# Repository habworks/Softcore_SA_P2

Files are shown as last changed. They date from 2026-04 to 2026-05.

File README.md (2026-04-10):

# SoftCore SA Phase 2

A complete Signal and Audio Spectrum Analyzer Project design based on the Xilinx Artix A7 FPGA.<br>
FPGA, Hardware and Firmware 100% designed by:<br>
Hab Collector<br>
Principal Engineer<br>
IMR Engineering, LLC<br>

## Quick Links to IMR Cloud:
See [Video Demo](https://imrengineeringcom-my.sharepoint.com/:v:/g/personal/hab_collector_imrengineering_com/IQCNRXcKcpunQ4q-7LwDUr22AYgADxUZiHp8gwkplrM7jkg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) from IMR Cloud<br>
See [FPGA PL Block Diagram](https://imrengineeringcom-my.sharepoint.com/:b:/g/personal/hab_collector_imrengineering_com/IQCsjQ4P0sn3SLZj1Wicb67OAVSCE_0235o4riHvLBb0ygI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) from IMR Cloud<br>
See [User Manual & Technical Specification](https://imrengineeringcom-my.sharepoint.com/:b:/g/personal/hab_collector_imrengineering_com/IQB8uARxVN-PTYQCG0TAuSPwAWNce-_PQCCQfAmf1itzjjY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) from IMR Cloud<br>
See [Schematics PCB and BOM](https://imrengineeringcom-my.sharepoint.com/:b:/g/personal/hab_collector_imrengineering_com/IQB8uARxVN-PTYQCG0TAuSPwAWNce-_PQCCQfAmf1itzjjY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) from IMR Cloud<br>

## Project Folders:

| Folder | Description |
|---|---|
| Audio | PCM-16 files used for audio spectrum playback|
| Bootloader_Softcore_SA | Firmware Project Bootloader|
| Documents | UMTS, Images, and reference material|
| FPGA_RTL_IP | Custom RTL IP created in Verilog for this project|
| Hardware | Hardware Design in Circuit Studio: Schematics, PCB, BOM|
| PL_Softcore_SA | Processor Logic Vivado Project Files|
| PS_Softcore_SA | Application Firmware|
| Simulation | Spice Modle Simulation (LT Spice)|

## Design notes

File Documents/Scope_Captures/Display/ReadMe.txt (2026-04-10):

tek00042.png

SPI Display Interface
Clk = 10MHz
CS
Clk
MOSI
Reset
Data/Command (Data High)
Typical screen buffer write 3.77ms

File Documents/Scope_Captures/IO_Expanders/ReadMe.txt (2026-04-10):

tek00036.png
This shows typical IO 1 Expander write in this capture LED7 U1.16 GP6 is driven high

tek00037.png
This shows the output latch being updated IOX 1

tek00041.png
Shows IO X generating an interrupt on a UI pushbutton SW2 and the corresponding read of the interrupt register

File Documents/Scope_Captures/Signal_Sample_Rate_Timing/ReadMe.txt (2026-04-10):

Sequence of events flows from top to bottom CH2 then CH1 then CH3 then CH4

CH 1 PL Timer 1 Interrupt goes active - it is cleared by the corresponding ISR
CH 2 PS Shows ISR response to PL Timer IRQ when it starts (high) and when it is completed (low) - part of what it does is start a single conversion cycle
CH 3 PL Shows the ADC 7476A x2 IRQ go active - it is cleared by the corresponding ISR
CH 4 PS Shows the ISR resonse to the PL ADC 7476A x2 IRQ when it starts (high) and when it is completed (low) - By the end of this you have started an ADC cycle and read the result

Cursor: The cursor shows how long the entire process takes and ultimately how fast a sample rate the current architecture can handle 74KHz but with some breathing room I use 50KHz
for the this architecture, but quite possible to use up to maybe 70KHz - but did not test.

the system architecture would have to change to get faster sample rate

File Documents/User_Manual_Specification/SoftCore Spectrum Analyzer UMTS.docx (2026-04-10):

SOFTCORE SPECTRUM ANALYZER

IMR Engineering, LLC

Ideas Made Real

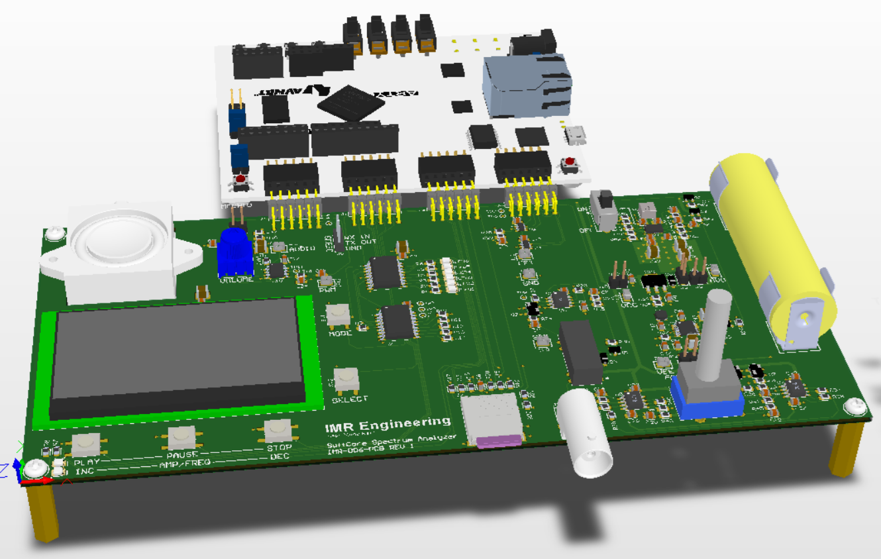
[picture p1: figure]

USER MANUAL AND TECHNICAL SPECIFICATION

Principal Engineer: Hab Collector

http://imrengineering.com

DOCUMENT REVISION HISTORY
DATE | DESCRIPTION | EDIT BY
2026-03-06 | Initial draft - Preliminary | HSC
2026-03-14 | Updated formatting and sample jitter | HSC
2026-03-23 | Final edits before publishing P1 content | HSC

# 1. INTRODUCTION:

## 1.1 THE CHALLENGE:

For many applications the microcontroller (µC) architecture provides an excellent balance of performance, cost, and manageable development complexity. It is therefore natural to ask an important engineering question: where does a pure Processor Logic (PL) based FPGA system fit into this landscape?

In comparison there is nothing easy, cheap or quick about an FPGA. The FPGA simply cannot compete in those categories, but for everything else it excels. The challenge explored in this project is not a feature-for-feature comparison between an FPGA and a µC. Instead, the goal is to explore the practical capabilities of a pure PL FPGA platform by implementing two distinct design projects and observing how such a system compares in practice to what might traditionally be implemented on an ARM Cortex M4/M7 class device or higher.

The first phase (P1) of this exploration focuses on constructing an FPGA-based system that resembles the functional architecture commonly found in a µC environment. Within the PL, a subset of needed peripherals are implemented which include: UART, SPI, DDR3, Timers, PWM, Interrupt Controller, FPU, Cache memory and other system services required to support a complete embedded application. The resulting system demonstrates that the fundamental building blocks normally associated with a µC can be tailored specifically to create the device needed. That said, incorporated into this first phase a preview of what lies ahead through the inclusion of two custom RTL-based IP blocks (aka modules) – something you cannot do within a µC along with a few other FPGA differentiators.

## 1.2 PHASE 1 / PHASE 2:

What is covered here is the P1 project design: PL, Hardware, and Firmware. In doing so I will show performance and limitations thereof, things I got wrong, and issues in hardware, firmware, and PL I intend to correct, and or, address in Phase 2.

## 1.3 SO WHAT IS IT:

A dual mode Spectrum Analyzer (SA) implemented around the MicroBlaze Softcore IP processor running on the AMD (aka Xilinx) XC7A100T-1CSG324-1 FPGA. As this FPGA is pure PL there is no PS (Processor System) as in the case of SoC based FPGAs. The system architecture recreates many of the services typically found in a microcontroller environment while remaining entirely within the FPGA PL fabric. The user interface is intentionally simple, and hardware driven, consisting of five multi-function push buttons and a monochrome 128x64 graphical display used for system control and visualization. The device operates as a compact, self-contained instrument designed to demonstrate real-time spectral analysis. The project currently supports two modes of operation: Audio SA (referenced in FW as Audio_SA) and Signal SA (referenced in FW as Signal_SA). Audio Mode displays the spectral content and signal strength of a WAV audio file played from µSD. Signal Mode mimics the behavior of a desktop Spectrum Analyzer.

# 2. AT A GLANCE:

## 2.1 PL FEATURES:

- MicroBlaze Softcore:

64KB / 32KB of Instruction / Data Cache, FPU and 128KB of LBM

- 3x Timers (two with interrupts)
- PWM
- 1x SPI shared to 3x devices: 2x IO Expanders and 1x SSD1309 Display
- 1x SPI dedicated to µSDB
- 1x SPI dedicated to 16MB QUAD SPI Boot Flash – Bootloader use only
- UART
- DDR3 Interface to external 128Mx16 (MT41K128M16XX-15E)
- 11x GPIO Outputs
- 12x GPIO Inputs
- Custom RTL Revision IP
- Custom RTL ADC Interface IP
- Interrupt Controller with 3x Fast Interrupts
- System Bus Interconnect

## 2.2 HW FEATURES:

- IO Expander to LED outputs
- IO Expander to UI push button Inputs
- Micro-SD
- 128x64 2.42” OLED Display
- Dual 12b 1MSPS ADC
- Anti-Aliasing Sallen Key LPF
- Selectable Analog inputs to Signal SA
- Local Variable Oscillator 4.4K to 48.2KHz
- Class AB Audio Amplifier
- Single Li-ION cell operation
- Interface to Digilent Arty A7 Development board

## 2.3 FW FEATURES:

- Bear Metal Application
- Middleware: FAT FS Library
- Middleware: U8G2 Graphics Library
- Middleware: KISS FFT Library
- Two modes of operation: Audio and Signal

## 2.4 SIMPLIFIED BLOCK DIAGRAM

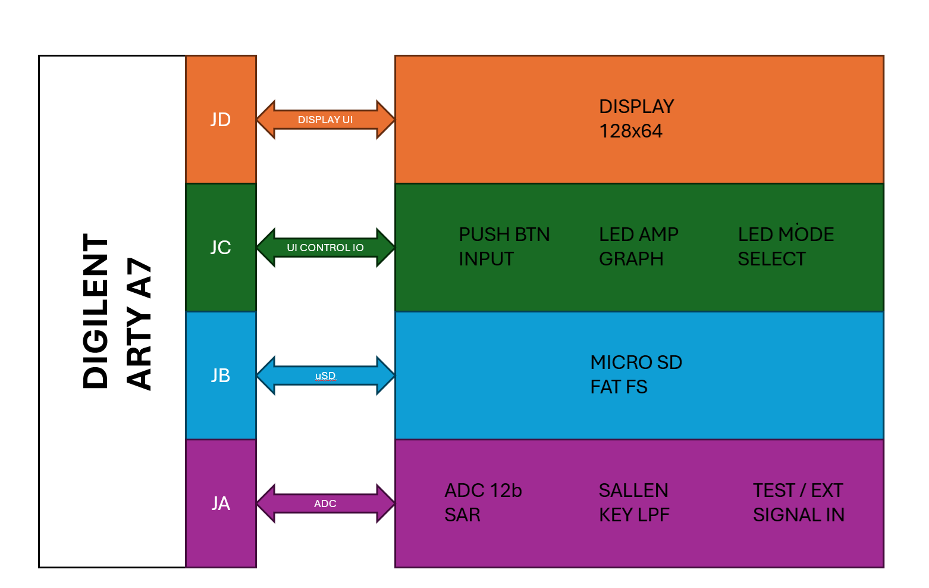
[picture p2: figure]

# 3. PROJECT SCOPE:

When creating a two-part project of such hardware and firmware complexity, as a one-person show, limiting scope is necessary to ensure time, budget and project momentum are kept.

## 3.1 P1 FIRMWARE SCOPE:

For firmware I decided to implement a bear-metal application rather than an RTOS. It limited FW complexity for one, but it also availed the processor of the memory and processing time needed to support an RTOS. The choice of KISS FFT pre-existing library was also necessary as a custom FFT library would be a project on to itself.

## 3.2 P1 HARDWARE SCOPE:

The complexity of layout for a DDR3 memory and the layer count associated with such a design from a cost and time perspective made the choice of using the off-the-shelf Digilent Arty A7 Development Board an easy one. Having designed both FPGAs and DDR3 memories before I knew ahead of time I was looking at 3 revisions of a 6 layer PCB. More so, I have chosen not to extend my Altium license moving forward, the need for trace impedances and serpentine routing neither of which is supported by Circuit Studio (development tool used). For the same reasons the choice of a simple display was made over an RGB color model.

# 4. DETAILED MODES OF OPERATION:

- Audio Spectrum
- Signal Spectrum

## 4.1 AUDIO SA MODE DETAILS:

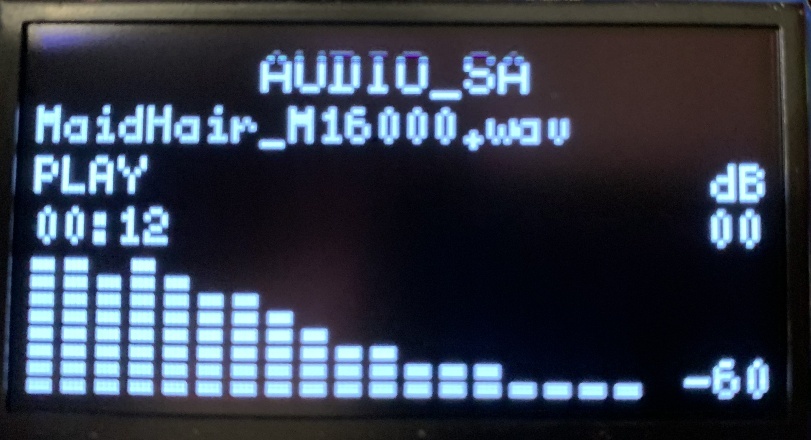
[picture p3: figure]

In Audio SA mode the system operates as a real-time audio playback and spectral display instrument. Audio content is read from a WAV file stored on the µSD card using the FAT FS middleware. Once the file header is parsed and verified, audio sample data is moved from storage into a large streaming circular buffer sized at 22K samples / 44KB (int16_t data). This large, main buffer exists to reduce the frequency of µSD card read operations and to provide margin against storage access latency. For this streaming buffer the system fills a smaller, secondary 4KB feed buffer which serves to replenish the larger buffer. In this way the buffering scheme is staged: mass storage feeds the main streaming buffer on start, thereafter the main buffer is feed from the secondary buffer as space becomes available, as the main buffer supports both playback and FFT processing (FFT is processed by the KISS FFT middleware). The buffer is sized to support a max audio sample of 22050Hz playback. It could have been sized larger, but I choose to limit the size here, with planned use of that memory in phase 2. Additionally, six colored LEDs (arranged as a bar) display the magnitude (signal strength no signal spectrum) of the playback from -30dB to -10dB in -4dB increments. Both the spectral display and the signal strength LED bar will provide a visual interpretation of the payback audio.

Playback timing is controlled by a timer interrupt service routine (ISR) configured to run at the audio playback sample rate. For a playback rate of 16KHz, the ISR period is:

T_(sample) =1/16000=62.5 μs This means one audio sample is processed every 62.5µs. As playback proceeds, samples are simultaneously routed to the PWM audio output path and copied into the FFT sample buffer. The FFT sample buffer contains 1024 samples, therefore the time required to fully populate at 16KHz playback is:

T_(FFT Fill) =N/(Fs)=(1024/16000)= 64 ms

Thus, under continuous playback, a new 1024-point FFT frame becomes available every 64ms. This corresponds to an FFT update rate of:

1/0.064=15.625 Hz or approximately 15.6Hz spectral updates per second. As an additional reference, the 4KB feed buffer holds 4096 bytes. For 16-bit PCM audio, each sample is 2 bytes, giving:

4096/2=2048 samples At 16KHz playback this secondary buffer represents:

2048/16000=128 ms of mono audio data. Likewise, the 44KB streaming buffer holds:

44056/2=22528 samples

which at 16KHz corresponds to:

22528/16000=1.408 s

or about 1.4 seconds of mono playback data. These staged buffer depths are what allow playback, storage access, and FFT processing to coexist with acceptable continuity.

Interrupt handling is a significant part of the design – its importance cannot be overstated for this project. As such I take a moment to expand upon it here. Both modes rely heavily on the sample rate interrupt timer (AXI Timer 1). The MicroBlaze is capable of normal and low latency (fast) interrupts. Normal interrupts use the AXI interrupt controller and are decoded, prioritized and vectored to the processor. Normal interrupts take about 40 cycles between detection to ISR jump. Fast interrupts bypass the interrupt controller and connect directly to the MicroBlaze. Subsequently fast interrupts are processed within about 10 cycles, generally speaking, on par with ARM Cortex M4/M7. That said, most M4 and M7 designs clock in excess of 100MHz, so the actual time from detection to ISR jump and ISR processing is less. Part of the interrupt mechanism is architectural, and part is simply clock speed (cycle time): The P1 design runs at 100MHz. In P2 I will attempt to run the same design to 150MHz. A difference with a distinction. While µCs are typically specified with a fixed max clock speed, FPGAs come in speed grades -1, -2, -3 (slow, faster, fastest). Generally speaking, the speed grade represents a “possible” range of the max fabric clock frequency. At speed grade 1 it maybe possible to get a max of 200MHz. If this is repeatable across devices will be device and design dependent. That said, 100MHz is just a known starting point. Nesting, the MicroBlaze interrupt controller does not support a true nested interrupt model where one interrupt preempts another already in service, though it does support interrupt priority (fixed in the PL design). In this project that reality strongly influenced the overall firmware architecture, the selected FFT size, and the balance between playback, analysis, and display update rate. Lastly, all ISR are placed in (Local Block Memory) LBM (FPGA block RAM directly attached to the MicroBlaze – runs exceptionally fast) and not within DDR3 space. The overall size of the application dictates that most of it runs from DDR space, targeting LBM for specific use where speed is paramount. Another distinction here is the FPGA application runs (mostly) from DDR and LBM memory, whereas with the µC the application runs from FLASH. The FPGA requires a far more complex linker – the reader is encouraged to review the application linker file (lscript.ld) with the Virtual Address Memory (VAM) and Local Address Memory (LAM) and how its loaded at run-time.

## 4.2 SIGNAL SA MODE DETAILS:

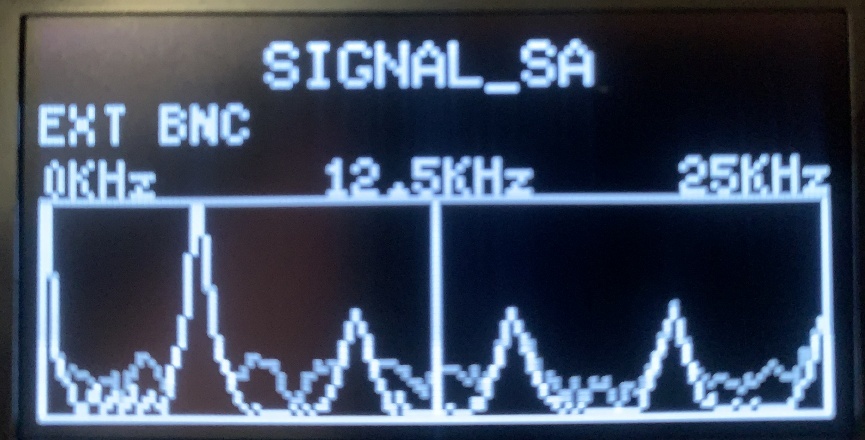
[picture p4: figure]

In this configuration the instrument functions as a traditional Spectrum Analyzer by converting incoming time-domain signals into its frequency-domain representation. While the sampling data differs from Audio SA mode, the spectral analysis engine remains fundamentally the same. Both modes leverage the same FFT algorithm and the same 1024 samples per frame,

Signal acquisition is a two interrupt event. It begins with the sample-rate timer interrupt. Each timer interrupt event initiates the sampling sequence by triggering the custom ADC RTL IP to perform an ADC conversion. The ADC IP implemented in PL controls the timing of the conversion and provides the resulting digital sample to the firmware via a fast interrupt (the second). Within the ISR the sample is transferred into the FFT sample buffer, where samples are accumulated until the frame buffer (1024 samples) is full.

Once the frame is complete, the spectral processing routine is executed. During this time the Timer ISR is suspended. The resulting magnitude values represent the spectral energy distribution of the input signal and are mapped to the display. Once the display has been updated the ISR is resumed.

Input signals can originate from two sources. The onboard, variable Wien Bridge Oscillator (aka local oscillator - 4.4KHz to 48.2KHz) or via an external BNC connection. As with Audio SA mode, the entire signal acquisition and analysis pipeline is driven by the timer interrupt architecture. The interrupt establishes the sampling cadence, triggers ADC conversion, and governs the rate at which samples are collected for FFT processing. Consequently, the overall performance and responsiveness of the Signal SA system are fundamentally driven and limited by the ISR-based architecture.

Below shows the timing interactions:

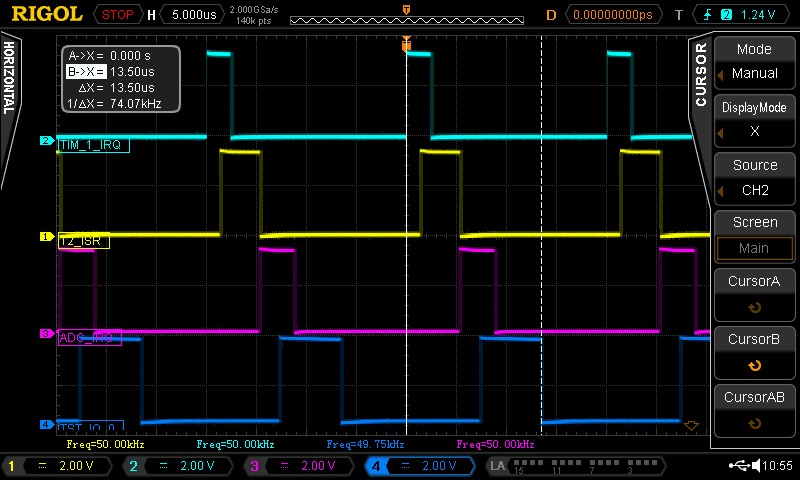
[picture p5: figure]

NOTES:
CH2 - TIM_1_IRQ: Timer 1 IP IRQ

CH1 - T2_ISR:

Timer 1 ISR handler (inniates Custom RTL ADC conversion)

CH3 - ADC_IRQ: Custom RTL ADC conversion complete IRQ

CH4 – TEST_IO_0: ADC IRQ ISR complete (the sample has been captured)

Cursor Marking: Shows the max frequency possible for sampling about 74KHz – choose 50KHz for sampling frequency.

As the above timing analysis shows the max sample rate possible using this architecture resolves to an absolute maximum of 70KHz (allowing some wiggle room from the 74KHz). With the 100KHz out of reach for phase 1 I settled on a sample rate of 50KHz, which implies a usable frequency BW of 25KHz. Note the local Wien Bridge Oscillator variable range was designed to be the intended 100KHz sample rate and 50KHz BW (4.5KHz to 48.2KHz).

# 5. FFT IMPLEMENTATION AND NEED TO KNOW:

## 5.1 FFT PROCESS FLOW:

In essence the FFT categorizes the sampled time-domain signal into spectral energy between the baseband and the Nyquist. Because the FFT works on a finite number of samples (frame), the result is always tied to one snapshot in time. In this design, that snapshot is 1024 samples. Every time that frame becomes available the FFT is processed and can subsequently be displayed.

## 5.2 WHAT CAN BE MEASURED:

The system takes 50,000 equally spaced samples every second. That sample rate creates a hard upper limit on what can be correctly processed by the FFT. As the Nyquist is 25KHz, spectral content above 25KHz represents an aliasing error. Higher frequency content feeding into the ADC folds back into the measure band and appears as an incorrect lower frequency – the aliasing effect. The intent was for the anti-aliasing filter to reject said frequencies. That said, the ADC front end Sallen-Key LPF was designed for this purpose with a BW of 330KHz. At the time, the expectation was that the local Wien Bridge Oscillator would be “clean” and the 330KHz (-40dB/decade roll-off) would allow for some limited Phase 2 development on the same Phase 1 hardware platform. I was wrong about the local oscillator being clean. Another thing I failed to realize at the time was that harmonic content beyond the BW limit would also alias back. The aliasing error follows the form:

Fa=abs(Fin-kFs)

Fa: Alias frequency

Fin: Input frequency

Fs: Sample frequency

k: Integer multiple until Fa falls in the Nyquist band

Observed Example of Alias Content 1:

Fin = 120KHz

Abs(120KHz – (1)(50KHz)) = 70KHz (not within Nyquist so will not be displayed

Abs(120KHz – (2)(50KHz)) = 20KHz within Nyquist so it will be displayed

Observed Example of Alias Example 2:

Fin = 90KHz

Abs(90KHz – (1)(50KHz)) = 40KHz (not within Nyquist so will not be displayed

Abs(90KHz – (2)(50KHz)) = 10KHz within Nyquist so it will be displayed

Observed Example of Alias Example 3:

Fin = 35KHz

Abs(35KHz – (1)(50KHz)) = 15KHz within Nyquist so it will be displayed

Lastly, it is important to understand that the alias frequency is NOT an error of the FFT, but rather a limitation of the front-end anti-aliasing filter, which at its high -3dB limit does not reject frequencies above the implemented sampling rate. As can be seen from the spectral plots below, the local oscillator created spectral energy beyond both the implemented and (initially) intended sample rate. That energy is believed to have been caused by the clipping diodes in the feedback circuit. This phenomenon was observed with the device operating in Signal Spectrum Mode with the local oscillator tuned within the Nyquist range. As demonstrated below, there was higher-frequency content present in the Wien Bridge oscillator beyond the desired fundamental. Because the anti-aliasing filter cutoff frequency was set too high, those higher-frequency components were allowed to reach the ADC and were subsequently manifested in the displayed spectrum.

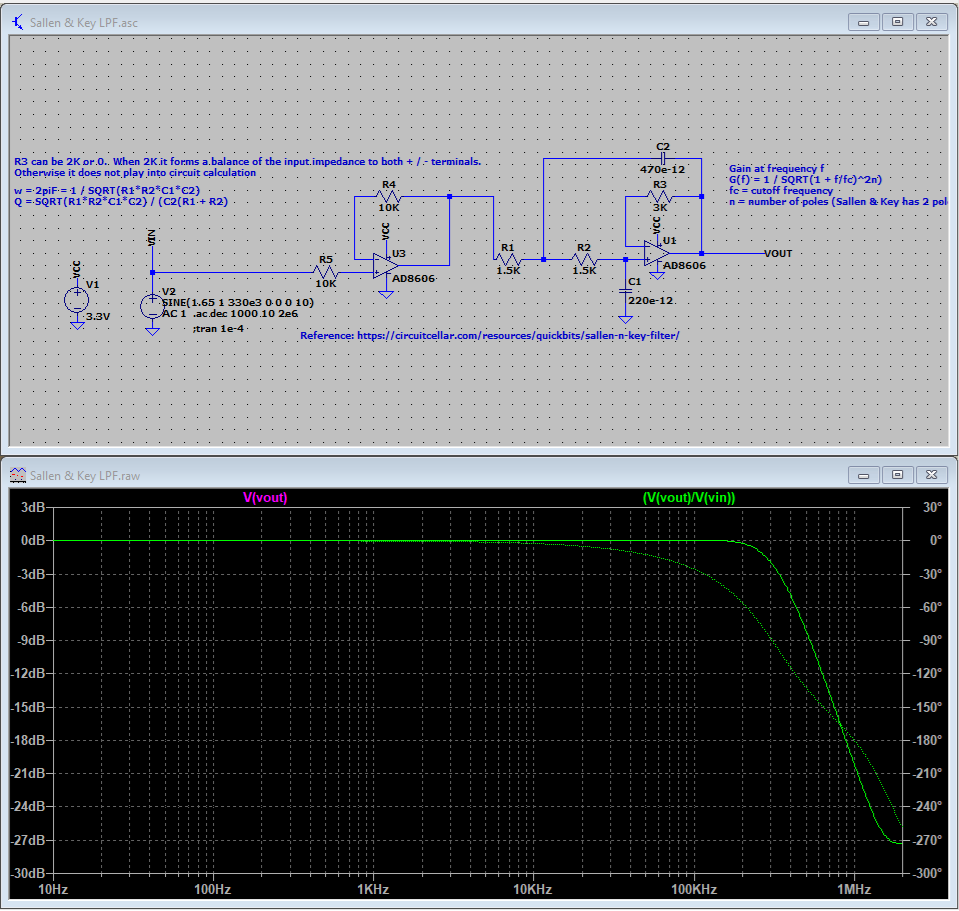
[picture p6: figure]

Spice Simulation of Anti-Aliasing Filter

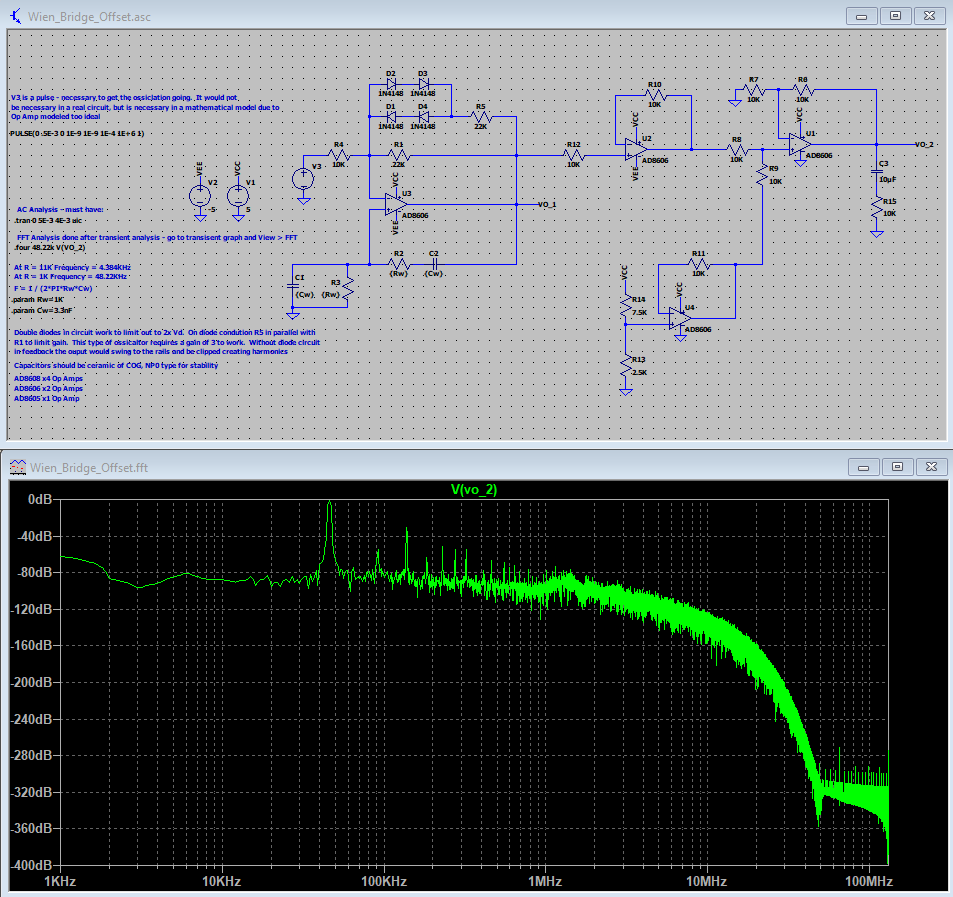
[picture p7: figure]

Spice simulation showing spectral response of local osscilator (Hanning Window Applied)

## 5.3 SIZE BINS AND RBW:

FFT size tells you how many samples per frame. In this design the FFT size is 1024 (1K). The FFT output is divided into bins. Each bin represents one narrow frequency slot. For a real-input FFT only the non-negative half of the spectrum is unique, so the useful output consists of bins 0 through FFT_Size / 2 (512), with bins 0 (DC offset) and bin 512 (Max BW) being unique. Bins 513 to 1024 represent the Complex Conjugate (CC) of the first half and subsequently mirror the first half in magnitude. With Bin 513 the CC of bin 511, bin 514 the CC of bin 510, etc. The frequency width of each bin is the Resolution Bandwidth (RBW). It is set by sample rate divided by FFT size. With a 50,000 Hz sample rate and a 1024-point FFT, the RBW for this project is 48.828Hz (per bin). Bin 1 is centered on 48.8 Hz, bin 10, 488.3 Hz, bin 100, 4.883 kHz, and so on. A smaller RBW gives finer spectral detail because bins are narrower, however with a finer RBW comes more processing and with it, slower updates. Lastly, the DC and low frequency content of the signal is contained in Bin 0 and Bin 1 (50 / 60Hz). As such I deliberately omit bin 0 content from being displayed as it is likely to be quite large and may not be what the user expects to see.

## 5.4 WINDOW FUNCTION:

FFT computations assumes that the frame repeats indefinitely and in-sync. In other words, each sample index within a frame is assumed to match the corresponding index in the frame before and after it. Stated differently, the FFT assumes there is no discontinuity between frames, and that the signal begins at the same point in each frame.

In practical application this is almost never the case. As such, a “window function” is applied to the sample data. As the frame to frame transition does not repeat, the window function tapers the beginning and end of the sampled data so the FFT does not see a spike / discontinuity / sudden jump when the record repeats. That discontinuity is Frame boundary discontinuity. Additionally, the window function provides a smoothing operation across adjacent bins should a given input frequency not fall on an exact RBW bin interval. For example, with a RBW of 10Hz and an input frequency of 15Hz – the window serves to spread energy across 10Hz and 20Hz bins. There are many Window functions to choose from. This project uses the Hanning Window. Computationally the Hanning Window:

Window[Index]=0.5(1-cos((2π(Index))/(N-1)))

Window[Index] = Window Index Coefficient

N = FFT Size

Index = Sample Index (0 ≤ Index ≤ (N – 1))

Mathematically the Window function is applied across the frame data as such: FF

FFT_(Data[Index]) =FFT_(SampleData[Index]) ×Window_(Function[Index])

For computational speed the Hanning Window is calculated once at POR.

## 5.5 SAMPLE JITTER – THE PHASE ERROR:

Sample timing jitter manifests itself in phase noise. The more of less of it present raises or lowers the noise floor of the displayed spectrum and can manifest itself as “jumpiness” in the display. Phase error is fundamentally caused by sample to sample timing variations (jitter), but, and in the case of this P1 application, the effect is more apparent due to the FFT computational processing and display (Frame to Frame).

Unlike Audio SA Mode, in Signal SA Mode the FW is architected such that after each frame is acquired (via ISR timing), the acquisition is paused, the data processed and display updated, then acquisition is resumed. The processing and updating of data (timing delay) creates the phase offset (error) between successive frames. Because this timing offset repeats every frame, it manifests as phase variation in the sampled signal and contributes to visible instability in the displayed spectrum. This architectural limitation will be addressed in Phase 2.

## 5.6 HARMONICS:

A perfect sine wave contains only one frequency - the fundamental. As perfection is hard to find in real life for everything else there are harmonics. Harmonics are integer multiples of the fundamental. Any nonlinearity in the signal path can reshape the waveform. Clipping, asymmetric biasing, saturation, crossover distortion, and nonlinear amplifiers all impact waveform shape. The FFT reveals that shape change as harmonic energy. Lastly, any given waveform can be a composite of multiple fundamentals.

Odd harmonics are often associated with distortions that preserve waveform symmetry about its midpoint (zero). In this case, the top and bottom halves of the waveform look the same. For example, a sine wave that is clipped equally on both the positive and negative peaks preserves this symmetry. A square wave is the typical example and contains strong odd harmonics. Even harmonics increase when the waveform becomes asymmetric about zero. In other words, the bottom half of the signal does not mirror the top half. One example would be clipping of a sine wave but only on the positive or negative side, not both. That said, real-world signals typically contain both odd and even harmonics. The point here is that the ADC subtraction used to center the signal only removes the DC offset and therefore only impacts Bin 0 of the FFT. It does not alter the harmonic content of the signal.

The practical lesson is simple: when you see harmonic peaks, the FFT is telling you something about waveform shape and system linearity, not just frequency. The fundamental says where the signal is. The harmonic pattern says how clean or distorted that signal is. This phenomenon can be observed with the device in Signal Spectrum Mode. I said all of that to say the anti-aliasing filter created a discontinuity at 0V when using the external signal generator via the BNC connector, but not so when using the internal local oscillator. In either mode, by using persistence on the scope, it can be seen additional frequency content has been added at the filter output, though my desktop SA instrument confirmed this content well beyond the BW of the Signal SA Mode. I suspect, but did not confirm, this is caused from the SAR ADC that it feeds. Note the signal generator has a stated THD of less than -55dBc, from the spice simulation of the local oscillator we see its THD is far more than that. See sections ANTI-ALIASING FILTER DISCONTINUITY AT THE 0V: and WHAT CAN BE MEASURED: Something to be addressed and corrected in P2.

The input signal, via the local oscillator or the external BNC has an intended minimum of 0V. This was purposely designed to simplify input protection and to support the intended development flow (implementing features incrementally and verifying operation step by step). In Signal SA Mode, the ADC output is centered digitally. The ADC is 12-bit, so its midpoint occurs at 2048 counts. To create a zero-centered signal, 2048 is subtracted from each sampled value, effectively shifting the midpoint to zero. This results in a signal representation containing both positive and negative values.

Because the analog input signal itself can only be positive, this centering operation also removes the DC offset inherent in the sampling method. However, if the input signal is offset slightly above or below the expected midpoint, the simple subtraction of 2048 will not fully remove the DC component. Any remaining DC content appears in Bin 0 of the FFT. The Audio SA Mode does not suffer from this issue because the audio samples are stored as PCM16 (signed 16-bit) values, which are already centered around zero. In this sense, subtracting the ADC midpoint removes the DC offset associated with the unipolar input range. This operation affects only the DC component (FFT Bin 0) and does not alter the harmonic content of the signal. For this reason I do not display bin 0.

Total Harmonic Distortion (THD) is a measure of how much harmonic energy exists in a signal compared to the fundamental frequency. It quantifies the amount of distortion introduced by nonlinearities in a system. A perfectly linear system producing a pure sine wave would have 0% THD. As perfection is beyond our grasp, as distortion increases, the amplitudes of the harmonic frequencies increase relative to the fundamental. THD is typically expressed as a percentage or in decibels (dB).

The general form is:

THD(%)=100 × √((V2^2 +V3^2 +Vn^2)/(V1))

Where:

- V_1 = RMS voltage of the fundamental frequency
- V_2 ,V_3 ,V_4 ,… = RMS voltages of the 2nd, 3rd, 4th... harmonics

Not achievable within P1 because of the aliasing effects distorts heavily the calculation, but is intended for phase 2.

# 6. USER INTERFACE:

## 6.1 CONTROLS

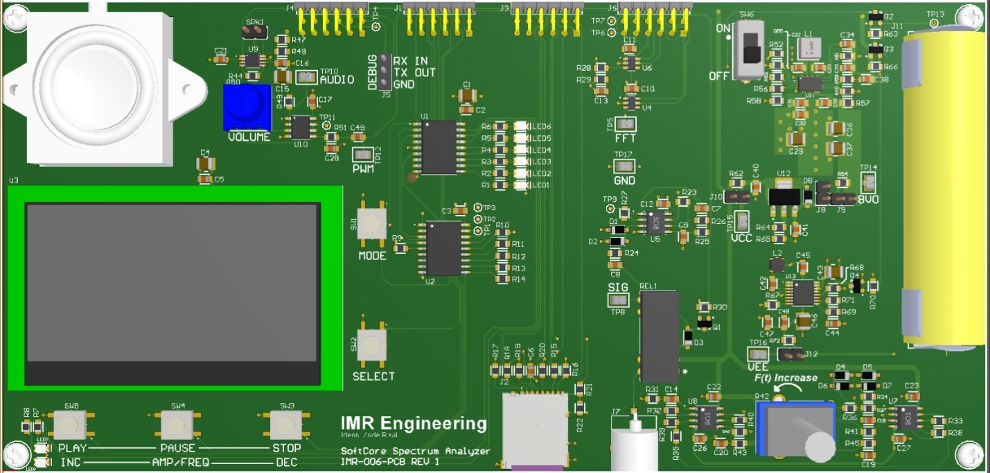
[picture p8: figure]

The UI interface consists of:

AUDIO SA:

- SW1: MODE: Toggles between Audio and Signal Spectrum Analyzer
- SW2: SELECT: Selects the next audio track
- SW3: STOP: Stop playing audio
- SW4: PAUSE: Pause the present audio playback
- SW5: PLAY: Play the selected track

SIGNAL SA:

- SW1: MODE: Toggles between Audio and Signal Spectrum Analyzer
- SW2: SELECT: Selects between local oscillator and external BNC
- ***As the observable BW is only 25KHz, 1/2 that of the original objective for phase 1, I saw no sense in elaborating on the controls to provide center, and span controls.

## 6.2 DEBUG PORT:

A serial, logic level, debug port (J5) is added with a standard: N 8 1 115200bps interface. The UI is color coded with Audio SA Mode in magenta and Singal SA Mode in Yellow. The debug port is output only for P1. TBD P2 may add user commands.

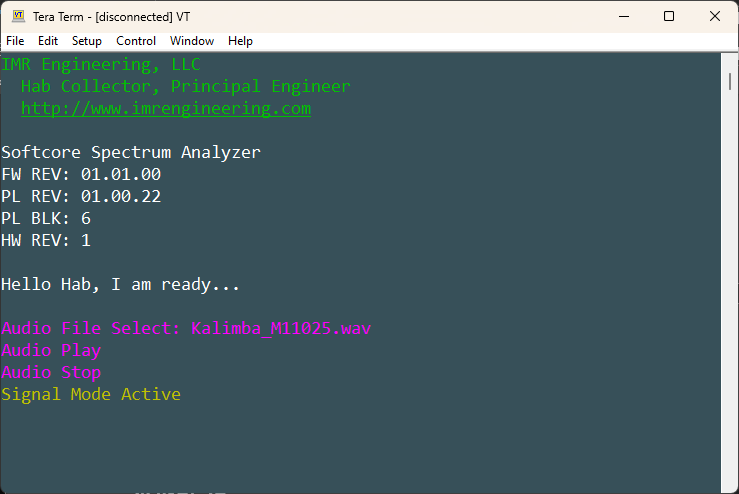
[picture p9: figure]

# 7. BOOT LOADER:

As with everything else, the bootloader process is made more complex with an FPGA. Every FPGA application requires a bootloader. You cannot just OTP program the FLASH. Unlike a µC, an FPGA program memory is not limited by the size of on chip FLASH, but rather the size of the external NV memory and DDR. The external memory can be just about anything. For Phase 1 a 16MB on board Quad SPI FLASH is used. That said, it could just as easily interface with the µSD, with the µSD providing the flexibility of changing the application just by changing the inserted µSD card.

An FPGA can facilitate an exceptionally large application; the application size is not limited by the FPGA but by the external NV and attached DDR. In the case of this hardware it is possible to support a 128MB application (DDR limitation). This external FLASH though large, holds far more than the application image. Contained within the external Quad SPI FLASH, and in this order from the base address:

- Hardware Image / Hardware bitstream (BD_Softcore_SA_wrapper.bit)
- Bootloader Image (MB_SSA_BL_App.elf)
- Application Image (MB_SSA_App.srec)

Another key distinction is that a microcontroller HW capabilities are fixed. The FPGA HW capabilities (PL) are completely flexible and loaded at POR, hence the need for the HW image. The HW image will typically be several MB depending on complexity (P1 image was about 3MB). At POR the PL is configured from the hardware bitstream, after PL configuration the bootloader executes from LBM to load the DDR with the application image and the Program counter loaded with the start of the application. Note, if the application were small enough it could have been loaded to LBM. That said, FW functions needed for fast execution were placed in LBM. With the Quad SPI Flash the images are “combined” to a common file .mcs – the .mcs is what is loaded.

The bootloader and the application share the same PL. A separate Quad SPI IP was added to support the external 16MB Quad SPI Flash. That additional interface is not used by the application. Like with a µC the bootloader is a separate application on to itself.

TBD P2 may instead use the µSD. The process is essentially the same, the difference being the use of the FAT FS on the µSD. Though larger and more complex, requiring the FAT FS library and file manipulation. The process is basically the same, just in three separate files: bitsteam, bootloader image and application image. Additionally, this bootloader is very slow. It takes about 2 minutes to load. The application image is stored in flash as an .srec file and as such is parsed line by line creating a very slow load. Perhaps for phase 2 I might consider the use of an elf file load – which should drop the boot time to seconds.

# 8. PHASE 2 LOOK AHEAD:

## 8.1 ENHANCEMENTS:

In phase two (to come), the focus shifts from “the FPGA can do that too” to “the FPGA can do so much more”. Rather than simply replicating µC peripherals, the design leverages capabilities that are inherently more flexible and impossible via a µC. Much of the infrastructure created in the first phase is reused and extended, allowing the system to evolve beyond a microcontroller-style architecture and into a PL hardware-accelerated signal processing platform. Key features of phase 2 include:

- Additional RTL IP:
  - Debounce
  - Async Synchronizer
  - Configurable FIFO with deep memory
  - ADC IP to Interleave ADCs and FIFO for high speed sampling
- Faster clocking of MicroBlaze
- Expanding RAM (currently 128KB expanded to 256KB)
- Signal digital down conversion (DDC: digital mixer + filter + decimation)
- Adjustable Span
- Expanded UI control with scroll wheel
- BW target in MHz range
- DMA

## 8.2 CORRECTIONS:

- Silk screen add dB rating to sound level bar
- PCB TH test points match size to probe pin
- Remove blocking capacitor at anti-aliasing front end or fix current leakage creating via diodes with no place to go because of blocking capacitor
- Volume pot footprint and orientation both incorrect
- Audio Enable and signal input needs pull-down
- Power supply corrections to: 8V SMPS, -5V SMPS, 5V LDO Regulator
- Anti-aliasing filter -3dB cut-off adjusted
- In Signal SA Mode with external BNC selected but no input drive the display reads the frequency as set by the LO – this shows the sensitivity of the SA as no measurable input is seen by the scope at the AA LPF output. Fixes may be in FW by adjusting the min dB value or more likely in HW disabling the local oscillator and PCB layout changes to avoid coupling.

# 9. TECHNICAL SPECIFICATIONS:

## 9.1 ABSOLUTE MAXIMUM RATINGS

ABSOLUTE MAX RATINGS
PARAMETER | CONDITION | Min | Typ | Max | UNIT

ENVIRONMENTAL
Operating Temperature | | -20 | | 30 | oC
Storage Temperature | | -40 | | 85 | oC
Relative Humidity | Non-condensing | | | 97 | %

SINGLE CELL SUPPLY
+VS Supply rail | | 3.4 | 4.2 | | V

EXTERNAL BNC INPUT
Input | | -0.5 | 3.0 | 3.8 | V

## 9.2 OPERATIONAL RATINGS:

OPERATIONAL SPECIFICATIONS
PARAMETER | CONDITION | Min | Typ | Max | UNIT

ENVIRONMENTAL
Temperature | | -20 | | 30 | oC
Relative Humidity | Non-condensing | 0 | | 95 | %

PHYSICAL DIMENSIONS
Length | | | 210.0 | | mm
Width | Does not include connectors | | 100.0 | | mm
Height | Lowest to highest measure wo post | | 15.0 | | mm

RUN TIME
Audio SA mode in playback | 3.3V audio amp / 3200mAH cell | | | 160 | min
Signal SA or Audio SA (no audio) | 3200mAH cell | | | 213 | min

AUDIO SA
WAV File Type | PCM | | 16 | | bit
Audio Sample Rate | | 8 | 16 | 22.05 | KHz
Max Volume (Measured at .5m) | 3.3V Class AB audio amp power | | | 69 | dBA
PWM Frequency | | | 100.00 | | KHz
PWM Audio LPF | -3dB | | 20.03 | | KHz

SIGNAL SA
Input frequency | | | | 25 | KHz
Input Signal Voltage range | No output loading | 0 | 3 | 3.1 | V
Impedance | | | 1M | | Ω
FFT Sample Rate | | | 50 | | KHz
RBW | | | 48.828 | | Hz
Aniti-Alasing Filter cut-off | -3dB | | 329.9 | | KHz

# 10. TIMING

## 10.1 IO EXPANDERS:

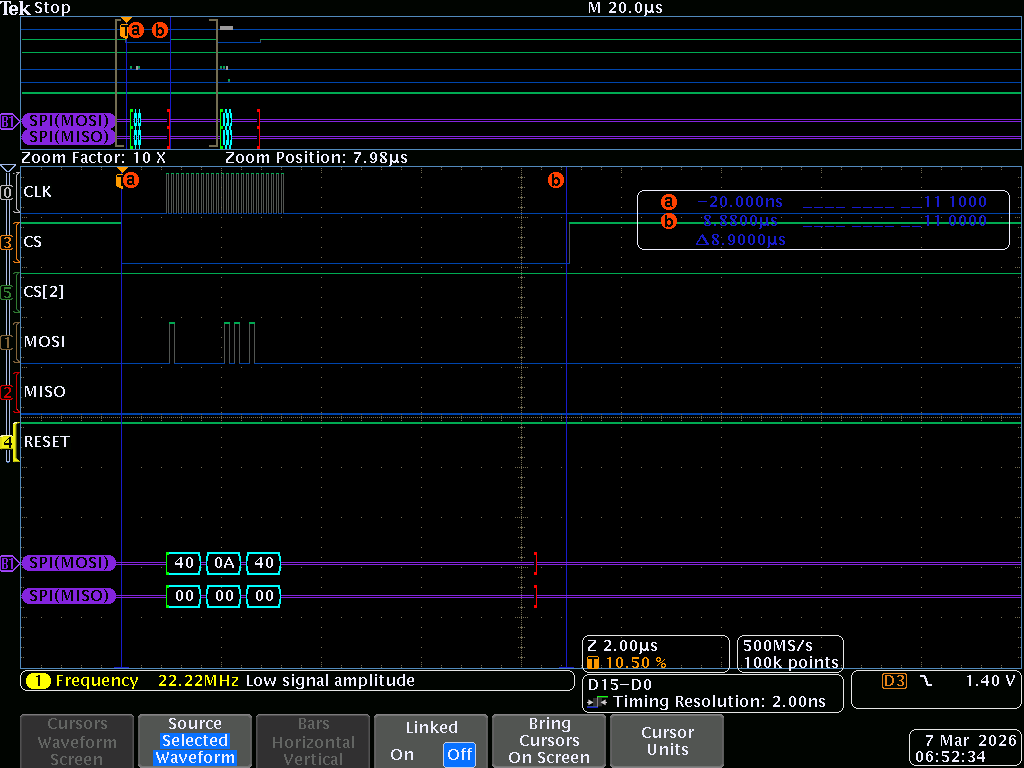
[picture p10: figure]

Typical IO Expander 1 write (U1.16 GP6 driven high) (CLK = 10MHz / Time ≈ 8.9us)

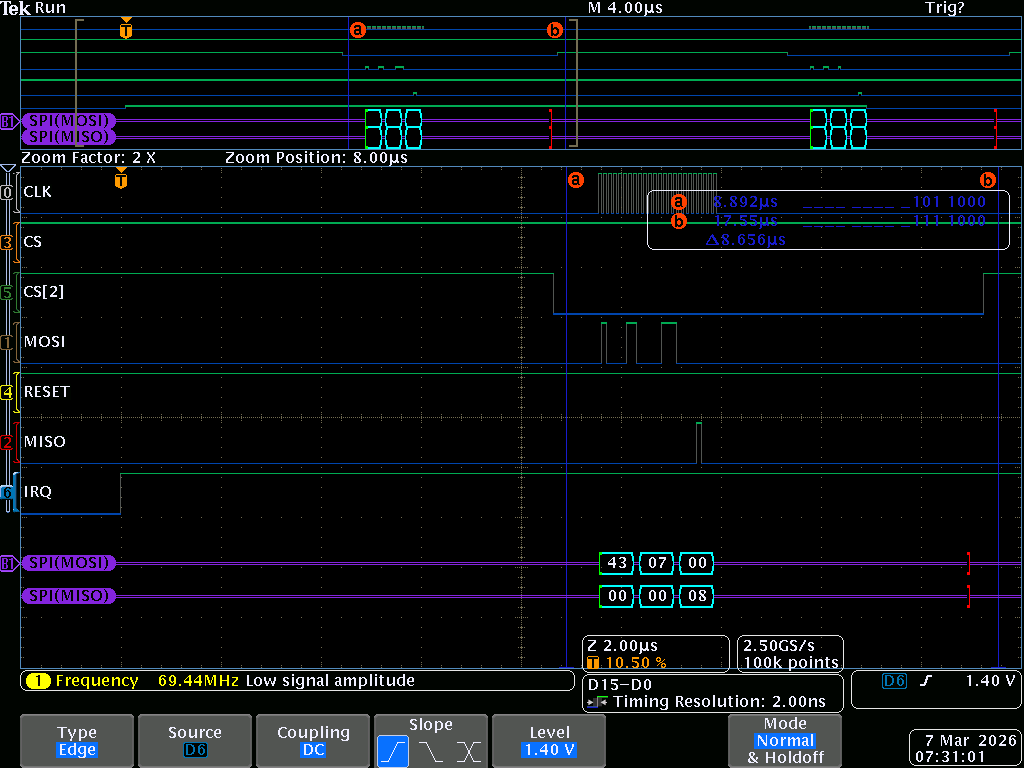
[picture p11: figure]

Typical IO Expander 2 generating an IRQ on input (U2.14 GP3 driven high) (CLK = 10MHz / Time ≈ 8.9us)

## 10.2 DISPLAY (SSD1309 CHIP SET):

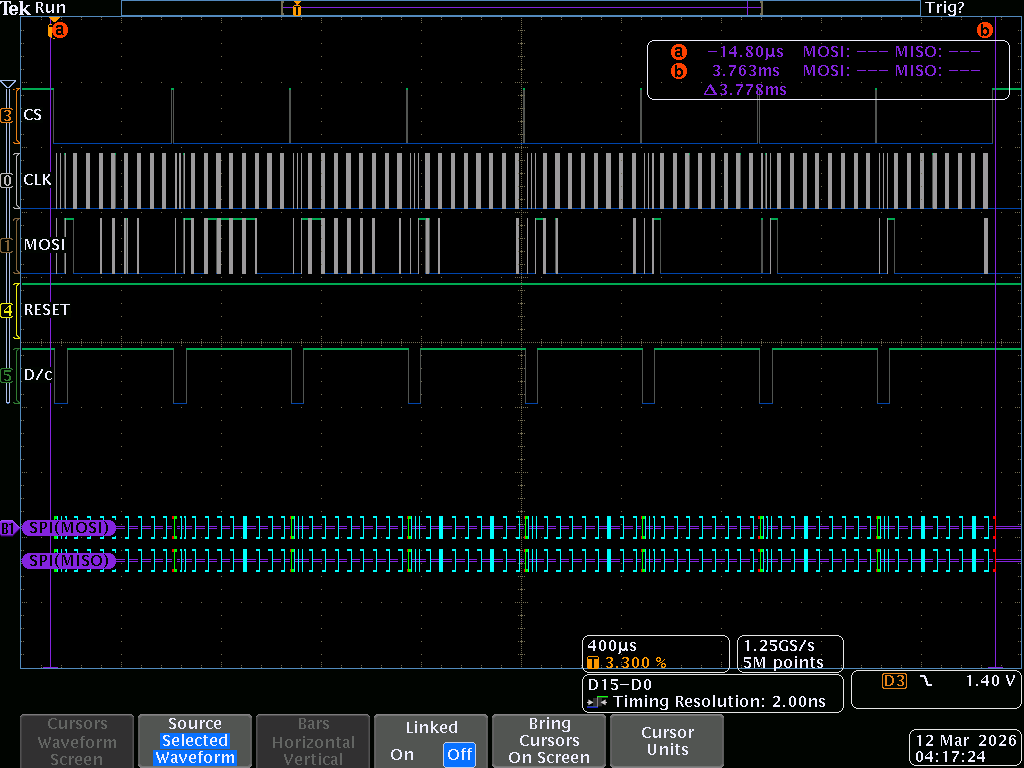
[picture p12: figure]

Typical screen buffer write (D/c = Data = 1 / Command = 0) (CLK = 10MHz / Time ≈ 3.8ms)

## 10.3 uSD DATA TRANSFER

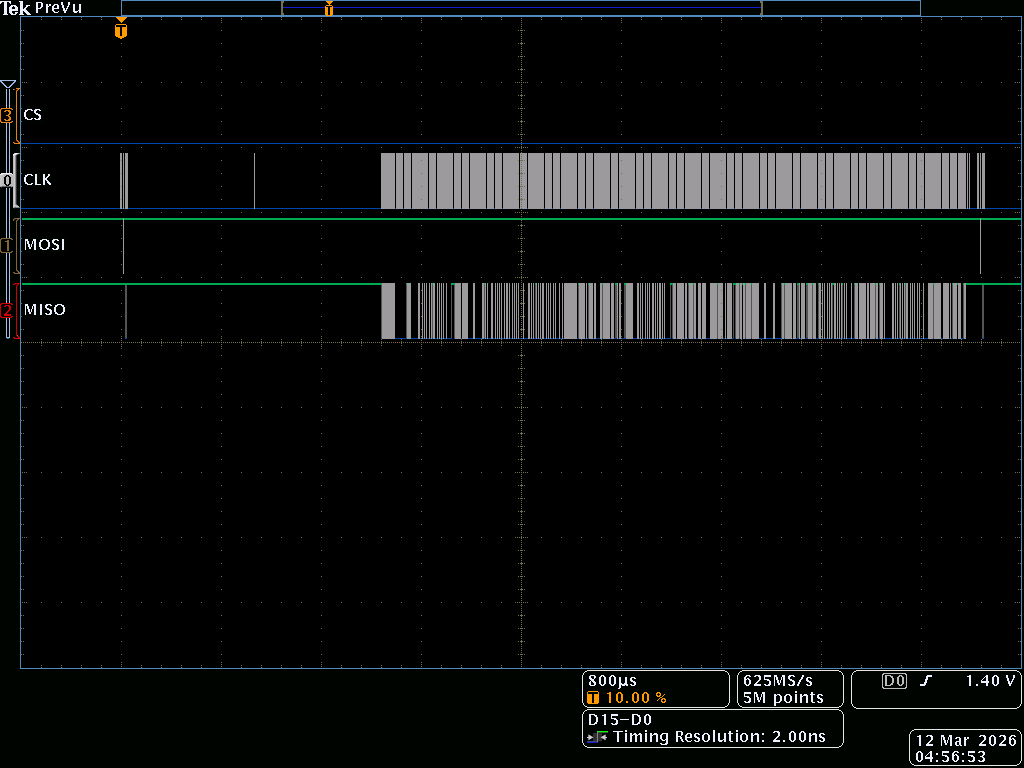
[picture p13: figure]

Data transfer during start of stream (CLK = 25MHz)

## 10.4 ANTI-ALIASING FILTER DISCONTINUITY AT THE 0V:

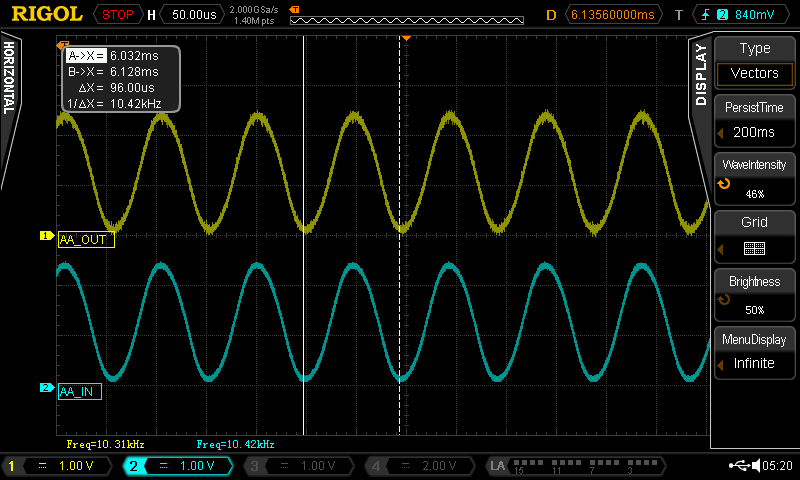
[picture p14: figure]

Local Oscillator – Anti-Aliasing filter output – notice no discontinuity around 0V

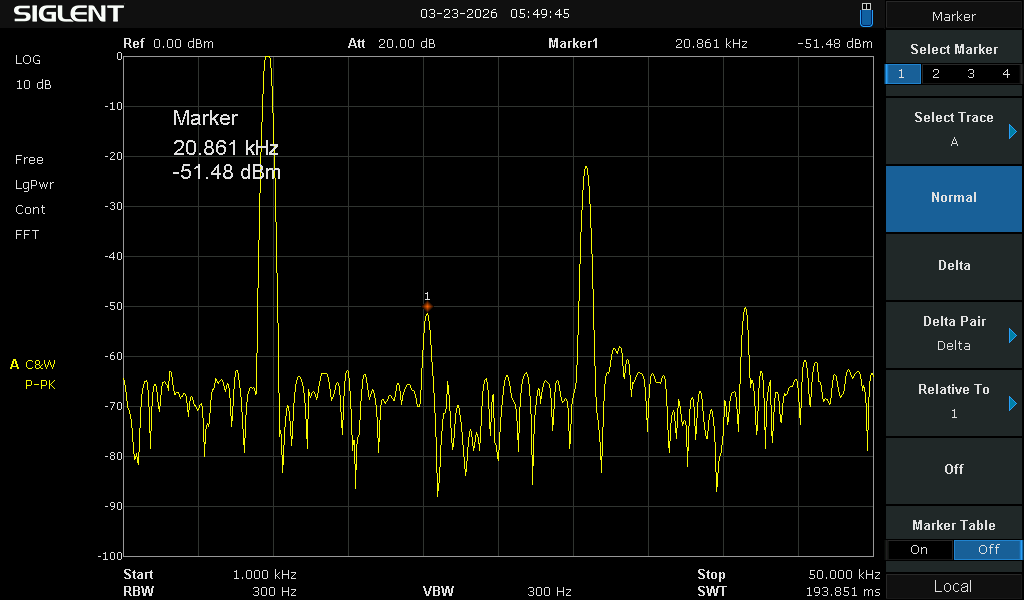
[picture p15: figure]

Local Oscillator – Anti-Aliasing filter output stronger even than odd harmonics

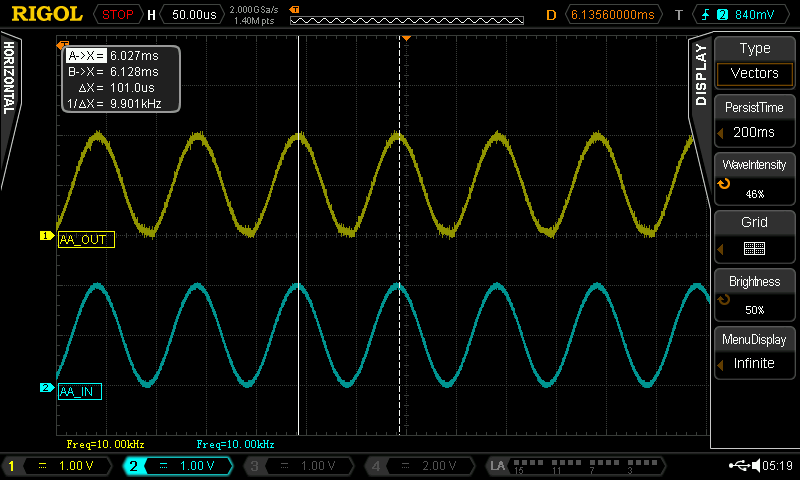
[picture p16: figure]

External BNC signal generator input with clipping about the 0V – clipping not present if min signal is raised to 130mV

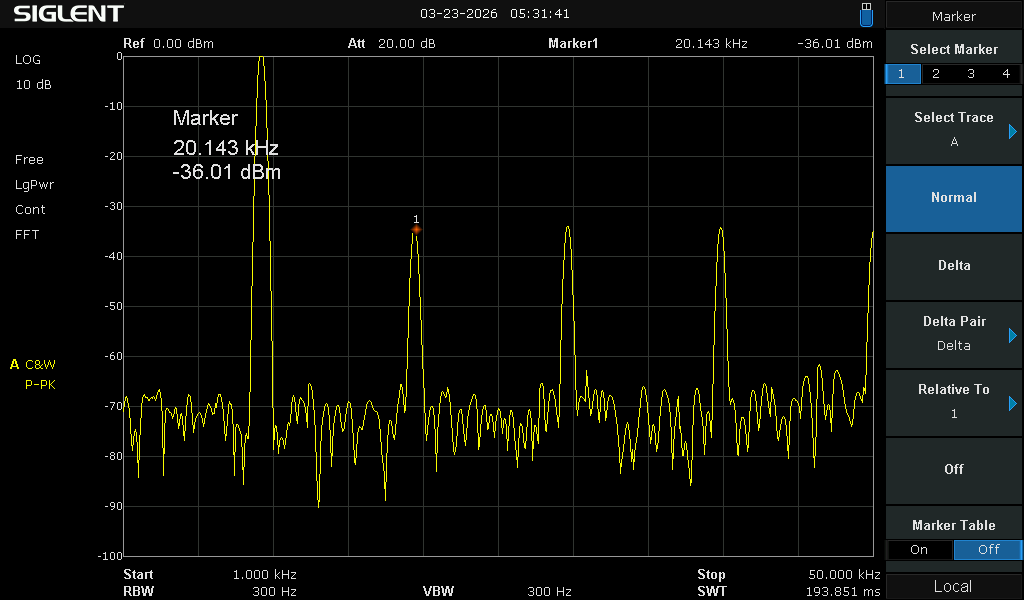
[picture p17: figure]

External BNC signal generator AA LPF output – Strong even and odd harmonics

# 11. ACKNOWLEDGEMENT

FAMILY:

To the keeper of me, my beloved wife, I share everything with you. You are my strength in weakness, clarity in uncertainty and applause in victory. I accomplish nothing without your support, nor is anything of worth unless I can share it with you. I love you.

To my daughter Christina, we have had our challenges. In part, and in this, I hope one day in you the understanding of what I have been trying to say. Love is what you do. You are exceptional in so many ways; add to your gifts hard work and the world is yours.

To my daughter Faith, the Humanitarian, it is clear that you belong to the goodness of this world. You must remember that true greatness is only realized through service and that there are many ways to serve. Therein will be your pursuit – run to catch it. I hope I have shown you how to run.

To my daughter Trinity, the engineer, there is a clarity in the way you speak and think, in your questions and answers. You are to add to the scientific collective. Of the three, you are most like me. Don’t be afraid, nor ashamed of whom you are; accept it, and work hard to be.

To God Almighty, it is you that have made me, and not me myself – thank you for the many blessings, may I be a better servant and steward.

FRIENDS & COLLEAGUES:

Special thanks to my friend Walter Varda, Raytheon an absolute Rock Star of analog engineering and an even better person.

Special thanks to Timoth Brothers, Professor Electrical Engineering, GA Tech, a great sound board for crazy ideas and limiting project scope. Thank you for teaching and inspiring Trinity, we are forever grateful.

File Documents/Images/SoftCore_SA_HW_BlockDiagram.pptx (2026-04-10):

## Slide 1

DIGILENT
ARTY A7

JD

DISPLAY
128x64

DISPLAY UI

JC

UI CONTROL IO

PUSH BTN INPUT

LED AMP
GRAPH

LED MODE SELECT

JB

MICRO SD
FAT FS

uSD

JA

ADC

ADC 12b
SAR

SALLEN KEY LPF

TEST / EXT
SIGNAL IN

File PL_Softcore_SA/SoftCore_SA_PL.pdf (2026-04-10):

ADC_IRQ_N_DONE[0:0] DDR3_0 IMR_ADC_7476A_X2_0 IMR_ADC_7476A_X2_v1.0 (Pre-Production) S00_AXI ADC_SCLK ADC_CS_n ADC_MISO_A ADC_MISO_B IRQ s00_axi_aclk s00_axi_aresetn IMR_PL_Revision_0 IMR PL Revision (Pre-Production) S00_AXI s00_axi_aclk s00_axi_aresetn UI_CSn[2:0] USD_CSn[0:0] QSPI_FLASH_BOOT axi_clock_converter_0 AXI Clock Converter S_AXI M_AXI s_axi_aclk s_axi_aresetn m_axi_aclk m_axi_aresetn axi_gpio_0 AXI GPIO S_AXI GPIO gpio_io_i[11:0] GPIO2 gpio2_io_o[10:0] s_axi_aclk s_axi_aresetnaxi_intc_0 AXI Interrupt Controller s_axi interrupt processor_ack[1:0] interrupt_address[31:0] irq s_axi_aclk s_axi_aresetn intr[3:0] processor_clk processor_rstaxi_quad_spi_0 AXI Quad SPI SPI_0 io0_o io1_i sck_o ss_o[2:0] AXI_LITE ext_spi_clk s_axi_aclk s_axi_aresetn ip2intc_irpt axi_quad_spi_1 AXI Quad SPI SPI_0 io0_o io1_i sck_o ss_o[0:0] AXI_LITE ext_spi_clk s_axi_aclk s_axi_aresetn ip2intc_irpt axi_quad_spi_2 AXI Quad SPISPI_0 STARTUP_IO AXI_LITE ext_spi_clk s_axi_aclk s_axi_aresetn ip2intc_irpt axi_timer_0 AXI Timer S_AXI capturetrig0 capturetrig1 generateout0 generateout1 pwm0 interrupt freeze s_axi_aclk s_axi_aresetn axi_timer_1 AXI Timer S_AXI capturetrig0 capturetrig1 generateout0 generateout1 pwm0 interrupt freeze s_axi_aclk s_axi_aresetn axi_timer_2 AXI Timer S_AXI capturetrig0 capturetrig1 generateout0 generateout1 pwm0 interrupt freeze s_axi_aclk s_axi_aresetn axi_timer_3 AXI Timer S_AXI capturetrig0 capturetrig1 generateout0 generateout1 pwm0 interrupt freeze s_axi_aclk s_axi_aresetn axi_uartlite_0 AXI Uartlite S_AXI UARTrxtx s_axi_aclk s_axi_aresetn interrupt clk_wiz_1 reset clk_in1 Clocking Wizard clk_out1 clk_out2 clk_out3 clk_out4 clk_out5 locked gpio2_io_o_0[10:0] mdm_1 MicroBlaze Debug Module (MDM) MBDEBUG_0 Debug_SYS_Rst microblaze_0 MicroBlaze INTERRUPT Interrupt_Ack[0:1] Interrupt_Address[0:31] Interrupt DLMB ILMB M_AXI_DP M_AXI_DC M_AXI_IC DEBUG Clk Reset microblaze_0_local_memory DLMB ILMB LMB_Clk SYS_Rst mig_7series_0 Memory Interface Generator (MIG 7 Series) DDR3 S_AXI sys_rst clk_ref_i ui_clk_sync_rst ui_clk mmcm_locked sys_clk_i init_calib_complete aresetn ADC_CSn ADC_IP_IRQ ADC_MISO_A ADC_MISO_B AUDIO_PWM ADC_SCLK CLK_100MHZ IOX_2_IRQ PB_3 PB_2 PB_1 MB_CLK MB_RST IOX_MOSI IOX_SCLK DISPLAY_MOSI DISPLAY_MISO DISPLAY_SCLK LED_4 RST_PB TEST_IRQ USD_CD SW_1 SW_0 UART_RX UART_TX USD_MOSI USD_MISO USD_SCLK proc_sys_reset_CPU Processor System Reset slowest_sync_clk ext_reset_in aux_reset_in mb_debug_sys_rst dcm_locked mb_reset bus_struct_reset[0:0] peripheral_reset[0:0] interconnect_aresetn[0:0] peripheral_aresetn[0:0] proc_sys_reset_DDR3 Processor System Reset slowest_sync_clk ext_reset_in aux_reset_in mb_debug_sys_rst dcm_locked mb_reset bus_struct_reset[0:0] peripheral_reset[0:0] interconnect_aresetn[0:0] peripheral_aresetn[0:0] smartconnect_CPU AXI SmartConnect S00_AXI S01_AXI S02_AXI M00_AXI M01_AXI M02_AXI M03_AXI M04_AXI M05_AXI M06_AXI M07_AXI M08_AXI M09_AXI M10_AXI M11_AXI M12_AXI aclk aresetn smartconnect_DDR3 AXI SmartConnect S00_AXI M00_AXI aclk aresetn util_ds_buf_0 Utility Buffer BUFG_I[0:0] BUFG_O[0:0] util_vector_logic_0 Utility Vector Logic Op1[0:0] Res[0:0] util_vector_logic_1 Utility Vector Logic Op1[0:0] Res[0:0] xlconcat_0 Concat In0[0:0] In1[0:0] In2[0:0] In3[0:0] In4[0:0] In5[0:0] In6[0:0] In7[0:0] In8[3:0] dout[11:0] xlconcat_1 Concat In0[0:0] In1[0:0] In2[0:0] In3[0:0] dout[3:0] xlconstant_0 Constant dout[0:0] xlconstant_3 Constant dout[3:0] xlslice_0 Slice Din[10:0] Dout[0:0] Custom IP PL Dual ADC 7476A Custom IP PL Revision RTL This interface used ONLY by bootloader

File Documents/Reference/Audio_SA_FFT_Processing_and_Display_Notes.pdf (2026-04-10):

# SoftCore SA Audio Processing and Display Notes

Detailed walkthrough of FFT_ProcessAudioFrame, buildAudioSpectrumFrame, and displayAudioSpectrum

Purpose | Explain how one audio frame moves from time-domain samples to FFT magnitudes, then to grouped spectrum slots, and finally to OLED bar graphics.
Context | This document covers the Audio SA path only. It assumes the broader FFT concepts are already understood from the Signal SA notes.

## 1. Audio SA Processing Pipeline

The Audio SA path is built as a staged pipeline. One function prepares a clean FFT frame and converts it into per-bin magnitudes. A second function reorganizes those raw FFT bins into a smaller set of display-oriented frequency slots. A third function turns those slot heights into visible bars on the SSD1309 OLED.

This separation is important. The FFT processing function is concerned with mathematical conversion from time domain to frequency domain. The spectrum-building function is concerned with presentation logic such as grouping bins, selecting average or RMS magnitude, converting to dB when desired, and translating the result into a small number of display bars. The display function is concerned only with drawing.

Audio samples in FFT->Samples[] | FFT_ProcessAudioFr ame() | buildAudioSpectrumF rame() | displayAudioSpectru m()
Snapshot frame Apply Hann window | Run real FFT Compute per-bin magnitudes | Group bins into slots Scale to bar heights | Draw segmented bars Send OLED buffer

In practical terms, the first function produces high-resolution spectral data. The second function compresses that information into a form that fits the display. The third function converts that compressed representation into actual pixels.

## 2. Detailed Walkthrough of FFT_ProcessAudioFrame()

### 2.1 Purpose of the Function

`FFT_ProcessAudioFrame()` is the front end of the Audio SA display path. Its job is to take one completed frame of time-domain audio samples, apply the necessary preprocessing, run the FFT, and return a magnitude value for each requested FFT bin. This function does not decide how the data will be displayed. It only creates the frequency-domain measurement data that later stages consume.

Because this function works on one complete frame at a time, it fits naturally with the `FrameReady` flag. Once the frame is copied into a local working buffer, the original shared sample buffer can be reused by the acquisition side. That snapshot behavior protects the FFT computation from seeing samples that are still changing.

### 2.2 Fast-Memory Working Buffers

The function allocates two static working arrays in `.Hab_Fast_Data`. `WindowedSamples[]` holds a local copy of the incoming real-valued time samples. `OutputBins[]` holds the complex FFT output from KissFFT. Placing both arrays in a fast memory section reduces the penalty of repeatedly reading and writing large blocks of data during the FFT pass.

### 2.3 Frame Snapshot and Ownership Hand-Off

After validation, the function copies `FFT->Samples[]` into `WindowedSamples[]` with `memcpy()`. This is a deliberate ownership hand-off. The display-processing side gets a frozen copy of one frame, and the acquisition side is free to refill the original sample buffer for the next frame. Immediately after the copy, `FFT->FrameReady` is cleared so the system knows this frame has been claimed for processing.

### 2.4 Applying the Hann Window

Each sample in the local frame is multiplied by `FFT->HannWindow[Index]`. The purpose of the Hann window is to reduce spectral leakage. In an FFT, the sampled frame is treated as if it repeats forever. If the frame does not begin and end at compatible points in the waveform, the discontinuity at the frame boundary spreads energy into nearby bins. The Hann window reduces that spreading by tapering the ends of the frame toward zero.

The tradeoff is that a window changes amplitude relationships and slightly widens peaks, but for a practical spectrum display it usually gives a much cleaner and more believable result than an unwindowed frame.

### 2.5 Running KissFFT

The call to `kiss_fftr()` performs a real-input FFT. That is important because the source audio samples are real-valued, not complex. KissFFT takes the time-domain frame from `WindowedSamples[]` and transforms it into a set of complex frequency-domain bins stored in `OutputBins[]`. Each output bin contains a real part and an imaginary part. Together those two values encode both the amplitude and the phase of that frequency component.

At a high level, this is the computational heart of the function. It is also the most expensive step in the routine, which is why the source comment notes that it takes the longest amount of time.

### 2.6 Magnitude Computation

Once the FFT is complete, the function converts each requested complex output bin into a scalar magnitude. For each bin, it reads `OutputBins[Bin].r` and `OutputBins[Bin].i`, squares them, adds them, and then takes the square root. This is the standard Euclidean magnitude of a complex number.

The result is stored in `BinMagnitudes[Bin]`. At this point the phase information is discarded because the display only needs strength, not phase. The commented power alternative shows that the design also considered using power instead of amplitude. Power is often useful for analysis, but amplitude is intuitive for visual bar rendering and is consistent with later dB conversion using `20 * log10()`.

### 2.7 Output Meaning

When `FFT_ProcessAudioFrame()` returns true, `BinMagnitudes[]` holds a bin-by-bin description of spectral strength for the current frame. These values are still high-resolution FFT data. They are not yet grouped into display slots, not yet scaled to the display height, and not yet drawn. That next level of interpretation is handled by `buildAudioSpectrumFrame()`.

## 3. Detailed Walkthrough of buildAudioSpectrumFrame()

### 3.1 Purpose of the Function

`buildAudioSpectrumFrame()` acts as the middle layer between raw FFT math and a human-readable display. It takes the dense `BinMagnitudes[]` array and compresses it into a smaller, display-oriented representation. It also computes the frequency associated with each display slot, stores a representative magnitude for each slot, and finally converts those magnitudes into integer bar heights in `DisplayMagnitudeBars[]`.

This function is therefore where the spectrum becomes a display product instead of just a mathematical result. It decides how many frequency slots will be shown, how bins are grouped into each slot, whether magnitudes are represented in linear form or dB form, and how those values map into a fixed vertical bar count.

### 3.2 RBW and Usable Bin Range

The function first computes the resolution bandwidth with `RBW_Hz = SampleRate_Hz / FFT_Size`. This tells the code how much frequency span each FFT bin represents. It then establishes `FirstBin = 1` and `LastBin = BinCount - 1`. Starting at bin 1 intentionally discards the DC term. The last usable bin is the highest FFT output bin available from the real FFT.

This means every later frequency calculation is grounded in real FFT spacing. The center frequency written into `Spectrum->Frequency[Slot]` is not guessed. It is derived from the actual FFT bin spacing.

### 3.3 Building Frequency Slots

The OLED cannot display hundreds of individual FFT bins in a meaningful way, so the function groups bins into a smaller number of frequency slots. Each slot corresponds to one display bar. The code computes `StartFraction` and `EndFraction` for each slot so the entire valid bin range is partitioned from left to right.

If `Spectrum->IsFrequencyLogSpacing` is true, the fractions are squared. That is a simple and efficient way to bias more display resolution toward the lower-frequency region without implementing a true logarithmic axis. The result is a log-like spacing where narrow low-frequency slots and wider high-frequency slots better match how humans often want to inspect audio spectra.

The code then converts those fractions into actual bin ranges. Several guard checks keep the ranges valid and contiguous. Slots are prevented from overlapping, and the last slot is forced to end at the final valid bin so the full spectral span is covered.

### 3.4 Computing Slot Magnitude

For each slot, the function visits every FFT bin assigned to that slot. It accumulates both the simple sum and the sum of squares. That prepares the function to support either average magnitude or RMS magnitude depending on `SlotMagnitudeMethod`.

If `SLOT_MAGNITUDE_RMS` is selected, the slot magnitude becomes `sqrt(SumSq / BinCountInSlot)`. RMS gives more weight to larger contributions and is often a good choice when you want a slot to reflect energy more strongly. If RMS is not selected, the slot uses a straight arithmetic average, which is smoother and slightly less dominated by peaks.

The slot center frequency is then computed from the midpoint between `StartBin` and `EndBin`, multiplied by `RBW_Hz`. That produces a meaningful frequency label for each slot even though the slot covers multiple FFT bins.

### 3.5 Optional dB Conversion

If `Spectrum->IsMagnitudeLog` is true, the slot magnitudes are converted from linear amplitude into decibels. The function uses a fixed reference magnitude of `32768.0f`. That reference reflects a PCM-like full-scale interpretation rather than a normalized floating-point interpretation. The choice of reference directly affects where the display floor and peak values appear. In other words, it is a calibration knob for the visual behavior of the analyzer.

For each slot, the function clamps tiny values away from zero, computes a relative amplitude, and then applies `20 * log10(Relative)`. The result is clamped between `MinDB` and `0 dB`. This ensures that the display range stays bounded and that out-of-range values do not create nonsensical heights.

### 3.6 Converting Slot Magnitudes to Display Bars

The final task of the function is to convert each slot magnitude into a small integer that represents the number of vertical blocks to draw. When log mode is enabled, the dB value is normalized between `MinDB` and `0 dB`. When log mode is disabled, the linear magnitude is optionally compressed, then normalized relative to the largest slot value in the current frame.

After normalization, each slot is scaled into the range `0..MagnitudeBarCount`, rounded, and stored in `DisplayMagnitudeBars[Slot]`. This array is the direct input to the OLED renderer. By the time the function returns, all of the hard interpretation work is complete. The renderer no longer needs to know anything about FFT bin spacing or dB math. It only needs to draw bars of the requested heights.

## 4. Detailed Walkthrough of displayAudioSpectrum()

### 4.1 Purpose of the Function

`displayAudioSpectrum()` is the final rendering stage. It accepts the already-prepared bar heights in `DisplayMagnitude[]` and draws them as segmented vertical bars in the lower portion of the SSD1309 display. This function does not know anything about FFT bins, windowing, RBW, or dB conversion. Its job is purely graphical.

### 4.2 Local Geometry Configuration

The function begins by defining the display geometry in local variables. `NumBars` is the number of frequency columns to draw. `SegmentsPerBar` is the maximum vertical resolution in blocks. `SegmentHeight`, `SegmentVSpace`, `BarWidth`, `BarHSpace`, and `BaselineY` control the appearance of the bar graph. These values make the function self-contained and easy to tune visually without changing the rest of the pipeline.

### 4.3 Clearing the Spectrum Region

Before drawing the next frame, the routine erases the spectrum area by drawing a black box over the lower display region. This is an important display-maintenance step. Without it, bars from a previous frame could remain visible when a newer frame is shorter. The code then restores the draw color to white so the next graphics operations appear on the OLED.

### 4.4 Drawing Bars from Bottom to Top

If `ClearOnly` is false, the function loops over every bar index. For each bar, it reads the desired height from `DisplayMagnitude[BarIndex]`. It computes the X position by multiplying the bar index by the combined width and spacing. It then draws that many small rectangular segments, bottom to top, starting from `BaselineY`.

This segmented style is visually useful on a small OLED. It gives the bars a spectrum-analyzer look and makes relative height changes easy to see. Because the heights were already quantized by `buildAudioSpectrumFrame()`, the renderer can stay simple and deterministic.

### 4.5 Buffer Transfer to the OLED

After the bars are drawn, `u8g2_SendBuffer()` pushes the updated graphics buffer to the SSD1309. That is the moment the new spectrum frame becomes visible. As with the Signal SA path, the drawing API works on an intermediate memory buffer first and only updates the physical display when the buffer is sent.

## 5. How the Three Functions Work Together

The three functions form a clean layered architecture. `FFT_ProcessAudioFrame()` creates raw spectral magnitudes from the audio frame. `buildAudioSpectrumFrame()` reshapes that raw spectral information into a display-oriented model composed of slot frequencies, slot magnitudes, and bar heights. `displayAudioSpectrum()` renders those final bar heights onto the OLED.

This separation is one of the strengths of the design. It makes future edits easier because mathematical processing, display interpretation, and OLED drawing are not mixed together. If you later want to change slot spacing, dB calibration, bar style, or even swap the renderer, you can usually do so in one layer without rewriting the others.

## 6. Practical Notes for Future Editing

If you want to adjust visual behavior, the first question is where the change belongs. Changes to windowing, FFT size, or bin magnitude math belong in `FFT_ProcessAudioFrame()`. Changes to slot grouping, RMS versus average behavior, dB floor, linear compression, or log-like spacing belong in `buildAudioSpectrumFrame()`. Changes to the shape, spacing, and screen placement of the bars belong in `displayAudioSpectrum()`.

That mental model is important. When the design is understood layer by layer, editing becomes much easier because each function has a distinct responsibility.

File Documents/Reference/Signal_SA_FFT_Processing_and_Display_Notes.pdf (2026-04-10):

SoftCore SA - FFT Processing Notes - Page 1

# SoftCore SA FFT Processing and Spectrum Display Notes

A practical explanation of how the FFT frame-processing path works,
how the OLED spectrum trace is generated, and what concepts matter while editing the code.
Platform | Xilinx MicroBlaze using Vivado / Vitis 2024.2
FFT Path | 1024-point real FFT using kissFFT on ADC data centered about midscale
Display Path | Bin magnitudes mapped into a 128 x 64 SSD1309 OLED spectrum trace

## Signal Flow Overview

ADC Samples
(0 to 4095)

Center Around

### 1.65 V

Hann
Window

kiss_fftr()
Real FFT

Bin
Magnitudes

OLED
Trace
-> | -> | -> | -> | ->

## 1. Conceptual Overview of FFT-Based Spectrum Analysis

### 1.1 What the FFT is doing

An FFT does not create new information. It reorganizes the time-domain sample record so you can see how much of the signal exists at many frequencies at once. In the time domain you see the waveform moving up and down sample by sample. In the frequency domain you see energy grouped into frequency locations. Peaks indicate that a periodic component at that frequency is present in the captured data window.
Because the FFT works on a finite block of samples, the result is always tied to one snapshot in time. In this design that snapshot is 1024 ADC samples. Every time a frame becomes ready, the code freezes that block, processes it, and turns it into a spectrum display.

### 1.2 Sample rate, Nyquist, and what can be measured

The sample rate sets the spacing in time between consecutive ADC measurements. Here the ADC is sampled at 50 kHz, so the system takes 50,000 equally spaced samples every second. That immediately creates a hard upper limit on unambiguous frequency measurement.

The Nyquist frequency is half of the sample rate. For a 50 kHz sample rate, Nyquist is 25 kHz. Any real signal content above 25 kHz cannot be represented uniquely after sampling. If higher-frequency content reaches the ADC, it folds back into the measured band and appears at incorrect lower frequencies. This is aliasing.
In practice that means the displayed 0 to 25 kHz region is only trustworthy if the analog front end prevents significant content above 25 kHz from getting into the converter. A proper anti-alias filter is the analog defense against false peaks.

### 1.3 FFT size, bins, and resolution bandwidth

FFT size tells you how many time samples are used in each transform. In this design the FFT size is 1024. The FFT output is divided into bins. Each bin represents one narrow frequency slot. For a real-input FFT only the non-negative half of the spectrum is unique, so the useful output is bins 0 through 512.
The frequency width of each bin is the resolution bandwidth, often abbreviated RBW. It is set by sample rate divided by FFT size. With a 50,000 Hz sample rate and a 1024-point FFT, RBW = 50000 / 1024 = 48.828125 Hz per bin. Bin 1 is near 48.8 Hz, bin 10 is near 488.3 Hz, bin 100 is near 4.883 kHz, and so on.
A smaller RBW gives finer spectral detail because bins are narrower. The cost is that you must wait longer to collect the larger sample window. That is the core tradeoff: more frequency resolution usually means slower update response.

### 1.4 Why windowing is needed

An FFT assumes the captured record repeats cleanly from the end of the frame back to the beginning. Real sampled waveforms usually do not line up that way. If the record begins and ends at mismatched values, the FFT interprets that discontinuity as extra frequency content spread across nearby bins. This spreading is called spectral leakage.
A window function softens the edges of the captured record before the FFT. The Hann window is a common compromise because it reduces leakage well without being excessively complicated. The cost is that the overall amplitude is changed and the main lobe is broadened somewhat. That is acceptable here because a stable, readable display matters more than laboratory-grade amplitude accuracy.

### 1.5 Harmonics: odd, even, and why they exist

A pure sine wave contains only one frequency: the fundamental. Harmonics are integer multiples of that fundamental. If the fundamental is 1 kHz, the second harmonic is 2 kHz, the third is 3 kHz, the fourth is 4 kHz, and so forth.
Harmonics appear when the waveform is no longer a perfect sine. Any nonlinearity in the signal path can reshape the waveform. Clipping, asymmetric biasing, saturation, crossover distortion, and nonlinear amplifiers all change the shape. The FFT reveals that shape change as harmonic energy.

Odd harmonics are the 3rd, 5th, 7th, and other odd multiples above the fundamental. They are often associated with distortions that preserve waveform symmetry about zero. A classic square-wave-like shape contains strong odd harmonics. Even harmonics are the 2nd, 4th, 6th, and other even multiples. They often increase when the waveform becomes asymmetric, such as when positive and negative halves are treated differently.
The practical lesson is simple: when you see harmonic peaks, the FFT is telling you something about waveform shape and system linearity, not just frequency. The fundamental says where the signal is. The harmonic pattern says how clean or distorted that signal is.

### 1.6 Aliasing and harmonic folding

Aliasing matters more when the input has harmonics or other high-frequency content. Suppose the true input is 15 kHz. The fundamental is below Nyquist, so 15 kHz appears correctly. But the second harmonic is 30 kHz, which is above Nyquist and therefore folds. In a 50 kHz sampled system, 30 kHz appears as 20 kHz. The third harmonic at 45 kHz appears as 5 kHz. The fourth harmonic at 60 kHz appears as 10 kHz.
This is why a higher-frequency test tone can produce extra peaks lower in frequency than the input itself. The FFT is not inventing them. It is honestly reporting what the sampled data now looks like after frequencies above Nyquist have been reflected back into the visible band.

## 2. How FFT_ProcessSignalFrame() and displaySignalSpectrum() Work Together

These two functions form a pipeline. FFT_ProcessSignalFrame() converts one completed ADC frame into a set of frequency-bin magnitudes. displaySignalSpectrum() then takes those magnitudes, compresses them into the limited number of horizontal OLED columns, converts them into vertical positions, and draws the visible spectrum trace.
One function answers the question, "How much signal is present in each frequency slot?" The other answers, "How do I turn those numbers into a readable picture on a 128 x 64 display?"

## 3. Detailed Walkthrough of FFT_ProcessSignalFrame()

### 3.1 Function purpose and memory strategy

The purpose of FFT_ProcessSignalFrame() is to take one finished time-domain record and produce frequency-domain magnitudes for the requested bin range. The function uses two static working buffers placed in fast memory: one for the windowed time samples and one for the complex FFT output bins. That choice reduces repeated stack use and gives the time-critical processing path a better chance of finishing quickly on MicroBlaze.

### 3.2 Snapshotting the frame

The first important action is copying FFT->Samples into the local WindowedSamples buffer with memcpy(). This is a protective snapshot. Once the copy is made, the function can work on a stable record even if later code resumes acquisition. Immediately after the copy, FFT-

>FrameReady is cleared. That marks the current frame as consumed and allows the next acquisition cycle to begin after the caller resumes the timer interrupt.

### 3.3 Converting ADC counts into a centered waveform

The raw ADC values are 12-bit counts that live roughly in the range 0 to 4095. Because the analog signal is biased around midscale, the captured samples contain a built-in DC offset near 2048 counts. The loop that subtracts ADC_MID_SCALE_COUNT shifts the waveform so it is centered around zero instead of around 1.65 V.
This step is conceptually important. An FFT of the raw biased data would contain a large DC term at bin 0 and nearby low-frequency contamination. By recentring the samples first, the code focuses the FFT on the AC content that actually represents the signal shape and harmonics of interest.

### 3.4 Applying the Hann window

After centering, each sample is multiplied by a precomputed Hann-window coefficient from FFT->HannWindow[]. This smoothly reduces the contribution of samples at the frame edges. The main goal is to limit spectral leakage when the captured waveform does not complete an exact integer number of cycles inside the 1024-sample record.
This is one of the most important steps for a useful display. Without windowing, energy from one tone would smear more aggressively into adjacent bins, making the trace look less stable and making weaker nearby harmonics harder to interpret.

### 3.5 What kiss_fftr() does at a high level

kiss_fftr() is the real-input FFT routine from kissFFT. You give it the 1024 real-valued time samples and it computes the corresponding frequency-domain result. Because the input is purely real, the negative-frequency half of the spectrum is redundant, so the function returns only the unique bins from DC through Nyquist.
Each output bin is complex, meaning it has a real part and an imaginary part. Together those two numbers encode both amplitude and phase information for that frequency component. The display code only needs strength, not phase, so the next step converts each complex bin into a scalar magnitude.

### 3.6 Magnitude calculation

For each requested bin, the function reads OutputBins[Bin].r and OutputBins[Bin].i, squares them, adds the squares, and then takes the square root. That is the standard Euclidean magnitude of the complex vector. The result is stored in BinMagnitudes[Bin].
This is a sensible representation for the display path because it produces one non-negative strength value per frequency bin. Strong frequencies create larger magnitudes. Weak frequencies create smaller magnitudes. Later display code can then average, compress, or map those values however it wishes.

### 3.7 Practical meaning of the output

After this function returns, BinMagnitudes[] contains the spectral strength for the requested range. It does not yet contain screen positions, dB labels, or any display-specific interpretation. It is still a signal-processing result. That separation is useful. It means you can change the rendering style later without changing the FFT math itself.

## 4. Detailed Walkthrough of displaySignalSpectrum()

### 4.1 Function purpose and display constraints

The OLED is only 128 pixels wide and the active trace region is narrower than that because the function reserves border pixels. The FFT, however, can easily provide hundreds of bins. displaySignalSpectrum() therefore acts as a compression and mapping stage. It converts many FFT bins into a much smaller set of displayed columns while trying to preserve the visual location of important peaks.

### 4.2 Preparing the drawing region

The function defines a boxed region in the lower part of the OLED. It clears that region, draws a frame around it, and places a vertical center line in the middle. This gives the trace a stable visual container and a reference mark for the current span. Only after the area is reset does the function begin drawing the new spectrum.

### 4.3 Choosing the first plotted bin

The displayed bin range is based on LowBin and HighBin, but the function forces the first plotted bin to be at least bin 1. That is a practical suppression of the DC bin. Even after centering, the DC bin can still be unusually large compared with normal signal bins due to residual offset or slow drift. Excluding it prevents the left edge of the display from being dominated by a value that is usually not useful in spectrum mode.

### 4.4 Mapping bins into pixel columns

For each x-position in the trace region, the function calculates a starting bin and stopping bin. This partitions the requested frequency span into slices that match the available horizontal pixel columns. When the span contains more bins than there are columns, several bins land in one displayed column. When the span is narrow, some columns may correspond to only one bin. This mapping is what makes the display feel analyzer-like rather than index-like. The user is not seeing individual raw bins directly. The user is seeing a compressed view of a frequency interval.

### 4.5 Averaging the magnitudes for one column

Inside each column, the function sums the magnitudes for all bins assigned to that column and divides by the number of contributing bins. This creates a column-average magnitude. Averaging is calmer than taking the maximum bin. A max-based method can let one noisy bin create a sharp, jumpy spike. Averaging instead produces a more stable trace that better resembles the visual behavior of a compact analyzer display.

### 4.6 Converting magnitude into dB

The next step is dynamic-range compression. The function limits the minimum magnitude to a small floor value so the logarithm never sees zero. It then converts magnitude to decibels using 20 * log10(magnitude / reference). This is important because a linear magnitude scale often wastes too much vertical space on strong signals and makes weak but real content hard to compare.
The reference magnitude acts as the temporary 0 dB anchor for the display. Changing that reference shifts the whole trace upward or downward on the screen. After conversion, the dB result is clamped to the chosen display range, such as -60 dB to 0 dB, so values outside the visible range do not map beyond the trace box.

### 4.7 Mapping dB to vertical pixel position

Once a column magnitude has been converted into a bounded dB value, the function normalizes that value into the interval from 0 to 1. A normalized value of 0 corresponds to the bottom of the trace area. A normalized value of 1 corresponds to the top. The code then multiplies by the pixel height of the trace region, rounds to the nearest pixel, and converts that into a y-coordinate.
This is the key step that turns engineering units into screen geometry. The FFT result itself has no concept of pixels. After this mapping, every displayed frequency slice has a specific vertical location on the OLED.

### 4.8 Drawing the visible trace

The function keeps track of the previous point and draws a line from the previous x-column to the current one. That produces a continuous trace instead of isolated dots. Continuous line drawing is visually important on a small display because it makes harmonic patterns and general spectral shape easier to interpret at a glance.

### 4.9 Sending the finished frame to the OLED

After all columns have been processed and connected, the function calls u8g2_SendBuffer(). That transfers the prepared frame buffer to the SSD1309 display. Up to that point, all work was happening in memory. This final call makes the newly calculated spectrum visible to the user.

### 4.10 Practical limitations to keep in mind while editing

This display path is intentionally practical rather than mathematically perfect. The exact amplitude calibration still depends on reference selection, window scaling, and how the analog front end behaves. The visible trace can still show some motion because each FFT frame is a new finite snapshot. Additional smoothing can be added later if needed, but the current structure is already clean: signal math first, display mapping second.

## 5. Closing Perspective

These two functions do different jobs, and that separation is worth preserving. FFT_ProcessSignalFrame() is the measurement step. It converts centered, windowed ADC data into per-bin spectral strength. displaySignalSpectrum() is the visualization step. It compresses those strengths into a display-friendly form and turns them into pixels.
Once you understand that separation, editing becomes easier. If a problem is about incorrect peaks, leakage, harmonic content, aliasing, or frame preparation, the FFT-side function is the first place to look. If a problem is about trace height, noisiness, readability, apparent span behavior, or how the picture looks on the OLED, the display-side function is the place to work.

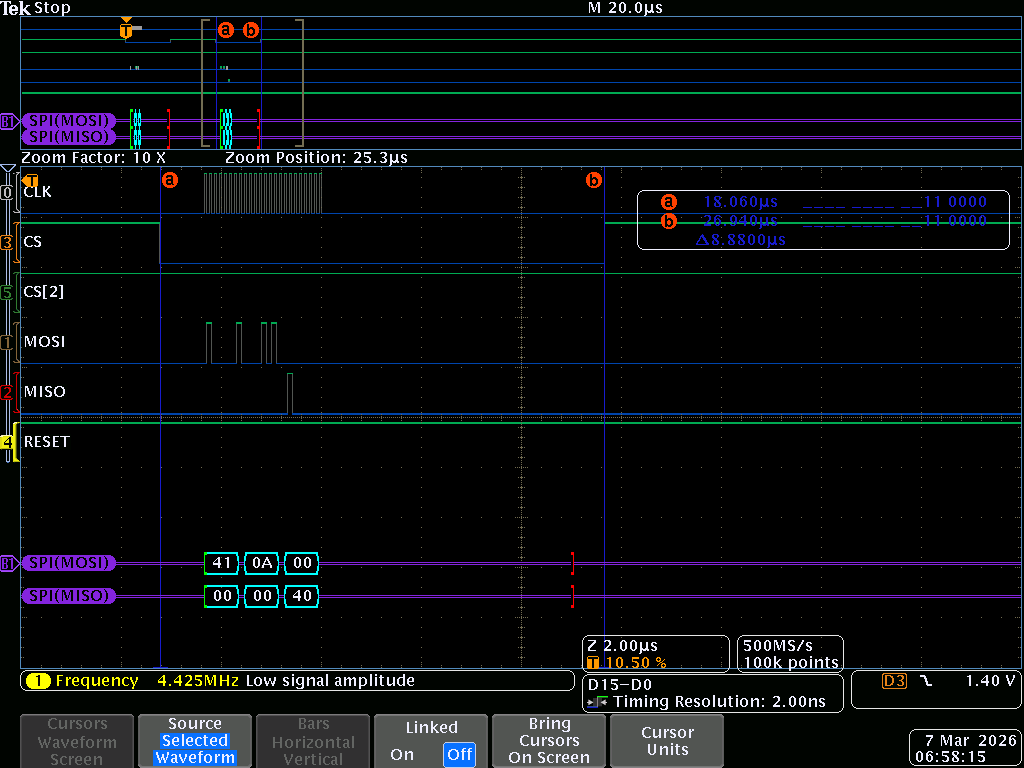
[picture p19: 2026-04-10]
Documents/Scope_Captures/IO_Expanders/tek00037.png

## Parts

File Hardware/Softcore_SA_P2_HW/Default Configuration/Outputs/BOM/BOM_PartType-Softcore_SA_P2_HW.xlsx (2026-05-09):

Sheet: Part List Report
 |  | PROTOTYPE BOM |  |  | SoftCore_SA P2 Adapter
 |  | Source Data From: | Softcore_SA_P2_HW.PrjPcb |  | Company Part Number: | IMR-107-SCH
 |  | Project: | Softcore_SA_P2_HW.PrjPcb |  | PCB Revision: | 1
 |  | Variant: | None |  | Engineer: | Hab S Collector
 |  | Report Date: | 5/9/2026 | 7:34:41 AM
 |  | Print Date: | 2026-05-09 | 7:49:47
# | Quantity | LibRef | Description | Designator | MFG | MFG_PN | Supplier 1 | Supplier Part Number 1 | Unit Price | TOTAL
1 | 21 | CAP_SMD_0.1UF_50V_0805 | CAP CER 0.1UF 50V X7R 0805 | C1, C5, C6, C8, C9, C15, C17, C18, C19, C20, C21, C24, C27, C28, C34, C35, C37, C44, C45, C46, C47 | KYOCERA AVX | KGM21NR71H104KT | DigiKey | 478-KGM21NR71H104KTCT-ND | .1 | $2.10
2 | 3 | CAP_SMD_0.01UF_50V_0805 | CAP CER 0.01UF 50V X7R 0805 | C2, C3, C23 | KYOCERA AVX | KGM21NR71H103KT | DigiKey | 478-KGM21NR71H103KTCT-ND | .1 | $0.30
3 | 3 | CAP_SMD_47UF_16V_1210 | CAP CER 47UF 50V X5R 1210 | C4, C7, C26 | Murata Electronics | GRM32ER60J476ME20L | DigiKey | 490-1887-1-ND | .28 | $0.84
4 | 2 | CAP_SMD_200PF_50V_0805 | CAP CER 200PF 50V X7R 0805 | C10, C11 | KEMET | C0805C201J5RACAUTO | DigiKey | 399-C0805C201J5RACAUTOCT-ND | .19 | $0.38
5 | 2 | CAP_SMD_100PF_50V_0805 | CAP CER 100PF 50V X7R 0805 | C12, C13 | KEMET | C0805C101J5RACAUTO | DigiKey | 399-17614-1-ND | .17 | $0.34
6 | 2 | CAP_SMD_2.2UF_50V_0805 | CAP CER 2.2UF 50V X5R 0805 | C14, C16 | Murata Electronics | GRM219R61E225KA12J | DigiKey | 490-GRM219R61E225KA12JCT-ND | .38 | $0.76
7 | 5 | CAP_SMD_10UF_50V_0805 | CAP CER 10UF 50V X5R 0805 | C22, C29, C32, C42, C43 | Murata Electronics | GRM21BR61H106KE43L | DigiKey | 490-18663-1-ND | .28 | $1.40
8 | 2 | CAP_SMD_1UF_50V_0805 | CAP CER 1UF 50V X7R 0805 | C25, C33 | KYOCERA AVX | 08055C105K4T2A | DigiKey | 478-KAM21KR71H105KUCT-ND | .27 | $0.54
9 | 2 | CAP_SMD_4.7NF_50V_0805 | CAP CER 4.7NF 50V X7R 0805 | C30, C40 | KEMET | C0805C472K5RACAUTO | DigiKey | 399-6969-1-ND | .12 | $0.24
10 | 3 | CAP_SMD_100UF_16V_SMD | CAP CER 100UF 16V X7S SMD | C31, C38, C39 | Taiyo Yuden | EMK325ABJ107MM-P | DigiKey | 587-5426-1-ND | 1.92 | $5.76
11 | 1 | CAP_SMD_4.7UF_50V_0805 | CAP CER 4.7UF 50V X5R 0805 | C36 | Murata Electronics | GRM21BR61H475KE51L | DigiKey | 490-10751-1-ND | .19 | $0.19
12 | 1 | CAP_SMD_22PF_50V_0805 | CAP CER 22PF 50V X7R 0805 | C41 | KEMET | C0805C220K5RACAUTO | DigiKey | 399-17627-1-ND | .24 | $0.24
13 | 4 | DIODE_1N4148W-7-F | RELAY REED SPDT 250MA 5V | D1, D2, D3, D4 | Diodes Inc | 1N4148W-7-F | DigiKey | 1N4148W-FDICT-ND | .16 | $0.64
14 | 4 | CONN_HEADER_12P_100MIL_RA | CONN HEADER R/A 12POS 2.54MM | J1, J3, J4, J6 | Samtec Inc. | TSW-106-08-T-D-RA | Digi-Key | SAM1049-06-ND | .93 | $3.72
15 | 1 | CONN_MICRO-SD_DM3BT-DSF-PEJS | CONN MICRO SD CARD R/A SMD | J2 | Hirose Electric Co Ltd | DM3BT-DSF-PEJS | DigiKey | HR1942CT-ND | 2.30 | $2.30
16 | 1 | CONN_HEADER_3P_100MIL_VERT | CONN HEADER VERT 3POS 2.54MM | J5 | Sullins Connector Solutions | PREC003SFAN-RC | Digi-Key | S1212EC-03-ND | .07 | $0.07
17 | 1 | CONN_MOLEX_0731713150 | CONN BNC RCPT R/A 50 OHM PCB | J7 | Molex | 0731713150 | DigiKey | WM20430-ND | 1.40 | $1.40
18 | 3 | CONN_HEADER_2P_100MIL_VERT, CONN_JUMPER_2P_100MIL_VERT, CONN_JUMPER_2P_100MIL_VERT | CONN HEADER VERT 2POS 2.54MM | J8, J10, J11 | Sullins Connector Solutions | PREC002SFAN-RC | Digi-Key | S1212EC-02-ND | .07 | $0.21
19 | 1 | CONN_BATT_18650 | CONN HEADER VERT 2POS 2.54MM | J9 | Keystone Electronics | 54 | Digi-Key | 36-54-ND | 1.10 | $1.10
20 | 1 | INDUCTOR_74439324022 | POWER INDUCTOR 4030; 2.2UH; 7.80 | L1 | Würth Elektronik | 74439324022 | DigiKey | 732-74439324022CT-ND | 1.80 | $1.80
21 | 7 | LED_GREEN_LTST-C170GKT | LED GREEN CLEAR SMD | LED1, LED2, LED3, LED7, LED8, LED9, LED10 | Lite-On | LTST-C170GKT | DigiKey | 160-1179-1-ND | .10 | $0.70
22 | 2 | LED_YELLOW_LTST-C170YKT | LED YELLOW CLEAR SMD | LED4, LED5 | Lite-On | LTST-C170YKT | DigiKey | 160-1175-1-ND | .15 | $0.30
23 | 1 | LED_RED_LTST-C170EKT | LED RED CLEAR SMD | LED6 | Lite-On | LTST-C170EKT | DigiKey | 160-1178-1-ND | .18 | $0.18
24 | 4 | MECHANICAL_SCREW_M3X6_PAN_HEAD | SCREW M3X6 PAN HEAD SS | MECH1, MECH2, MECH3, MECH4 | APM Hexseal | RM3X6MM 2701 | DigiKey | 335-1156-ND | .58 | $2.32
25 | 4 | MECHANICAL_STANDOFF_M3X20 | HEX STANDOFF M3 BRASS 20MM | MECH5, MECH6, MECH7, MECH8 | Keystone Electronics | 24407 | DigiKey | 36-24407-ND | 1.36 | $5.44
26 | 1 | MECHANICAL_SPEAKER_MOUNTED | SPEAKER PANEL MOUNT | MECH9 | ARDUINO | 312815-3W | ARDUINO | 312815-3W | 2.50 | $2.50
27 | 1 | MODULE_ARTY_A7 | DEVELOPMENT BOARD FPGA XILINX A7 | MECH10 | Digilent, Inc. | 410-319-1 | DigiKey | 1286-1206-ND | 299.00 | $299.00
28 | 1 | MOSFET_NCH_2N7002-7-F | MOSFET N-CH 60V 115MA SOT23-3 | Q1 | Diodes Inc | 2N7002-7-F | DigiKey | 2N7002-FDICT-ND | .20 | $0.20
29 | 25 | RES_SMD_10K_0805_1/4W_1% | RES SMD 10K OHM 1% 1/4W 0805 | R1, R10, R11, R12, R13, R14, R15, R16, R17, R18, R19, R20, R21, R22, R23, R24, R25, R26, R28, R36, R39, R47, R50, R54, R57 | Yageo | RC0805FR-7W10KL | DigiKey | 13-RC0805FR-7W10KLCT-ND | .10 | $2.50
30 | 10 | RES_SMD_240_0805_1/8W_1% | RES SMD 240 OHM 1% 1/8W 0805 | R2, R3, R4, R5, R6, R7, R8, R9, R69, R72 | Yageo | RC0805FR-13240RL | DigiKey | 13-RC0805FR-13240RLCT-ND | .1 | $1.00
31 | 1 | RES_SMD_200_0805_1/8W_1% | RES SMD 200 OHM 1% 1/8W 0805 | R27 | Yageo | RC0805FR-07200RL | DigiKey | 311-200CRCT-ND | .1 | $0.10
32 | 2 | RES_SMD_442_0805_1/8W_1% | RES SMD 442 OHM 1% 1/8W 0805 | R29, R30 | Yageo | RC0805FR-07442RL | DigiKey | 311-442CRCT-ND | .1 | $0.20
33 | 4 | RES_SMD_220_0805_1/8W_1% | RES SMD 220 OHM 1% 1/8W 0805 | R31, R32, R33, R34 | Yageo | RC0805FR-07220RL | DigiKey | 311-220CRCT-ND | .1 | $0.40
34 | 11 | RES_SMD_0_0805_1/8W_1% | RES SMD 0 OHM 1% 1/8W 0805 | R35, R37, R40, R41, R48, R49, R55, R59, R63, R64, R65 | Yageo | RC0805JR-070RL | DigiKey | 311-0.0ARCT-ND | .1 | $1.10
35 | 2 | RES_SMD_1.0K_0805_1/8W_1% | RES SMD 1.0K OHM 1% 1/8W 0805 | R38, R45 | Yageo | RC0805FR-071KL | DigiKey | 311-1.00KCRCT-ND | .1 | $0.20
36 | 2 | RES_SMD_100_0805_1/8W_1% | RES SMD 100 OHM 1% 1/8W 0805 | R42, R44 | Yageo | RC0805FR-07100RL | DigiKey | 311-100CRCT-ND | .1 | $0.20
37 | 1 | RES_SMD_2.15K_0805_1/8W_1% | RES SMD 2.15K OHM 1% 1/8W 0805 | R43 | Yageo | RC0805FR-072K15L | DigiKey | 311-2.15KCRCT-ND | .1 | $0.10
38 | 1 | RES_SMD_20K_0805_1/8W_1% | RES SMD 20K OHM 1% 1/8W 0805 | R46 | Yageo | RC0805FR-0720KL | DigiKey | 311-20.0KCRCT-ND | .1 | $0.10
39 | 1 | RES_POT_10K_1XGANG_LINEAR | POT 10K OHM 1/20W LINEAR - 1X GANG | R51 | Bourns Inc. | 3386F-1-103TLF | DigiKey | 3386F-103TLF-ND | 2.26 | $2.26
40 | 1 | RES_SMD_1.69K_0805_1/8W_1% | RES SMD 1.69K OHM 1% 1/8W 0805 | R52 | Yageo | RC0805FR-071K69L | DigiKey | 311-1.69KCRCT-ND | .1 | $0.10
41 | 1 | RES_SMD_178K_0805_1/8W_1% | RES SMD 178K OHM 1% 1/8W 0805 | R53 | Yageo | RC0805FR-07178KL | DigiKey | 311-178KCRCT-ND | .10 | $0.10
42 | 2 | RES_SMD_100K_0805_1/4W_1% | RES SMD 100K OHM 1% 1/4W 0805 | R56, R58 | Yageo | RC0805FR-07100KL | DigiKey | 311-100KCRCT-ND | .13 | $0.26
43 | 1 | RES_SMD_48.7K_0805_1/8W_1% | RES SMD 48.7K OHM 1% 1/8W 0805 | R60 | Yageo | RC0805FR-0748K7L | DigiKey | 311-48.7KCRCT-ND | .1 | $0.10
44 | 1 | RES_SMD_17.4K_0805_1/8W_1% | RES SMD 17.4K OHM 1% 1/8W 0805 | R61 | Yageo | RC0805FR-0717K4L | DigiKey | 311-17.4KCRCT-ND | .10 | $0.10
45 | 1 | RES_SMD_17.8K_0805_1/8W_1% | RES SMD 17.8K OHM 1% 1/8W 0805 | R62 | Yageo | RC0805FR-0717K8L | DigiKey | 311-17.8KCRCT-ND | .10 | $0.10
46 | 1 | RES_SMD_2.49K_0805_1/8W_1% | RES SMD 2.49K OHM 1% 1/8W 0805 | R66 | Yageo | RC0805FR-132K49L | DigiKey | 13-RC0805FR-132K49LCT-ND | .1 | $0.10
47 | 1 | RES_SMD_6.81K_0805_1/8W_1% | RES SMD 6.81K OHM 1% 1/8W 0805 | R67 | Yageo | RC0805FR-076K81L | DigiKey | 311-6.81KCRCT-ND | .10 | $0.10
48 | 1 | RES_SMD_84.5K_0805_1/8W_1% | RES SMD 84.5K OHM 1% 1/8W 0805 | R68 | Yageo | RC0805FR-0784K5L | DigiKey | 311-84.5KCRCT-ND | .1 | $0.10
49 | 1 | RES_SMD_16K_0805_1/8W_1% | RES SMD 16K OHM 1% 1/8W 0805 | R70 | Yageo | RC0805FR-0716KL | DigiKey | 311-16.0KCRCT-ND | .1 | $0.10
50 | 1 | RES_SMD_73.2K_0805_1/8W_1% | RES SMD 73.2K OHM 1% 1/8W 0805 | R71 | Yageo | RC0805FR-0773K2L | DigiKey | 311-73.2KCRCT-ND | .1 | $0.10
51 | 1 | RES_SMD_26.7K_0805_1/8W_1% | RES SMD 26.7K OHM 1% 1/8W 0805 | R73 | Yageo | RC0805FR-0726K7L | DigiKey | 311-26.7KCRCT-ND | .1 | $0.10
52 | 1 | RES_SMD_33_0805_1/8W_1% | RES SMD 33K OHM 1% 1/8W 0805 | R74 | Yageo | 311-33.0CRCT-ND | DigiKey | 311-33.0CRCT-ND | .1 | $0.10
53 | 1 | RES_SMD_1M_0805_1/4W_1% | RES SMD 1K OHM 1% 1/4W 0805 | R75 | Yageo | RC0805FR-7W1ML | DigiKey | 13-RC0805FR-7W1MLCT-ND | .10 | $0.10
54 | 1 | RELAY_HE721C0500 | RELAY REED SPDT 250MA 5V | REL1 | Littlefuse | HE721C0500 | DigiKey | HE112-ND | 3.77 | $3.77
55 | 1 | CONN_SPKR_HEADER_2P_100MIL | CONN SPEAKER HEADER GENERIC VERT 2POS 2.54MM | SPK1 | GENERIC | TBD | Digi-Key | TBD | 1.00 | $1.00
56 | 1 | SWITCH_PEC12R-4222F-S0024 | ENCODER INCRE QUAD HORIZN PC PIN | SW1 | Bourns | PEC12R-4222F-S0024 | DigiKey | PEC12R-4222F-S0024-ND | 1.72 | $1.72
57 | 5 | SWITCH_EVQ-Q2U02W | SWITCH TACTILE SPST-NO 0.02A 15V | SW2, SW3, SW4, SW5, SW6 | American Zettler | EVQ-Q2U02W | DigiKey | P12954SCT-ND | .25 | $1.25
58 | 1 | SWITCH_SLW-12689-4A-N-D | SWITCH SLIDE SPDT 300MA 50V | SW7 | Same Sky | SLW-12689-4A-N-D | DigiKey | 2223-SLW-12689-4A-N-D-ND | .48 | $0.48
59 | 6 | CONN_TEST_POINT_S1751-46R | PCB TEST POINT CONNECT | TP4, TP5, TP7, TP11, TP13, TP14 | Harwin Inc | S1751-46R | Digi-Key | 952-1478-1-ND | .28 | $1.68
60 | 2 | IC_MCP23S08T-E/SO | IC IO XPNDR 10MHZ SPI 18SOIC | U1, U2 | Microchip | MCP23S08T-E/SO | DigiKey | MCP23S08T-E/SOCT-ND | 1.54 | $3.08
61 | 1 | MODULE_DISPLAY_128X64_2.42 | DISPLAY 128X64 SSD1309 2.42" OLED WHITE | U3 | UNKNOWN | SSD1309_128X64_2.42" | Amazon | SSD1309 2.42" | 16.99 | $16.99
62 | 2 | IC_LTC2315CTS8-12#TRMPBF | IC ADC 12BIT SAR TSOT23-8 | U4, U6 | Analog Devices | LTC2315CTS8-12#TRMPBF | DigiKey | LTC2315CTS8-12#TRMPBFCT-ND | 15.34 | $30.68
63 | 1 | IC_OPAMP_LT1819CS8#TRPBF | IC OPAMP GBP 400MHz CIRCUIT 8SOIC | U5 | Analog Devices | LT1819CS8#TRPBF | DigiKey | LT1819CS8#TRPBFCT-ND | 5.94 | $5.94
64 | 1 | IC_OPAMP_TLV9351IDCKR | IC OPAMP GP 3.5MHZ 350uV C70-5 | U7 | Texas Instruments | TLV9351IDCKR | DigiKey | 296-TLV9351IDCKRCT-ND | .49 | $0.49
65 | 1 | IC_OPAMP_ADA4897-1ARZ | IC OPAMP GP 230MHZ 28uV 8SOIC | U8 | Analog Devices | ADA4897-1ARZ | DigiKey | 505-ADA4897-1ARZ-ND | 6.30 | $6.30
66 | 1 | IC_LM4041CYM3-ADJ-TR | IC VREF SHUNT ADJ 0.5% SOT23-3 | U9 | Microchip | LM4041CYM3-ADJ-TR | DigiKey | 576-1049-1-ND | .39 | $0.39
67 | 1 | IC_AD9833BRMZ | IC DDS 25MHZ 10BIT 10MSOP | U10 | Analog Devices | AD9833BRMZ | DigiKey | 505-AD9833BRMZ-ND | 15.19 | $15.19
68 | 1 | IC_LM4990MMX/NOPB | IC AMP CLASS AB MONO 2W 8VSSOP | U11 | Texas Instruments | LM4990MMX/NOPB | DigiKey | 296-37579-1-ND | .45 | $0.45
69 | 1 | IC_OPAMP_TLV9302IDR | IC OPAMP GP 2 CIRCUIT 8SOIC | U12 | Texas Instruments | TLV9302IDR | DigiKey | 296-53513-1-ND | .66 | $0.66
70 | 1 | IC_SMPS_TPS552892RYQR | IC REG BUCK ADJ 1A 16HTSSOP | U13 | Texas Instruments | TPS552892RYQR | DigiKey | 296-TPS552892RYQRCT-ND | 6.42 | $6.42
71 | 1 | IC_REG_AZ1117CH-ADJTRG1 | IC REG BUCK ADJ 2A SOT23 | U14 | Diodes Incorporated | AZ1117CH-ADJTRG1 | DigiKey | AZ1117CH-ADJTRG1DICT-ND | .2 | $0.20
72 | 2 | IC_COMPARATOR_MCP65R41T-1202E/CHY | IC COMPARATOR 1 W/VOLT REF SOT23 | U15, U16 | Microchip Technology | MCP65R41T-1202E/CHY | DigiKey | MCP65R41T-1202E/CHYCT-ND | .53 | $1.06
Approved |  |  |  |  | Notes |  |  | Bill of Cost (Unit Buy): |  | $442.44

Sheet: Project Information
Project Full Path | C:\IMR_Projects\IMR\Softcore_SA_P2\Hardware\Softcore_SA_P2_HW\Softcore_SA_P2_HW.PrjPcb
Project Filename | Softcore_SA_P2_HW.PrjPcb
Variant Name | None
Data-Source Filename | Softcore_SA_P2_HW.PrjPcb
Data-Source Full Path | C:\IMR_Projects\IMR\Softcore_SA_P2\Hardware\Softcore_SA_P2_HW\Softcore_SA_P2_HW.PrjPcb
Title | SoftCore_SA P2 Adapter
Total Quantity | 190
Report Time | 7:34:41 AM
Report Date | 5/9/2026
Report Date & Tine | 5/9/2026 7:34:41 AM
Output Name | BOM_PartType
Output Type | BOM_PartType
Output Generator Name | BOM
Output Generator Description | Bill of Materials
Total Actual Price | <Parameter TotalActualPrice not found>
Total Target Price | <Parameter TotalTargetPrice not found>

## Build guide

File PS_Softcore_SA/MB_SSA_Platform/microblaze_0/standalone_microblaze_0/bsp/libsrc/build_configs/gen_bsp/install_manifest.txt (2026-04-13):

C:/IMR_Projects/IMR/Softcore_SA_P2/PS_Softcore_SA/MB_SSA_Platform/microblaze_0/standalone_microblaze_0/bsp/include/../include/bspconfig.h
C:/IMR_Projects/IMR/Softcore_SA_P2/PS_Softcore_SA/MB_SSA_Platform/microblaze_0/standalone_microblaze_0/bsp/include/../include/fsl.h
C:/IMR_Projects/IMR/Softcore_SA_P2/PS_Softcore_SA/MB_SSA_Platform/microblaze_0/standalone_microblaze_0/bsp/include/../include/mb_interface.h
C:/IMR_Projects/IMR/Softcore_SA_P2/PS_Softcore_SA/MB_SSA_Platform/microblaze_0/standalone_microblaze_0/bsp/include/../include/microblaze_exceptions_g.h
C:/IMR_Projects/IMR/Softcore_SA_P2/PS_Softcore_SA/MB_SSA_Platform/microblaze_0/standalone_microblaze_0/bsp/include/../include/microblaze_exceptions_i.h
C:/IMR_Projects/IMR/Softcore_SA_P2/PS_Softcore_SA/MB_SSA_Platform/microblaze_0/standalone_microblaze_0/bsp/include/../include/microblaze_instructions.h
C:/IMR_Projects/IMR/Softcore_SA_P2/PS_Softcore_SA/MB_SSA_Platform/microblaze_0/standalone_microblaze_0/bsp/include/../include/microblaze_interrupts_i.h
C:/IMR_Projects/IMR/Softcore_SA_P2/PS_Softcore_SA/MB_SSA_Platform/microblaze_0/standalone_microblaze_0/bsp/include/../include/pvr.h
C:/IMR_Projects/IMR/Softcore_SA_P2/PS_Softcore_SA/MB_SSA_Platform/microblaze_0/standalone_microblaze_0/bsp/include/../include/sleep.h
C:/IMR_Projects/IMR/Softcore_SA_P2/PS_Softcore_SA/MB_SSA_Platform/microblaze_0/standalone_microblaze_0/bsp/include/../include/xbasic_types.h
C:/IMR_Projects/IMR/Softcore_SA_P2/PS_Softcore_SA/MB_SSA_Platform/microblaze_0/standalone_microblaze_0/bsp/include/../include/xcommon_drv_config.h
C:/IMR_Projects/IMR/Softcore_SA_P2/PS_Softcore_SA/MB_SSA_Platform/microblaze_0/standalone_microblaze_0/bsp/include/../include/xdebug.h
C:/IMR_Projects/IMR/Softcore_SA_P2/PS_Softcore_SA/MB_SSA_Platform/microblaze_0/standalone_microblaze_0/bsp/include/../include/xenv.h
C:/IMR_Projects/IMR/Softcore_SA_P2/PS_Softcore_SA/MB_SSA_Platform/microblaze_0/standalone_microblaze_0/bsp/include/../include/xenv_standalone.h
C:/IMR_Projects/IMR/Softcore_SA_P2/PS_Softcore_SA/MB_SSA_Platform/microblaze_0/standalone_microblaze_0/bsp/include/../include/xgpio.h
C:/IMR_Projects/IMR/Softcore_SA_P2/PS_Softcore_SA/MB_SSA_Platform/microblaze_0/standalone_microblaze_0/bsp/include/../include/xgpio_i.h
C:/IMR_Projects/IMR/Softcore_SA_P2/PS_Softcore_SA/MB_SSA_Platform/microblaze_0/standalone_microblaze_0/bsp/include/../include/xgpio_l.h
C:/IMR_Projects/IMR/Softcore_SA_P2/PS_Softcore_SA/MB_SSA_Platform/microblaze_0/standalone_microblaze_0/bsp/include/../include/xiltimer.h
C:/IMR_Projects/IMR/Softcore_SA_P2/PS_Softcore_SA/MB_SSA_Platform/microblaze_0/standalone_microblaze_0/bsp/include/../include/xil_assert.h
C:/IMR_Projects/IMR/Softcore_SA_P2/PS_Softcore_SA/MB_SSA_Platform/microblaze_0/standalone_microblaze_0/bsp/include/../include/xil_cache.h
C:/IMR_Projects/IMR/Softcore_SA_P2/PS_Softcore_SA/MB_SSA_Platform/microblaze_0/standalone_microblaze_0/bsp/include/../include/xil_cache_vxworks.h
C:/IMR_Projects/IMR/Softcore_SA_P2/PS_Softcore_SA/MB_SSA_Platform/microblaze_0/standalone_microblaze_0/bsp/include/../include/xil_cryptoalginfo.h
C:/IMR_Projects/IMR/Softcore_SA_P2/PS_Softcore_SA/MB_SSA_Platform/microblaze_0/standalone_microblaze_0/bsp/include/../include/xil_exception.h
C:/IMR_Projects/IMR/Softcore_SA_P2/PS_Softcore_SA/MB_SSA_Platform/microblaze_0/standalone_microblaze_0/bsp/include/../include/xil_hal.h
C:/IMR_Projects/IMR/Softcore_SA_P2/PS_Softcore_SA/MB_SSA_Platform/microblaze_0/standalone_microblaze_0/bsp/include/../include/xil_io.h
C:/IMR_Projects/IMR/Softcore_SA_P2/PS_Softcore_SA/MB_SSA_Platform/microblaze_0/standalone_microblaze_0/bsp/include/../include/xil_macroback.h
C:/IMR_Projects/IMR/Softcore_SA_P2/PS_Softcore_SA/MB_SSA_Platform/microblaze_0/standalone_microblaze_0/bsp/include/../include/xil_mem.h
C:/IMR_Projects/IMR/Softcore_SA_P2/PS_Softcore_SA/MB_SSA_Platform/microblaze_0/standalone_microblaze_0/bsp/include/../include/xil_misc_psreset_api.h
C:/IMR_Projects/IMR/Softcore_SA_P2/PS_Softcore_SA/MB_SSA_Platform/microblaze_0/standalone_microblaze_0/bsp/include/../include/xil_printf.h
C:/IMR_Projects/IMR/Softcore_SA_P2/PS_Softcore_SA/MB_SSA_Platform/microblaze_0/standalone_microblaze_0/bsp/include/../include/xil_sutil.h
C:/IMR_Projects/IMR/Softcore_SA_P2/PS_Softcore_SA/MB_SSA_Platform/microblaze_0/standalone_microblaze_0/bsp/include/../include/xil_testcache.h
C:/IMR_Projects/IMR/Softcore_SA_P2/PS_Softcore_SA/MB_SSA_Platform/microblaze_0/standalone_microblaze_0/bsp/include/../include/xil_testio.h
C:/IMR_Projects/IMR/Softcore_SA_P2/PS_Softcore_SA/MB_SSA_Platform/microblaze_0/standalone_microblaze_0/bsp/include/../include/xil_testmem.h
C:/IMR_Projects/IMR/Softcore_SA_P2/PS_Softcore_SA/MB_SSA_Platform/microblaze_0/standalone_microblaze_0/bsp/include/../include/xil_types.h
C:/IMR_Projects/IMR/Softcore_SA_P2/PS_Softcore_SA/MB_SSA_Platform/microblaze_0/standalone_microblaze_0/bsp/include/../include/xil_util.h
C:/IMR_Projects/IMR/Softcore_SA_P2/PS_Softcore_SA/MB_SSA_Platform/microblaze_0/standalone_microblaze_0/bsp/include/../include/xintc.h
C:/IMR_Projects/IMR/Softcore_SA_P2/PS_Softcore_SA/MB_SSA_Platform/microblaze_0/standalone_microblaze_0/bsp/include/../include/xintc_drv_config.h
C:/IMR_Projects/IMR/Softcore_SA_P2/PS_Softcore_SA/MB_SSA_Platform/microblaze_0/standalone_microblaze_0/bsp/include/../include/xintc_i.h
C:/IMR_Projects/IMR/Softcore_SA_P2/PS_Softcore_SA/MB_SSA_Platform/microblaze_0/standalone_microblaze_0/bsp/include/../include/xintc_l.h
C:/IMR_Projects/IMR/Softcore_SA_P2/PS_Softcore_SA/MB_SSA_Platform/microblaze_0/standalone_microblaze_0/bsp/include/../include/xinterrupt_wrap.h
C:/IMR_Projects/IMR/Softcore_SA_P2/PS_Softcore_SA/MB_SSA_Platform/microblaze_0/standalone_microblaze_0/bsp/include/../include/xio.h
C:/IMR_Projects/IMR/Softcore_SA_P2/PS_Softcore_SA/MB_SSA_Platform/microblaze_0/standalone_microblaze_0/bsp/include/../include/xmem_config.h
C:/IMR_Projects/IMR/Softcore_SA_P2/PS_Softcore_SA/MB_SSA_Platform/microblaze_0/standalone_microblaze_0/bsp/include/../include/xmicroblaze.h
C:/IMR_Projects/IMR/Softcore_SA_P2/PS_Softcore_SA/MB_SSA_Platform/microblaze_0/standalone_microblaze_0/bsp/include/../include/xmicroblaze_config.h
C:/IMR_Projects/IMR/Softcore_SA_P2/PS_Softcore_SA/MB_SSA_Platform/microblaze_0/standalone_microblaze_0/bsp/include/../include/xplatform_info.h
C:/IMR_Projects/IMR/Softcore_SA_P2/PS_Softcore_SA/MB_SSA_Platform/microblaze_0/standalone_microblaze_0/bsp/include/../include/xspi.h
C:/IMR_Projects/IMR/Softcore_SA_P2/PS_Softcore_SA/MB_SSA_Platform/microblaze_0/standalone_microblaze_0/bsp/include/../include/xspi_i.h
C:/IMR_Projects/IMR/Softcore_SA_P2/PS_Softcore_SA/MB_SSA_Platform/microblaze_0/standalone_microblaze_0/bsp/include/../include/xspi_l.h
C:/IMR_Projects/IMR/Softcore_SA_P2/PS_Softcore_SA/MB_SSA_Platform/microblaze_0/standalone_microblaze_0/bsp/include/../include/xstatus.h
C:/IMR_Projects/IMR/Softcore_SA_P2/PS_Softcore_SA/MB_SSA_Platform/microblaze_0/standalone_microblaze_0/bsp/include/../include/xtimer_config.h
C:/IMR_Projects/IMR/Softcore_SA_P2/PS_Softcore_SA/MB_SSA_Platform/microblaze_0/standalone_microblaze_0/bsp/include/../include/xtmrctr.h
C:/IMR_Projects/IMR/Softcore_SA_P2/PS_Softcore_SA/MB_SSA_Platform/microblaze_0/standalone_microblaze_0/bsp/include/../include/xtmrctr_i.h
C:/IMR_Projects/IMR/Softcore_SA_P2/PS_Softcore_SA/MB_SSA_Platform/microblaze_0/standalone_microblaze_0/bsp/include/../include/xtmrctr_l.h
C:/IMR_Projects/IMR/Softcore_SA_P2/PS_Softcore_SA/MB_SSA_Platform/microblaze_0/standalone_microblaze_0/bsp/include/../include/xuartlite.h
C:/IMR_Projects/IMR/Softcore_SA_P2/PS_Softcore_SA/MB_SSA_Platform/microblaze_0/standalone_microblaze_0/bsp/include/../include/xuartlite_i.h
C:/IMR_Projects/IMR/Softcore_SA_P2/PS_Softcore_SA/MB_SSA_Platform/microblaze_0/standalone_microblaze_0/bsp/include/../include/xuartlite_l.h
C:/IMR_Projects/IMR/Softcore_SA_P2/PS_Softcore_SA/MB_SSA_Platform/microblaze_0/standalone_microblaze_0/bsp/lib/libxilstandalone.a
C:/IMR_Projects/IMR/Softcore_SA_P2/PS_Softcore_SA/MB_SSA_Platform/microblaze_0/standalone_microblaze_0/bsp/include/../include/bspconfig.h
C:/IMR_Projects/IMR/Softcore_SA_P2/PS_Softcore_SA/MB_SSA_Platform/microblaze_0/standalone_microblaze_0/bsp/include/../include/fsl.h
C:/IMR_Projects/IMR/Softcore_SA_P2/PS_Softcore_SA/MB_SSA_Platform/microblaze_0/standalone_microblaze_0/bsp/include/../include/mb_interface.h
C:/IMR_Projects/IMR/Softcore_SA_P2/PS_Softcore_SA/MB_SSA_Platform/microblaze_0/standalone_microblaze_0/bsp/include/../include/microblaze_exceptions_g.h
C:/IMR_Projects/IMR/Softcore_SA_P2/PS_Softcore_SA/MB_SSA_Platform/microblaze_0/standalone_microblaze_0/bsp/include/../include/microblaze_exceptions_i.h
C:/IMR_Projects/IMR/Softcore_SA_P2/PS_Softcore_SA/MB_SSA_Platform/microblaze_0/standalone_microblaze_0/bsp/include/../include/microblaze_instructions.h
C:/IMR_Projects/IMR/Softcore_SA_P2/PS_Softcore_SA/MB_SSA_Platform/microblaze_0/standalone_microblaze_0/bsp/include/../include/microblaze_interrupts_i.h
C:/IMR_Projects/IMR/Softcore_SA_P2/PS_Softcore_SA/MB_SSA_Platform/microblaze_0/standalone_microblaze_0/bsp/include/../include/pvr.h
C:/IMR_Projects/IMR/Softcore_SA_P2/PS_Softcore_SA/MB_SSA_Platform/microblaze_0/standalone_microblaze_0/bsp/include/../include/sleep.h
C:/IMR_Projects/IMR/Softcore_SA_P2/PS_Softcore_SA/MB_SSA_Platform/microblaze_0/standalone_microblaze_0/bsp/include/../include/xbasic_types.h
C:/IMR_Projects/IMR/Softcore_SA_P2/PS_Softcore_SA/MB_SSA_Platform/microblaze_0/standalone_microblaze_0/bsp/include/../include/xcommon_drv_config.h
C:/IMR_Projects/IMR/Softcore_SA_P2/PS_Softcore_SA/MB_SSA_Platform/microblaze_0/standalone_microblaze_0/bsp/include/../include/xdebug.h
C:/IMR_Projects/IMR/Softcore_SA_P2/PS_Softcore_SA/MB_SSA_Platform/microblaze_0/standalone_microblaze_0/bsp/include/../include/xenv.h
C:/IMR_Projects/IMR/Softcore_SA_P2/PS_Softcore_SA/MB_SSA_Platform/microblaze_0/standalone_microblaze_0/bsp/include/../include/xenv_standalone.h
C:/IMR_Projects/IMR/Softcore_SA_P2/PS_Softcore_SA/MB_SSA_Platform/microblaze_0/standalone_microblaze_0/bsp/include/../include/xgpio.h
C:/IMR_Projects/IMR/Softcore_SA_P2/PS_Softcore_SA/MB_SSA_Platform/microblaze_0/standalone_microblaze_0/bsp/include/../include/xgpio_i.h
C:/IMR_Projects/IMR/Softcore_SA_P2/PS_Softcore_SA/MB_SSA_Platform/microblaze_0/standalone_microblaze_0/bsp/include/../include/xgpio_l.h
C:/IMR_Projects/IMR/Softcore_SA_P2/PS_Softcore_SA/MB_SSA_Platform/microblaze_0/standalone_microblaze_0/bsp/include/../include/xiltimer.h
C:/IMR_Projects/IMR/Softcore_SA_P2/PS_Softcore_SA/MB_SSA_Platform/microblaze_0/standalone_microblaze_0/bsp/include/../include/xil_assert.h
C:/IMR_Projects/IMR/Softcore_SA_P2/PS_Softcore_SA/MB_SSA_Platform/microblaze_0/standalone_microblaze_0/bsp/include/../include/xil_cache.h
C:/IMR_Projects/IMR/Softcore_SA_P2/PS_Softcore_SA/MB_SSA_Platform/microblaze_0/standalone_microblaze_0/bsp/include/../include/xil_cache_vxworks.h
C:/IMR_Projects/IMR/Softcore_SA_P2/PS_Softcore_SA/MB_SSA_Platform/microblaze_0/standalone_microblaze_0/bsp/include/../include/xil_cryptoalginfo.h
C:/IMR_Projects/IMR/Softcore_SA_P2/PS_Softcore_SA/MB_SSA_Platform/microblaze_0/standalone_microblaze_0/bsp/include/../include/xil_exception.h
C:/IMR_Projects/IMR/Softcore_SA_P2/PS_Softcore_SA/MB_SSA_Platform/microblaze_0/standalone_microblaze_0/bsp/include/../include/xil_hal.h
C:/IMR_Projects/IMR/Softcore_SA_P2/PS_Softcore_SA/MB_SSA_Platform/microblaze_0/standalone_microblaze_0/bsp/include/../include/xil_io.h
C:/IMR_Projects/IMR/Softcore_SA_P2/PS_Softcore_SA/MB_SSA_Platform/microblaze_0/standalone_microblaze_0/bsp/include/../include/xil_macroback.h
C:/IMR_Projects/IMR/Softcore_SA_P2/PS_Softcore_SA/MB_SSA_Platform/microblaze_0/standalone_microblaze_0/bsp/include/../include/xil_mem.h
C:/IMR_Projects/IMR/Softcore_SA_P2/PS_Softcore_SA/MB_SSA_Platform/microblaze_0/standalone_microblaze_0/bsp/include/../include/xil_misc_psreset_api.h
C:/IMR_Projects/IMR/Softcore_SA_P2/PS_Softcore_SA/MB_SSA_Platform/microblaze_0/standalone_microblaze_0/bsp/include/../include/xil_printf.h
C:/IMR_Projects/IMR/Softcore_SA_P2/PS_Softcore_SA/MB_SSA_Platform/microblaze_0/standalone_microblaze_0/bsp/include/../include/xil_sutil.h
C:/IMR_Projects/IMR/Softcore_SA_P2/PS_Softcore_SA/MB_SSA_Platform/microblaze_0/standalone_microblaze_0/bsp/include/../include/xil_testcache.h
C:/IMR_Projects/IMR/Softcore_SA_P2/PS_Softcore_SA/MB_SSA_Platform/microblaze_0/standalone_microblaze_0/bsp/include/../include/xil_testio.h
C:/IMR_Projects/IMR/Softcore_SA_P2/PS_Softcore_SA/MB_SSA_Platform/microblaze_0/standalone_microblaze_0/bsp/include/../include/xil_testmem.h
C:/IMR_Projects/IMR/Softcore_SA_P2/PS_Softcore_SA/MB_SSA_Platform/microblaze_0/standalone_microblaze_0/bsp/include/../include/xil_types.h
C:/IMR_Projects/IMR/Softcore_SA_P2/PS_Softcore_SA/MB_SSA_Platform/microblaze_0/standalone_microblaze_0/bsp/include/../include/xil_util.h
C:/IMR_Projects/IMR/Softcore_SA_P2/PS_Softcore_SA/MB_SSA_Platform/microblaze_0/standalone_microblaze_0/bsp/include/../include/xintc.h
C:/IMR_Projects/IMR/Softcore_SA_P2/PS_Softcore_SA/MB_SSA_Platform/microblaze_0/standalone_microblaze_0/bsp/include/../include/xintc_drv_config.h
C:/IMR_Projects/IMR/Softcore_SA_P2/PS_Softcore_SA/MB_SSA_Platform/microblaze_0/standalone_microblaze_0/bsp/include/../include/xintc_i.h
C:/IMR_Projects/IMR/Softcore_SA_P2/PS_Softcore_SA/MB_SSA_Platform/microblaze_0/standalone_microblaze_0/bsp/include/../include/xintc_l.h
C:/IMR_Projects/IMR/Softcore_SA_P2/PS_Softcore_SA/MB_SSA_Platform/microblaze_0/standalone_microblaze_0/bsp/include/../include/xinterrupt_wrap.h
C:/IMR_Projects/IMR/Softcore_SA_P2/PS_Softcore_SA/MB_SSA_Platform/microblaze_0/standalone_microblaze_0/bsp/include/../include/xio.h
C:/IMR_Projects/IMR/Softcore_SA_P2/PS_Softcore_SA/MB_SSA_Platform/microblaze_0/standalone_microblaze_0/bsp/include/../include/xmem_config.h
C:/IMR_Projects/IMR/Softcore_SA_P2/PS_Softcore_SA/MB_SSA_Platform/microblaze_0/standalone_microblaze_0/bsp/include/../include/xmicroblaze.h
C:/IMR_Projects/IMR/Softcore_SA_P2/PS_Softcore_SA/MB_SSA_Platform/microblaze_0/standalone_microblaze_0/bsp/include/../include/xmicroblaze_config.h
C:/IMR_Projects/IMR/Softcore_SA_P2/PS_Softcore_SA/MB_SSA_Platform/microblaze_0/standalone_microblaze_0/bsp/include/../include/xplatform_info.h
C:/IMR_Projects/IMR/Softcore_SA_P2/PS_Softcore_SA/MB_SSA_Platform/microblaze_0/standalone_microblaze_0/bsp/include/../include/xspi.h
C:/IMR_Projects/IMR/Softcore_SA_P2/PS_Softcore_SA/MB_SSA_Platform/microblaze_0/standalone_microblaze_0/bsp/include/../include/xspi_i.h
C:/IMR_Projects/IMR/Softcore_SA_P2/PS_Softcore_SA/MB_SSA_Platform/microblaze_0/standalone_microblaze_0/bsp/include/../include/xspi_l.h
C:/IMR_Projects/IMR/Softcore_SA_P2/PS_Softcore_SA/MB_SSA_Platform/microblaze_0/standalone_microblaze_0/bsp/include/../include/xstatus.h
C:/IMR_Projects/IMR/Softcore_SA_P2/PS_Softcore_SA/MB_SSA_Platform/microblaze_0/standalone_microblaze_0/bsp/include/../include/xtimer_config.h
C:/IMR_Projects/IMR/Softcore_SA_P2/PS_Softcore_SA/MB_SSA_Platform/microblaze_0/standalone_microblaze_0/bsp/include/../include/xtmrctr.h
C:/IMR_Projects/IMR/Softcore_SA_P2/PS_Softcore_SA/MB_SSA_Platform/microblaze_0/standalone_microblaze_0/bsp/include/../include/xtmrctr_i.h
C:/IMR_Projects/IMR/Softcore_SA_P2/PS_Softcore_SA/MB_SSA_Platform/microblaze_0/standalone_microblaze_0/bsp/include/../include/xtmrctr_l.h
C:/IMR_Projects/IMR/Softcore_SA_P2/PS_Softcore_SA/MB_SSA_Platform/microblaze_0/standalone_microblaze_0/bsp/include/../include/xuartlite.h
C:/IMR_Projects/IMR/Softcore_SA_P2/PS_Softcore_SA/MB_SSA_Platform/microblaze_0/standalone_microblaze_0/bsp/include/../include/xuartlite_i.h
C:/IMR_Projects/IMR/Softcore_SA_P2/PS_Softcore_SA/MB_SSA_Platform/microblaze_0/standalone_microblaze_0/bsp/include/../include/xuartlite_l.h
C:/IMR_Projects/IMR/Softcore_SA_P2/PS_Softcore_SA/MB_SSA_Platform/microblaze_0/standalone_microblaze_0/bsp/lib/libxiltimer.a
C:/IMR_Projects/IMR/Softcore_SA_P2/PS_Softcore_SA/MB_SSA_Platform/microblaze_0/standalone_microblaze_0/bsp/include/../include/bspconfig.h
C:/IMR_Projects/IMR/Softcore_SA_P2/PS_Softcore_SA/MB_SSA_Platform/microblaze_0/standalone_microblaze_0/bsp/include/../include/fsl.h
C:/IMR_Projects/IMR/Softcore_SA_P2/PS_Softcore_SA/MB_SSA_Platform/microblaze_0/standalone_microblaze_0/bsp/include/../include/mb_interface.h
C:/IMR_Projects/IMR/Softcore_SA_P2/PS_Softcore_SA/MB_SSA_Platform/microblaze_0/standalone_microblaze_0/bsp/include/../include/microblaze_exceptions_g.h
C:/IMR_Projects/IMR/Softcore_SA_P2/PS_Softcore_SA/MB_SSA_Platform/microblaze_0/standalone_microblaze_0/bsp/include/../include/microblaze_exceptions_i.h
C:/IMR_Projects/IMR/Softcore_SA_P2/PS_Softcore_SA/MB_SSA_Platform/microblaze_0/standalone_microblaze_0/bsp/include/../include/microblaze_instructions.h
C:/IMR_Projects/IMR/Softcore_SA_P2/PS_Softcore_SA/MB_SSA_Platform/microblaze_0/standalone_microblaze_0/bsp/include/../include/microblaze_interrupts_i.h
C:/IMR_Projects/IMR/Softcore_SA_P2/PS_Softcore_SA/MB_SSA_Platform/microblaze_0/standalone_microblaze_0/bsp/include/../include/pvr.h
C:/IMR_Projects/IMR/Softcore_SA_P2/PS_Softcore_SA/MB_SSA_Platform/microblaze_0/standalone_microblaze_0/bsp/include/../include/sleep.h
C:/IMR_Projects/IMR/Softcore_SA_P2/PS_Softcore_SA/MB_SSA_Platform/microblaze_0/standalone_microblaze_0/bsp/include/../include/xbasic_types.h
C:/IMR_Projects/IMR/Softcore_SA_P2/PS_Softcore_SA/MB_SSA_Platform/microblaze_0/standalone_microblaze_0/bsp/include/../include/xcommon_drv_config.h
C:/IMR_Projects/IMR/Softcore_SA_P2/PS_Softcore_SA/MB_SSA_Platform/microblaze_0/standalone_microblaze_0/bsp/include/../include/xdebug.h
C:/IMR_Projects/IMR/Softcore_SA_P2/PS_Softcore_SA/MB_SSA_Platform/microblaze_0/standalone_microblaze_0/bsp/include/../include/xenv.h
C:/IMR_Projects/IMR/Softcore_SA_P2/PS_Softcore_SA/MB_SSA_Platform/microblaze_0/standalone_microblaze_0/bsp/include/../include/xenv_standalone.h
C:/IMR_Projects/IMR/Softcore_SA_P2/PS_Softcore_SA/MB_SSA_Platform/microblaze_0/standalone_microblaze_0/bsp/include/../include/xgpio.h
C:/IMR_Projects/IMR/Softcore_SA_P2/PS_Softcore_SA/MB_SSA_Platform/microblaze_0/standalone_microblaze_0/bsp/include/../include/xgpio_i.h
C:/IMR_Projects/IMR/Softcore_SA_P2/PS_Softcore_SA/MB_SSA_Platform/microblaze_0/standalone_microblaze_0/bsp/include/../include/xgpio_l.h
C:/IMR_Projects/IMR/Softcore_SA_P2/PS_Softcore_SA/MB_SSA_Platform/microblaze_0/standalone_microblaze_0/bsp/include/../include/xiltimer.h
C:/IMR_Projects/IMR/Softcore_SA_P2/PS_Softcore_SA/MB_SSA_Platform/microblaze_0/standalone_microblaze_0/bsp/include/../include/xil_assert.h
C:/IMR_Projects/IMR/Softcore_SA_P2/PS_Softcore_SA/MB_SSA_Platform/microblaze_0/standalone_microblaze_0/bsp/include/../include/xil_cache.h
C:/IMR_Projects/IMR/Softcore_SA_P2/PS_Softcore_SA/MB_SSA_Platform/microblaze_0/standalone_microblaze_0/bsp/include/../include/xil_cache_vxworks.h
C:/IMR_Projects/IMR/Softcore_SA_P2/PS_Softcore_SA/MB_SSA_Platform/microblaze_0/standalone_microblaze_0/bsp/include/../include/xil_cryptoalginfo.h
C:/IMR_Projects/IMR/Softcore_SA_P2/PS_Softcore_SA/MB_SSA_Platform/microblaze_0/standalone_microblaze_0/bsp/include/../include/xil_exception.h
C:/IMR_Projects/IMR/Softcore_SA_P2/PS_Softcore_SA/MB_SSA_Platform/microblaze_0/standalone_microblaze_0/bsp/include/../include/xil_hal.h
C:/IMR_Projects/IMR/Softcore_SA_P2/PS_Softcore_SA/MB_SSA_Platform/microblaze_0/standalone_microblaze_0/bsp/include/../include/xil_io.h
C:/IMR_Projects/IMR/Softcore_SA_P2/PS_Softcore_SA/MB_SSA_Platform/microblaze_0/standalone_microblaze_0/bsp/include/../include/xil_macroback.h
C:/IMR_Projects/IMR/Softcore_SA_P2/PS_Softcore_SA/MB_SSA_Platform/microblaze_0/standalone_microblaze_0/bsp/include/../include/xil_mem.h
C:/IMR_Projects/IMR/Softcore_SA_P2/PS_Softcore_SA/MB_SSA_Platform/microblaze_0/standalone_microblaze_0/bsp/include/../include/xil_misc_psreset_api.h
C:/IMR_Projects/IMR/Softcore_SA_P2/PS_Softcore_SA/MB_SSA_Platform/microblaze_0/standalone_microblaze_0/bsp/include/../include/xil_printf.h
C:/IMR_Projects/IMR/Softcore_SA_P2/PS_Softcore_SA/MB_SSA_Platform/microblaze_0/standalone_microblaze_0/bsp/include/../include/xil_sutil.h
C:/IMR_Projects/IMR/Softcore_SA_P2/PS_Softcore_SA/MB_SSA_Platform/microblaze_0/standalone_microblaze_0/bsp/include/../include/xil_testcache.h
C:/IMR_Projects/IMR/Softcore_SA_P2/PS_Softcore_SA/MB_SSA_Platform/microblaze_0/standalone_microblaze_0/bsp/include/../include/xil_testio.h
C:/IMR_Projects/IMR/Softcore_SA_P2/PS_Softcore_SA/MB_SSA_Platform/microblaze_0/standalone_microblaze_0/bsp/include/../include/xil_testmem.h
C:/IMR_Projects/IMR/Softcore_SA_P2/PS_Softcore_SA/MB_SSA_Platform/microblaze_0/standalone_microblaze_0/bsp/include/../include/xil_types.h
C:/IMR_Projects/IMR/Softcore_SA_P2/PS_Softcore_SA/MB_SSA_Platform/microblaze_0/standalone_microblaze_0/bsp/include/../include/xil_util.h
C:/IMR_Projects/IMR/Softcore_SA_P2/PS_Softcore_SA/MB_SSA_Platform/microblaze_0/standalone_microblaze_0/bsp/include/../include/xintc.h
C:/IMR_Projects/IMR/Softcore_SA_P2/PS_Softcore_SA/MB_SSA_Platform/microblaze_0/standalone_microblaze_0/bsp/include/../include/xintc_drv_config.h
C:/IMR_Projects/IMR/Softcore_SA_P2/PS_Softcore_SA/MB_SSA_Platform/microblaze_0/standalone_microblaze_0/bsp/include/../include/xintc_i.h
C:/IMR_Projects/IMR/Softcore_SA_P2/PS_Softcore_SA/MB_SSA_Platform/microblaze_0/standalone_microblaze_0/bsp/include/../include/xintc_l.h
C:/IMR_Projects/IMR/Softcore_SA_P2/PS_Softcore_SA/MB_SSA_Platform/microblaze_0/standalone_microblaze_0/bsp/include/../include/xinterrupt_wrap.h
C:/IMR_Projects/IMR/Softcore_SA_P2/PS_Softcore_SA/MB_SSA_Platform/microblaze_0/standalone_microblaze_0/bsp/include/../include/xio.h
C:/IMR_Projects/IMR/Softcore_SA_P2/PS_Softcore_SA/MB_SSA_Platform/microblaze_0/standalone_microblaze_0/bsp/include/../include/xmem_config.h
C:/IMR_Projects/IMR/Softcore_SA_P2/PS_Softcore_SA/MB_SSA_Platform/microblaze_0/standalone_microblaze_0/bsp/include/../include/xmicroblaze.h
C:/IMR_Projects/IMR/Softcore_SA_P2/PS_Softcore_SA/MB_SSA_Platform/microblaze_0/standalone_microblaze_0/bsp/include/../include/xmicroblaze_config.h
C:/IMR_Projects/IMR/Softcore_SA_P2/PS_Softcore_SA/MB_SSA_Platform/microblaze_0/standalone_microblaze_0/bsp/include/../include/xplatform_info.h
C:/IMR_Projects/IMR/Softcore_SA_P2/PS_Softcore_SA/MB_SSA_Platform/microblaze_0/standalone_microblaze_0/bsp/include/../include/xspi.h
C:/IMR_Projects/IMR/Softcore_SA_P2/PS_Softcore_SA/MB_SSA_Platform/microblaze_0/standalone_microblaze_0/bsp/include/../include/xspi_i.h
C:/IMR_Projects/IMR/Softcore_SA_P2/PS_Softcore_SA/MB_SSA_Platform/microblaze_0/standalone_microblaze_0/bsp/include/../include/xspi_l.h
C:/IMR_Projects/IMR/Softcore_SA_P2/PS_Softcore_SA/MB_SSA_Platform/microblaze_0/standalone_microblaze_0/bsp/include/../include/xstatus.h
C:/IMR_Projects/IMR/Softcore_SA_P2/PS_Softcore_SA/MB_SSA_Platform/microblaze_0/standalone_microblaze_0/bsp/include/../include/xtimer_config.h
C:/IMR_Projects/IMR/Softcore_SA_P2/PS_Softcore_SA/MB_SSA_Platform/microblaze_0/standalone_microblaze_0/bsp/include/../include/xtmrctr.h
C:/IMR_Projects/IMR/Softcore_SA_P2/PS_Softcore_SA/MB_SSA_Platform/microblaze_0/standalone_microblaze_0/bsp/include/../include/xtmrctr_i.h
C:/IMR_Projects/IMR/Softcore_SA_P2/PS_Softcore_SA/MB_SSA_Platform/microblaze_0/standalone_microblaze_0/bsp/include/../include/xtmrctr_l.h
C:/IMR_Projects/IMR/Softcore_SA_P2/PS_Softcore_SA/MB_SSA_Platform/microblaze_0/standalone_microblaze_0/bsp/include/../include/xuartlite.h
C:/IMR_Projects/IMR/Softcore_SA_P2/PS_Softcore_SA/MB_SSA_Platform/microblaze_0/standalone_microblaze_0/bsp/include/../include/xuartlite_i.h
C:/IMR_Projects/IMR/Softcore_SA_P2/PS_Softcore_SA/MB_SSA_Platform/microblaze_0/standalone_microblaze_0/bsp/include/../include/xuartlite_l.h

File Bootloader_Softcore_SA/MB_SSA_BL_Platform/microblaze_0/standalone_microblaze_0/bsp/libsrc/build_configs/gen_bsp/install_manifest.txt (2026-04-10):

C:/IMR_Projects/IMR/Softcore_SA/Bootloader_Softcore_SA/MB_SSA_BL_Platform/microblaze_0/standalone_microblaze_0/bsp/include/../include/bspconfig.h
C:/IMR_Projects/IMR/Softcore_SA/Bootloader_Softcore_SA/MB_SSA_BL_Platform/microblaze_0/standalone_microblaze_0/bsp/include/../include/fsl.h
C:/IMR_Projects/IMR/Softcore_SA/Bootloader_Softcore_SA/MB_SSA_BL_Platform/microblaze_0/standalone_microblaze_0/bsp/include/../include/mb_interface.h
C:/IMR_Projects/IMR/Softcore_SA/Bootloader_Softcore_SA/MB_SSA_BL_Platform/microblaze_0/standalone_microblaze_0/bsp/include/../include/microblaze_exceptions_g.h
C:/IMR_Projects/IMR/Softcore_SA/Bootloader_Softcore_SA/MB_SSA_BL_Platform/microblaze_0/standalone_microblaze_0/bsp/include/../include/microblaze_exceptions_i.h
C:/IMR_Projects/IMR/Softcore_SA/Bootloader_Softcore_SA/MB_SSA_BL_Platform/microblaze_0/standalone_microblaze_0/bsp/include/../include/microblaze_instructions.h
C:/IMR_Projects/IMR/Softcore_SA/Bootloader_Softcore_SA/MB_SSA_BL_Platform/microblaze_0/standalone_microblaze_0/bsp/include/../include/microblaze_interrupts_i.h
C:/IMR_Projects/IMR/Softcore_SA/Bootloader_Softcore_SA/MB_SSA_BL_Platform/microblaze_0/standalone_microblaze_0/bsp/include/../include/pvr.h
C:/IMR_Projects/IMR/Softcore_SA/Bootloader_Softcore_SA/MB_SSA_BL_Platform/microblaze_0/standalone_microblaze_0/bsp/include/../include/sleep.h
C:/IMR_Projects/IMR/Softcore_SA/Bootloader_Softcore_SA/MB_SSA_BL_Platform/microblaze_0/standalone_microblaze_0/bsp/include/../include/xbasic_types.h
C:/IMR_Projects/IMR/Softcore_SA/Bootloader_Softcore_SA/MB_SSA_BL_Platform/microblaze_0/standalone_microblaze_0/bsp/include/../include/xcommon_drv_config.h
C:/IMR_Projects/IMR/Softcore_SA/Bootloader_Softcore_SA/MB_SSA_BL_Platform/microblaze_0/standalone_microblaze_0/bsp/include/../include/xdebug.h
C:/IMR_Projects/IMR/Softcore_SA/Bootloader_Softcore_SA/MB_SSA_BL_Platform/microblaze_0/standalone_microblaze_0/bsp/include/../include/xenv.h
C:/IMR_Projects/IMR/Softcore_SA/Bootloader_Softcore_SA/MB_SSA_BL_Platform/microblaze_0/standalone_microblaze_0/bsp/include/../include/xenv_standalone.h
C:/IMR_Projects/IMR/Softcore_SA/Bootloader_Softcore_SA/MB_SSA_BL_Platform/microblaze_0/standalone_microblaze_0/bsp/include/../include/xgpio.h
C:/IMR_Projects/IMR/Softcore_SA/Bootloader_Softcore_SA/MB_SSA_BL_Platform/microblaze_0/standalone_microblaze_0/bsp/include/../include/xgpio_i.h
C:/IMR_Projects/IMR/Softcore_SA/Bootloader_Softcore_SA/MB_SSA_BL_Platform/microblaze_0/standalone_microblaze_0/bsp/include/../include/xgpio_l.h
C:/IMR_Projects/IMR/Softcore_SA/Bootloader_Softcore_SA/MB_SSA_BL_Platform/microblaze_0/standalone_microblaze_0/bsp/include/../include/xiltimer.h
C:/IMR_Projects/IMR/Softcore_SA/Bootloader_Softcore_SA/MB_SSA_BL_Platform/microblaze_0/standalone_microblaze_0/bsp/include/../include/xil_assert.h
C:/IMR_Projects/IMR/Softcore_SA/Bootloader_Softcore_SA/MB_SSA_BL_Platform/microblaze_0/standalone_microblaze_0/bsp/include/../include/xil_cache.h
C:/IMR_Projects/IMR/Softcore_SA/Bootloader_Softcore_SA/MB_SSA_BL_Platform/microblaze_0/standalone_microblaze_0/bsp/include/../include/xil_cache_vxworks.h
C:/IMR_Projects/IMR/Softcore_SA/Bootloader_Softcore_SA/MB_SSA_BL_Platform/microblaze_0/standalone_microblaze_0/bsp/include/../include/xil_cryptoalginfo.h
C:/IMR_Projects/IMR/Softcore_SA/Bootloader_Softcore_SA/MB_SSA_BL_Platform/microblaze_0/standalone_microblaze_0/bsp/include/../include/xil_exception.h
C:/IMR_Projects/IMR/Softcore_SA/Bootloader_Softcore_SA/MB_SSA_BL_Platform/microblaze_0/standalone_microblaze_0/bsp/include/../include/xil_hal.h
C:/IMR_Projects/IMR/Softcore_SA/Bootloader_Softcore_SA/MB_SSA_BL_Platform/microblaze_0/standalone_microblaze_0/bsp/include/../include/xil_io.h
C:/IMR_Projects/IMR/Softcore_SA/Bootloader_Softcore_SA/MB_SSA_BL_Platform/microblaze_0/standalone_microblaze_0/bsp/include/../include/xil_macroback.h
C:/IMR_Projects/IMR/Softcore_SA/Bootloader_Softcore_SA/MB_SSA_BL_Platform/microblaze_0/standalone_microblaze_0/bsp/include/../include/xil_mem.h
C:/IMR_Projects/IMR/Softcore_SA/Bootloader_Softcore_SA/MB_SSA_BL_Platform/microblaze_0/standalone_microblaze_0/bsp/include/../include/xil_misc_psreset_api.h
C:/IMR_Projects/IMR/Softcore_SA/Bootloader_Softcore_SA/MB_SSA_BL_Platform/microblaze_0/standalone_microblaze_0/bsp/include/../include/xil_printf.h
C:/IMR_Projects/IMR/Softcore_SA/Bootloader_Softcore_SA/MB_SSA_BL_Platform/microblaze_0/standalone_microblaze_0/bsp/include/../include/xil_sutil.h
C:/IMR_Projects/IMR/Softcore_SA/Bootloader_Softcore_SA/MB_SSA_BL_Platform/microblaze_0/standalone_microblaze_0/bsp/include/../include/xil_testcache.h
C:/IMR_Projects/IMR/Softcore_SA/Bootloader_Softcore_SA/MB_SSA_BL_Platform/microblaze_0/standalone_microblaze_0/bsp/include/../include/xil_testio.h
C:/IMR_Projects/IMR/Softcore_SA/Bootloader_Softcore_SA/MB_SSA_BL_Platform/microblaze_0/standalone_microblaze_0/bsp/include/../include/xil_testmem.h
C:/IMR_Projects/IMR/Softcore_SA/Bootloader_Softcore_SA/MB_SSA_BL_Platform/microblaze_0/standalone_microblaze_0/bsp/include/../include/xil_types.h
C:/IMR_Projects/IMR/Softcore_SA/Bootloader_Softcore_SA/MB_SSA_BL_Platform/microblaze_0/standalone_microblaze_0/bsp/include/../include/xil_util.h
C:/IMR_Projects/IMR/Softcore_SA/Bootloader_Softcore_SA/MB_SSA_BL_Platform/microblaze_0/standalone_microblaze_0/bsp/include/../include/xintc.h
C:/IMR_Projects/IMR/Softcore_SA/Bootloader_Softcore_SA/MB_SSA_BL_Platform/microblaze_0/standalone_microblaze_0/bsp/include/../include/xintc_drv_config.h
C:/IMR_Projects/IMR/Softcore_SA/Bootloader_Softcore_SA/MB_SSA_BL_Platform/microblaze_0/standalone_microblaze_0/bsp/include/../include/xintc_i.h
C:/IMR_Projects/IMR/Softcore_SA/Bootloader_Softcore_SA/MB_SSA_BL_Platform/microblaze_0/standalone_microblaze_0/bsp/include/../include/xintc_l.h
C:/IMR_Projects/IMR/Softcore_SA/Bootloader_Softcore_SA/MB_SSA_BL_Platform/microblaze_0/standalone_microblaze_0/bsp/include/../include/xinterrupt_wrap.h
C:/IMR_Projects/IMR/Softcore_SA/Bootloader_Softcore_SA/MB_SSA_BL_Platform/microblaze_0/standalone_microblaze_0/bsp/include/../include/xio.h
C:/IMR_Projects/IMR/Softcore_SA/Bootloader_Softcore_SA/MB_SSA_BL_Platform/microblaze_0/standalone_microblaze_0/bsp/include/../include/xmem_config.h
C:/IMR_Projects/IMR/Softcore_SA/Bootloader_Softcore_SA/MB_SSA_BL_Platform/microblaze_0/standalone_microblaze_0/bsp/include/../include/xmicroblaze.h
C:/IMR_Projects/IMR/Softcore_SA/Bootloader_Softcore_SA/MB_SSA_BL_Platform/microblaze_0/standalone_microblaze_0/bsp/include/../include/xmicroblaze_config.h
C:/IMR_Projects/IMR/Softcore_SA/Bootloader_Softcore_SA/MB_SSA_BL_Platform/microblaze_0/standalone_microblaze_0/bsp/include/../include/xplatform_info.h
C:/IMR_Projects/IMR/Softcore_SA/Bootloader_Softcore_SA/MB_SSA_BL_Platform/microblaze_0/standalone_microblaze_0/bsp/include/../include/xspi.h
C:/IMR_Projects/IMR/Softcore_SA/Bootloader_Softcore_SA/MB_SSA_BL_Platform/microblaze_0/standalone_microblaze_0/bsp/include/../include/xspi_i.h
C:/IMR_Projects/IMR/Softcore_SA/Bootloader_Softcore_SA/MB_SSA_BL_Platform/microblaze_0/standalone_microblaze_0/bsp/include/../include/xspi_l.h
C:/IMR_Projects/IMR/Softcore_SA/Bootloader_Softcore_SA/MB_SSA_BL_Platform/microblaze_0/standalone_microblaze_0/bsp/include/../include/xstatus.h
C:/IMR_Projects/IMR/Softcore_SA/Bootloader_Softcore_SA/MB_SSA_BL_Platform/microblaze_0/standalone_microblaze_0/bsp/include/../include/xtimer_config.h
C:/IMR_Projects/IMR/Softcore_SA/Bootloader_Softcore_SA/MB_SSA_BL_Platform/microblaze_0/standalone_microblaze_0/bsp/include/../include/xtmrctr.h
C:/IMR_Projects/IMR/Softcore_SA/Bootloader_Softcore_SA/MB_SSA_BL_Platform/microblaze_0/standalone_microblaze_0/bsp/include/../include/xtmrctr_i.h
C:/IMR_Projects/IMR/Softcore_SA/Bootloader_Softcore_SA/MB_SSA_BL_Platform/microblaze_0/standalone_microblaze_0/bsp/include/../include/xtmrctr_l.h
C:/IMR_Projects/IMR/Softcore_SA/Bootloader_Softcore_SA/MB_SSA_BL_Platform/microblaze_0/standalone_microblaze_0/bsp/include/../include/xuartlite.h
C:/IMR_Projects/IMR/Softcore_SA/Bootloader_Softcore_SA/MB_SSA_BL_Platform/microblaze_0/standalone_microblaze_0/bsp/include/../include/xuartlite_i.h
C:/IMR_Projects/IMR/Softcore_SA/Bootloader_Softcore_SA/MB_SSA_BL_Platform/microblaze_0/standalone_microblaze_0/bsp/include/../include/xuartlite_l.h
C:/IMR_Projects/IMR/Softcore_SA/Bootloader_Softcore_SA/MB_SSA_BL_Platform/microblaze_0/standalone_microblaze_0/bsp/lib/libxilstandalone.a
C:/IMR_Projects/IMR/Softcore_SA/Bootloader_Softcore_SA/MB_SSA_BL_Platform/microblaze_0/standalone_microblaze_0/bsp/include/../include/bspconfig.h
C:/IMR_Projects/IMR/Softcore_SA/Bootloader_Softcore_SA/MB_SSA_BL_Platform/microblaze_0/standalone_microblaze_0/bsp/include/../include/fsl.h
C:/IMR_Projects/IMR/Softcore_SA/Bootloader_Softcore_SA/MB_SSA_BL_Platform/microblaze_0/standalone_microblaze_0/bsp/include/../include/mb_interface.h
C:/IMR_Projects/IMR/Softcore_SA/Bootloader_Softcore_SA/MB_SSA_BL_Platform/microblaze_0/standalone_microblaze_0/bsp/include/../include/microblaze_exceptions_g.h
C:/IMR_Projects/IMR/Softcore_SA/Bootloader_Softcore_SA/MB_SSA_BL_Platform/microblaze_0/standalone_microblaze_0/bsp/include/../include/microblaze_exceptions_i.h
C:/IMR_Projects/IMR/Softcore_SA/Bootloader_Softcore_SA/MB_SSA_BL_Platform/microblaze_0/standalone_microblaze_0/bsp/include/../include/microblaze_instructions.h
C:/IMR_Projects/IMR/Softcore_SA/Bootloader_Softcore_SA/MB_SSA_BL_Platform/microblaze_0/standalone_microblaze_0/bsp/include/../include/microblaze_interrupts_i.h
C:/IMR_Projects/IMR/Softcore_SA/Bootloader_Softcore_SA/MB_SSA_BL_Platform/microblaze_0/standalone_microblaze_0/bsp/include/../include/pvr.h
C:/IMR_Projects/IMR/Softcore_SA/Bootloader_Softcore_SA/MB_SSA_BL_Platform/microblaze_0/standalone_microblaze_0/bsp/include/../include/sleep.h
C:/IMR_Projects/IMR/Softcore_SA/Bootloader_Softcore_SA/MB_SSA_BL_Platform/microblaze_0/standalone_microblaze_0/bsp/include/../include/xbasic_types.h
C:/IMR_Projects/IMR/Softcore_SA/Bootloader_Softcore_SA/MB_SSA_BL_Platform/microblaze_0/standalone_microblaze_0/bsp/include/../include/xcommon_drv_config.h
C:/IMR_Projects/IMR/Softcore_SA/Bootloader_Softcore_SA/MB_SSA_BL_Platform/microblaze_0/standalone_microblaze_0/bsp/include/../include/xdebug.h
C:/IMR_Projects/IMR/Softcore_SA/Bootloader_Softcore_SA/MB_SSA_BL_Platform/microblaze_0/standalone_microblaze_0/bsp/include/../include/xenv.h
C:/IMR_Projects/IMR/Softcore_SA/Bootloader_Softcore_SA/MB_SSA_BL_Platform/microblaze_0/standalone_microblaze_0/bsp/include/../include/xenv_standalone.h
C:/IMR_Projects/IMR/Softcore_SA/Bootloader_Softcore_SA/MB_SSA_BL_Platform/microblaze_0/standalone_microblaze_0/bsp/include/../include/xgpio.h
C:/IMR_Projects/IMR/Softcore_SA/Bootloader_Softcore_SA/MB_SSA_BL_Platform/microblaze_0/standalone_microblaze_0/bsp/include/../include/xgpio_i.h
C:/IMR_Projects/IMR/Softcore_SA/Bootloader_Softcore_SA/MB_SSA_BL_Platform/microblaze_0/standalone_microblaze_0/bsp/include/../include/xgpio_l.h
C:/IMR_Projects/IMR/Softcore_SA/Bootloader_Softcore_SA/MB_SSA_BL_Platform/microblaze_0/standalone_microblaze_0/bsp/include/../include/xiltimer.h
C:/IMR_Projects/IMR/Softcore_SA/Bootloader_Softcore_SA/MB_SSA_BL_Platform/microblaze_0/standalone_microblaze_0/bsp/include/../include/xil_assert.h
C:/IMR_Projects/IMR/Softcore_SA/Bootloader_Softcore_SA/MB_SSA_BL_Platform/microblaze_0/standalone_microblaze_0/bsp/include/../include/xil_cache.h
C:/IMR_Projects/IMR/Softcore_SA/Bootloader_Softcore_SA/MB_SSA_BL_Platform/microblaze_0/standalone_microblaze_0/bsp/include/../include/xil_cache_vxworks.h
C:/IMR_Projects/IMR/Softcore_SA/Bootloader_Softcore_SA/MB_SSA_BL_Platform/microblaze_0/standalone_microblaze_0/bsp/include/../include/xil_cryptoalginfo.h
C:/IMR_Projects/IMR/Softcore_SA/Bootloader_Softcore_SA/MB_SSA_BL_Platform/microblaze_0/standalone_microblaze_0/bsp/include/../include/xil_exception.h
C:/IMR_Projects/IMR/Softcore_SA/Bootloader_Softcore_SA/MB_SSA_BL_Platform/microblaze_0/standalone_microblaze_0/bsp/include/../include/xil_hal.h
C:/IMR_Projects/IMR/Softcore_SA/Bootloader_Softcore_SA/MB_SSA_BL_Platform/microblaze_0/standalone_microblaze_0/bsp/include/../include/xil_io.h
C:/IMR_Projects/IMR/Softcore_SA/Bootloader_Softcore_SA/MB_SSA_BL_Platform/microblaze_0/standalone_microblaze_0/bsp/include/../include/xil_macroback.h
C:/IMR_Projects/IMR/Softcore_SA/Bootloader_Softcore_SA/MB_SSA_BL_Platform/microblaze_0/standalone_microblaze_0/bsp/include/../include/xil_mem.h
C:/IMR_Projects/IMR/Softcore_SA/Bootloader_Softcore_SA/MB_SSA_BL_Platform/microblaze_0/standalone_microblaze_0/bsp/include/../include/xil_misc_psreset_api.h
C:/IMR_Projects/IMR/Softcore_SA/Bootloader_Softcore_SA/MB_SSA_BL_Platform/microblaze_0/standalone_microblaze_0/bsp/include/../include/xil_printf.h
C:/IMR_Projects/IMR/Softcore_SA/Bootloader_Softcore_SA/MB_SSA_BL_Platform/microblaze_0/standalone_microblaze_0/bsp/include/../include/xil_sutil.h
C:/IMR_Projects/IMR/Softcore_SA/Bootloader_Softcore_SA/MB_SSA_BL_Platform/microblaze_0/standalone_microblaze_0/bsp/include/../include/xil_testcache.h
C:/IMR_Projects/IMR/Softcore_SA/Bootloader_Softcore_SA/MB_SSA_BL_Platform/microblaze_0/standalone_microblaze_0/bsp/include/../include/xil_testio.h
C:/IMR_Projects/IMR/Softcore_SA/Bootloader_Softcore_SA/MB_SSA_BL_Platform/microblaze_0/standalone_microblaze_0/bsp/include/../include/xil_testmem.h
C:/IMR_Projects/IMR/Softcore_SA/Bootloader_Softcore_SA/MB_SSA_BL_Platform/microblaze_0/standalone_microblaze_0/bsp/include/../include/xil_types.h
C:/IMR_Projects/IMR/Softcore_SA/Bootloader_Softcore_SA/MB_SSA_BL_Platform/microblaze_0/standalone_microblaze_0/bsp/include/../include/xil_util.h
C:/IMR_Projects/IMR/Softcore_SA/Bootloader_Softcore_SA/MB_SSA_BL_Platform/microblaze_0/standalone_microblaze_0/bsp/include/../include/xintc.h
C:/IMR_Projects/IMR/Softcore_SA/Bootloader_Softcore_SA/MB_SSA_BL_Platform/microblaze_0/standalone_microblaze_0/bsp/include/../include/xintc_drv_config.h
C:/IMR_Projects/IMR/Softcore_SA/Bootloader_Softcore_SA/MB_SSA_BL_Platform/microblaze_0/standalone_microblaze_0/bsp/include/../include/xintc_i.h
C:/IMR_Projects/IMR/Softcore_SA/Bootloader_Softcore_SA/MB_SSA_BL_Platform/microblaze_0/standalone_microblaze_0/bsp/include/../include/xintc_l.h
C:/IMR_Projects/IMR/Softcore_SA/Bootloader_Softcore_SA/MB_SSA_BL_Platform/microblaze_0/standalone_microblaze_0/bsp/include/../include/xinterrupt_wrap.h
C:/IMR_Projects/IMR/Softcore_SA/Bootloader_Softcore_SA/MB_SSA_BL_Platform/microblaze_0/standalone_microblaze_0/bsp/include/../include/xio.h
C:/IMR_Projects/IMR/Softcore_SA/Bootloader_Softcore_SA/MB_SSA_BL_Platform/microblaze_0/standalone_microblaze_0/bsp/include/../include/xmem_config.h
C:/IMR_Projects/IMR/Softcore_SA/Bootloader_Softcore_SA/MB_SSA_BL_Platform/microblaze_0/standalone_microblaze_0/bsp/include/../include/xmicroblaze.h
C:/IMR_Projects/IMR/Softcore_SA/Bootloader_Softcore_SA/MB_SSA_BL_Platform/microblaze_0/standalone_microblaze_0/bsp/include/../include/xmicroblaze_config.h
C:/IMR_Projects/IMR/Softcore_SA/Bootloader_Softcore_SA/MB_SSA_BL_Platform/microblaze_0/standalone_microblaze_0/bsp/include/../include/xplatform_info.h
C:/IMR_Projects/IMR/Softcore_SA/Bootloader_Softcore_SA/MB_SSA_BL_Platform/microblaze_0/standalone_microblaze_0/bsp/include/../include/xspi.h
C:/IMR_Projects/IMR/Softcore_SA/Bootloader_Softcore_SA/MB_SSA_BL_Platform/microblaze_0/standalone_microblaze_0/bsp/include/../include/xspi_i.h
C:/IMR_Projects/IMR/Softcore_SA/Bootloader_Softcore_SA/MB_SSA_BL_Platform/microblaze_0/standalone_microblaze_0/bsp/include/../include/xspi_l.h
C:/IMR_Projects/IMR/Softcore_SA/Bootloader_Softcore_SA/MB_SSA_BL_Platform/microblaze_0/standalone_microblaze_0/bsp/include/../include/xstatus.h
C:/IMR_Projects/IMR/Softcore_SA/Bootloader_Softcore_SA/MB_SSA_BL_Platform/microblaze_0/standalone_microblaze_0/bsp/include/../include/xtimer_config.h
C:/IMR_Projects/IMR/Softcore_SA/Bootloader_Softcore_SA/MB_SSA_BL_Platform/microblaze_0/standalone_microblaze_0/bsp/include/../include/xtmrctr.h
C:/IMR_Projects/IMR/Softcore_SA/Bootloader_Softcore_SA/MB_SSA_BL_Platform/microblaze_0/standalone_microblaze_0/bsp/include/../include/xtmrctr_i.h
C:/IMR_Projects/IMR/Softcore_SA/Bootloader_Softcore_SA/MB_SSA_BL_Platform/microblaze_0/standalone_microblaze_0/bsp/include/../include/xtmrctr_l.h
C:/IMR_Projects/IMR/Softcore_SA/Bootloader_Softcore_SA/MB_SSA_BL_Platform/microblaze_0/standalone_microblaze_0/bsp/include/../include/xuartlite.h
C:/IMR_Projects/IMR/Softcore_SA/Bootloader_Softcore_SA/MB_SSA_BL_Platform/microblaze_0/standalone_microblaze_0/bsp/include/../include/xuartlite_i.h
C:/IMR_Projects/IMR/Softcore_SA/Bootloader_Softcore_SA/MB_SSA_BL_Platform/microblaze_0/standalone_microblaze_0/bsp/include/../include/xuartlite_l.h
C:/IMR_Projects/IMR/Softcore_SA/Bootloader_Softcore_SA/MB_SSA_BL_Platform/microblaze_0/standalone_microblaze_0/bsp/lib/libxiltimer.a
C:/IMR_Projects/IMR/Softcore_SA/Bootloader_Softcore_SA/MB_SSA_BL_Platform/microblaze_0/standalone_microblaze_0/bsp/include/../include/bspconfig.h
C:/IMR_Projects/IMR/Softcore_SA/Bootloader_Softcore_SA/MB_SSA_BL_Platform/microblaze_0/standalone_microblaze_0/bsp/include/../include/fsl.h
C:/IMR_Projects/IMR/Softcore_SA/Bootloader_Softcore_SA/MB_SSA_BL_Platform/microblaze_0/standalone_microblaze_0/bsp/include/../include/mb_interface.h
C:/IMR_Projects/IMR/Softcore_SA/Bootloader_Softcore_SA/MB_SSA_BL_Platform/microblaze_0/standalone_microblaze_0/bsp/include/../include/microblaze_exceptions_g.h
C:/IMR_Projects/IMR/Softcore_SA/Bootloader_Softcore_SA/MB_SSA_BL_Platform/microblaze_0/standalone_microblaze_0/bsp/include/../include/microblaze_exceptions_i.h
C:/IMR_Projects/IMR/Softcore_SA/Bootloader_Softcore_SA/MB_SSA_BL_Platform/microblaze_0/standalone_microblaze_0/bsp/include/../include/microblaze_instructions.h
C:/IMR_Projects/IMR/Softcore_SA/Bootloader_Softcore_SA/MB_SSA_BL_Platform/microblaze_0/standalone_microblaze_0/bsp/include/../include/microblaze_interrupts_i.h
C:/IMR_Projects/IMR/Softcore_SA/Bootloader_Softcore_SA/MB_SSA_BL_Platform/microblaze_0/standalone_microblaze_0/bsp/include/../include/pvr.h
C:/IMR_Projects/IMR/Softcore_SA/Bootloader_Softcore_SA/MB_SSA_BL_Platform/microblaze_0/standalone_microblaze_0/bsp/include/../include/sleep.h
C:/IMR_Projects/IMR/Softcore_SA/Bootloader_Softcore_SA/MB_SSA_BL_Platform/microblaze_0/standalone_microblaze_0/bsp/include/../include/xbasic_types.h
C:/IMR_Projects/IMR/Softcore_SA/Bootloader_Softcore_SA/MB_SSA_BL_Platform/microblaze_0/standalone_microblaze_0/bsp/include/../include/xcommon_drv_config.h
C:/IMR_Projects/IMR/Softcore_SA/Bootloader_Softcore_SA/MB_SSA_BL_Platform/microblaze_0/standalone_microblaze_0/bsp/include/../include/xdebug.h
C:/IMR_Projects/IMR/Softcore_SA/Bootloader_Softcore_SA/MB_SSA_BL_Platform/microblaze_0/standalone_microblaze_0/bsp/include/../include/xenv.h
C:/IMR_Projects/IMR/Softcore_SA/Bootloader_Softcore_SA/MB_SSA_BL_Platform/microblaze_0/standalone_microblaze_0/bsp/include/../include/xenv_standalone.h
C:/IMR_Projects/IMR/Softcore_SA/Bootloader_Softcore_SA/MB_SSA_BL_Platform/microblaze_0/standalone_microblaze_0/bsp/include/../include/xgpio.h
C:/IMR_Projects/IMR/Softcore_SA/Bootloader_Softcore_SA/MB_SSA_BL_Platform/microblaze_0/standalone_microblaze_0/bsp/include/../include/xgpio_i.h
C:/IMR_Projects/IMR/Softcore_SA/Bootloader_Softcore_SA/MB_SSA_BL_Platform/microblaze_0/standalone_microblaze_0/bsp/include/../include/xgpio_l.h
C:/IMR_Projects/IMR/Softcore_SA/Bootloader_Softcore_SA/MB_SSA_BL_Platform/microblaze_0/standalone_microblaze_0/bsp/include/../include/xiltimer.h
C:/IMR_Projects/IMR/Softcore_SA/Bootloader_Softcore_SA/MB_SSA_BL_Platform/microblaze_0/standalone_microblaze_0/bsp/include/../include/xil_assert.h
C:/IMR_Projects/IMR/Softcore_SA/Bootloader_Softcore_SA/MB_SSA_BL_Platform/microblaze_0/standalone_microblaze_0/bsp/include/../include/xil_cache.h
C:/IMR_Projects/IMR/Softcore_SA/Bootloader_Softcore_SA/MB_SSA_BL_Platform/microblaze_0/standalone_microblaze_0/bsp/include/../include/xil_cache_vxworks.h
C:/IMR_Projects/IMR/Softcore_SA/Bootloader_Softcore_SA/MB_SSA_BL_Platform/microblaze_0/standalone_microblaze_0/bsp/include/../include/xil_cryptoalginfo.h
C:/IMR_Projects/IMR/Softcore_SA/Bootloader_Softcore_SA/MB_SSA_BL_Platform/microblaze_0/standalone_microblaze_0/bsp/include/../include/xil_exception.h
C:/IMR_Projects/IMR/Softcore_SA/Bootloader_Softcore_SA/MB_SSA_BL_Platform/microblaze_0/standalone_microblaze_0/bsp/include/../include/xil_hal.h
C:/IMR_Projects/IMR/Softcore_SA/Bootloader_Softcore_SA/MB_SSA_BL_Platform/microblaze_0/standalone_microblaze_0/bsp/include/../include/xil_io.h
C:/IMR_Projects/IMR/Softcore_SA/Bootloader_Softcore_SA/MB_SSA_BL_Platform/microblaze_0/standalone_microblaze_0/bsp/include/../include/xil_macroback.h
C:/IMR_Projects/IMR/Softcore_SA/Bootloader_Softcore_SA/MB_SSA_BL_Platform/microblaze_0/standalone_microblaze_0/bsp/include/../include/xil_mem.h
C:/IMR_Projects/IMR/Softcore_SA/Bootloader_Softcore_SA/MB_SSA_BL_Platform/microblaze_0/standalone_microblaze_0/bsp/include/../include/xil_misc_psreset_api.h
C:/IMR_Projects/IMR/Softcore_SA/Bootloader_Softcore_SA/MB_SSA_BL_Platform/microblaze_0/standalone_microblaze_0/bsp/include/../include/xil_printf.h
C:/IMR_Projects/IMR/Softcore_SA/Bootloader_Softcore_SA/MB_SSA_BL_Platform/microblaze_0/standalone_microblaze_0/bsp/include/../include/xil_sutil.h
C:/IMR_Projects/IMR/Softcore_SA/Bootloader_Softcore_SA/MB_SSA_BL_Platform/microblaze_0/standalone_microblaze_0/bsp/include/../include/xil_testcache.h
C:/IMR_Projects/IMR/Softcore_SA/Bootloader_Softcore_SA/MB_SSA_BL_Platform/microblaze_0/standalone_microblaze_0/bsp/include/../include/xil_testio.h
C:/IMR_Projects/IMR/Softcore_SA/Bootloader_Softcore_SA/MB_SSA_BL_Platform/microblaze_0/standalone_microblaze_0/bsp/include/../include/xil_testmem.h
C:/IMR_Projects/IMR/Softcore_SA/Bootloader_Softcore_SA/MB_SSA_BL_Platform/microblaze_0/standalone_microblaze_0/bsp/include/../include/xil_types.h
C:/IMR_Projects/IMR/Softcore_SA/Bootloader_Softcore_SA/MB_SSA_BL_Platform/microblaze_0/standalone_microblaze_0/bsp/include/../include/xil_util.h
C:/IMR_Projects/IMR/Softcore_SA/Bootloader_Softcore_SA/MB_SSA_BL_Platform/microblaze_0/standalone_microblaze_0/bsp/include/../include/xintc.h
C:/IMR_Projects/IMR/Softcore_SA/Bootloader_Softcore_SA/MB_SSA_BL_Platform/microblaze_0/standalone_microblaze_0/bsp/include/../include/xintc_drv_config.h
C:/IMR_Projects/IMR/Softcore_SA/Bootloader_Softcore_SA/MB_SSA_BL_Platform/microblaze_0/standalone_microblaze_0/bsp/include/../include/xintc_i.h
C:/IMR_Projects/IMR/Softcore_SA/Bootloader_Softcore_SA/MB_SSA_BL_Platform/microblaze_0/standalone_microblaze_0/bsp/include/../include/xintc_l.h
C:/IMR_Projects/IMR/Softcore_SA/Bootloader_Softcore_SA/MB_SSA_BL_Platform/microblaze_0/standalone_microblaze_0/bsp/include/../include/xinterrupt_wrap.h
C:/IMR_Projects/IMR/Softcore_SA/Bootloader_Softcore_SA/MB_SSA_BL_Platform/microblaze_0/standalone_microblaze_0/bsp/include/../include/xio.h
C:/IMR_Projects/IMR/Softcore_SA/Bootloader_Softcore_SA/MB_SSA_BL_Platform/microblaze_0/standalone_microblaze_0/bsp/include/../include/xmem_config.h
C:/IMR_Projects/IMR/Softcore_SA/Bootloader_Softcore_SA/MB_SSA_BL_Platform/microblaze_0/standalone_microblaze_0/bsp/include/../include/xmicroblaze.h
C:/IMR_Projects/IMR/Softcore_SA/Bootloader_Softcore_SA/MB_SSA_BL_Platform/microblaze_0/standalone_microblaze_0/bsp/include/../include/xmicroblaze_config.h
C:/IMR_Projects/IMR/Softcore_SA/Bootloader_Softcore_SA/MB_SSA_BL_Platform/microblaze_0/standalone_microblaze_0/bsp/include/../include/xplatform_info.h
C:/IMR_Projects/IMR/Softcore_SA/Bootloader_Softcore_SA/MB_SSA_BL_Platform/microblaze_0/standalone_microblaze_0/bsp/include/../include/xspi.h
C:/IMR_Projects/IMR/Softcore_SA/Bootloader_Softcore_SA/MB_SSA_BL_Platform/microblaze_0/standalone_microblaze_0/bsp/include/../include/xspi_i.h
C:/IMR_Projects/IMR/Softcore_SA/Bootloader_Softcore_SA/MB_SSA_BL_Platform/microblaze_0/standalone_microblaze_0/bsp/include/../include/xspi_l.h
C:/IMR_Projects/IMR/Softcore_SA/Bootloader_Softcore_SA/MB_SSA_BL_Platform/microblaze_0/standalone_microblaze_0/bsp/include/../include/xstatus.h
C:/IMR_Projects/IMR/Softcore_SA/Bootloader_Softcore_SA/MB_SSA_BL_Platform/microblaze_0/standalone_microblaze_0/bsp/include/../include/xtimer_config.h
C:/IMR_Projects/IMR/Softcore_SA/Bootloader_Softcore_SA/MB_SSA_BL_Platform/microblaze_0/standalone_microblaze_0/bsp/include/../include/xtmrctr.h
C:/IMR_Projects/IMR/Softcore_SA/Bootloader_Softcore_SA/MB_SSA_BL_Platform/microblaze_0/standalone_microblaze_0/bsp/include/../include/xtmrctr_i.h
C:/IMR_Projects/IMR/Softcore_SA/Bootloader_Softcore_SA/MB_SSA_BL_Platform/microblaze_0/standalone_microblaze_0/bsp/include/../include/xtmrctr_l.h
C:/IMR_Projects/IMR/Softcore_SA/Bootloader_Softcore_SA/MB_SSA_BL_Platform/microblaze_0/standalone_microblaze_0/bsp/include/../include/xuartlite.h
C:/IMR_Projects/IMR/Softcore_SA/Bootloader_Softcore_SA/MB_SSA_BL_Platform/microblaze_0/standalone_microblaze_0/bsp/include/../include/xuartlite_i.h
C:/IMR_Projects/IMR/Softcore_SA/Bootloader_Softcore_SA/MB_SSA_BL_Platform/microblaze_0/standalone_microblaze_0/bsp/include/../include/xuartlite_l.h

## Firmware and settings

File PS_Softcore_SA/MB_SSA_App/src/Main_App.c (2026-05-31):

/******************************************************************************************************
 * @file            Main_App.c
 * @brief           This is the main application that runs.  Here are the specificis of what it does and
 *                  how it operates.
 *                  This is PS bear-metal based on the Xilinx (AMD) MicroBlaze softcore
 *                  There are two major components to this application: Audio Specturm FFT and Signal Spectrum FFT
 *                  Audio Spectrum FFT:
 *
 * ****************************************************************************************************
 * @author          Hab Collector (habco)\n
 *
 * @version         See Main_Support.h: FW_MAJOR_REV, FW_MINOR_REV, FW_TEST_REV
 *
 * @param Development_Environment \n
 * Hardware:        <Xilinx Artix A7> \n
 * IDE:             Vitis 2024.2 \n
 * Compiler:        GCC \n
 * Editor Settings: 1 Tab = 4 Spaces, Recommended Courier New 11
 *
 * @note            The associated header file provides MACRO functions for IO control
 *
 *                  This is an embedded application
 *                  It will be necessary to consult the reference documents to fully understand the code
 *                  It is suggested that the documents be reviewed in the order shown.
 *                    Schematic: 
 *                    IMR Engineering
 *                    IMR Engineering
 *
 * @copyright       IMR Engineering, LLC
 ********************************************************************************************************/

#include "Main_App.h"
#include <stdbool.h>
#include "xparameters.h"
#include "xtmrctr.h"
#include "xgpio.h"
#include "xintc.h"
#include "xil_exception.h"
#include "xuartlite.h"
#include "xspi.h"
#include "xil_printf.h"
#include "xstatus.h"
#include "xil_cache.h"
#include "ff.h"
#include "u8g2.h"
#include <stdio.h>
#include <math.h>
#include <string.h>
#include <sys/_stdint.h>
#include "AXI_Timer_PWM_Support.h"
#include "AXI_UART_Lite_Support.h"
#include "AXI_IRQ_Controller_Support.h"
#include "Terminal_Emulator_Support.h"
#include "AXI_QSPI_Support.h"
#include "AXI_IMR_PL_Revision.h"
#include "AXI_IMR_ADC_7476A_DUAL.h"
#include "IO_Support.h"
#include "Audio_File_API.h"
#include "Audio_SoftCore_SA.h"
#include "Signal_SoftCore_SA.h"
#include "MCP23S08_Driver.h"
#include "Water_Mark.h"
#include "Application_Display.h"
#include "AD9833_Driver.h"
#include "Hab_Types.h"


// STATIC FUNCTIONS
static void main_InitApplication(void);
static void main_WhileLoop(void);
static bool init_SoftCoreHandleCommon(Type_SoftCore_SA *Handle, uint32_t SampleFrequency);
static bool init_SoftCoreHandleAudio(Type_SoftCore_SA *Handle);
static bool init_SoftCoreHandleSignal(Type_SoftCore_SA *Handle);
static void processUserInput(Type_SoftCore_SA *SoftCore_SA);
static void processUser_IOX_Input(Type_SoftCore_SA *SoftCore_SA);
static void processUserArtyInput(void);
static void modeSwitch(Type_SoftCore_SA *SoftCore_SA);
static void selectSwitch(Type_SoftCore_SA *SoftCore_SA);
static void updateModeStatus_LED(void);
static void debugPrintGreeting(void);
// ISR Callbacks
static void TimerCallbackSampleRate_ISR(void) __attribute__((fast_interrupt));
static void TimerCallbackModeStatus_ISR(void) __attribute__((fast_interrupt));
static void ADC_7476A_Primary_ISR(void) __attribute__((fast_interrupt));


// AXI SUPPORT:
XGpio __attribute__ ((section (".Hab_Fast_Data"))) AXI_GPIO_Handle;
XTmrCtr __attribute__ ((section (".Hab_Fast_Data"))) AXI_SampleTimerHandle;
XTmrCtr __attribute__ ((section (".Hab_Fast_Data"))) AXI_ModeTimerHandle;
XTmrCtr __attribute__ ((section (".Hab_Fast_Data"))) AXI_PWM_Handle;
XUartLite __attribute__ ((section (".Hab_Fast_Data"))) AXI_UART_Handle;
XSpi __attribute__ ((section (".Hab_Fast_Data"))) AXI_SPI_UI_Handle;
XSpi __attribute__ ((section (".Hab_Fast_Data"))) AXI_SPI_USD_Handle;
XIntc __attribute__ ((section (".Hab_Fast_Data"))) AXI_IRQ_ControllerHandle;
Type_AXI_IMR_7476A_Handle __attribute__ ((section (".Hab_Fast_Data"))) AXI_IMR_7476A_Handle;


// NON AXI PERIPHERAL:
Type_SoftCore_SA __attribute__ ((section (".Hab_Fast_Data"))) SoftCore_SA;
Type_Display_SSD1309 __attribute__ ((section (".Hab_Fast_Data"))) Display_SSD1309; 
Type_MCP23S08_Driver __attribute__ ((section (".Hab_Fast_Data"))) IOX_1;
Type_MCP23S08_Driver __attribute__ ((section (".Hab_Fast_Data"))) IOX_2;
Type_AD9833_Driver __attribute__ ((section (".Hab_Fast_Data"))) AD9833_Handle;
u8g2_t __attribute__ ((section (".Hab_Fast_Data"))) U8G2; 
FATFS __attribute__ ((section (".Hab_Fast_Data"))) FatFs;
#define ADC_SAMPLE_SIZE 3
volatile uint16_t __attribute__ ((section (".Hab_Fast_Data"))) AnalogInputSignal[ADC_SAMPLE_SIZE];
volatile uint16_t __attribute__ ((section (".Hab_Fast_Data"))) BatteryVoltage[ADC_SAMPLE_SIZE];
uint32_t StackUsedWaterMark = 0;


// ENCODER SWITCH:
// #define TEST_AB
static bool EncoderIgnore_A = false;
static bool EncoderIgnore_B = false;
static bool EncoderInProgress_CW = false;
static bool EncoderInProgress_CCW = false;
static uint8_t Encoder_AB_Count = 0;


// EXTERNS
extern uint8_t __Hab_Fast_Text_start;
extern uint8_t __Hab_Fast_Text_end;
extern uint8_t __Hab_Fast_Text_load;



/********************************************************************************************************
* @brief This is the mian application - it is broken up into two parts - the main init and the main never
* ending loop.  Before the appliction starts Hab_Fast_Text is loaded from DDR to LBM.  To faciliate the .mcs
* image all loadable sections must be placed within DDR.  The watermark for debug purposes only is also seeded
*
* @author original: Hab Collector \n
*
* STEP 1: Load from DDR to LBM linker section .Hab_Fast_Text
* STEP 2: Seed the watermark for testing of stack overflow only - used in conjunction with getStackHighWaterMarkBytes
* STEP 3: Init the application
* STEP 4: Applicaiton Endless Loop 
********************************************************************************************************/
void mainApplication(void)
{
    // STEP 1: Load from DDR to LBM linker section .Hab_Fast_Text
    memcpy(&__Hab_Fast_Text_start, &__Hab_Fast_Text_load, (size_t)(&__Hab_Fast_Text_end - &__Hab_Fast_Text_start));
    
    // STEP 2: Seed the watermark for testing of stack overflow only - used in conjunction with getStackHighWaterMarkBytes
    seedStackForWaterMark();

    // STEP 3: Init the application
    main_InitApplication();

    // STEP 4: Applicaiton Endless Loop 
    main_WhileLoop();
}
// END OF the Main Application



/********************************************************************************************************
* @brief Init of main application peripherals, drivers, libaries, and handlers - code only runs once
*
* @author original: Hab Collector \n
*
* @note: Must be the first function call of mainApplication
* 
* STEP 1: Init AXI peripherals for use
* STEP 2: Init of libraries
* STEP 3: Init SoftCore SA Handle
* STEP 4: Welcome
********************************************************************************************************/
static void main_InitApplication(void)
{
    int AXI_Status;
    bool Status;
    FRESULT FileResult;
    uint16_t InitFailMode = 0;
    char PrintBuffer[MAX_PRINT_BUFFER] = {0};

    // STEP 1: Enable the instruction and data cache
    Xil_ICacheEnable();
    Xil_DCacheEnable();
    StackUsedWaterMark = getStackHighWaterMarkBytes();
    

    // STEP 2: Init AXI peripherals for use
    // Init AXI UART
    Status = init_UART_Lite(&AXI_UART_Handle, XPAR_AXI_UARTLITE_0_BASEADDR, POLLING, NULL, NULL, false);    
    if (Status != true)
        InitFailMode |= INIT_FAIL_UART;

    // Init AXI GPIO
    AXI_Status = XGpio_Initialize(&AXI_GPIO_Handle, XPAR_AXI_GPIO_0_BASEADDR);
    if (AXI_Status != XST_SUCCESS)
        InitFailMode |= INIT_FAIL_GPIO;
    init_GPIO(&AXI_GPIO_Handle);
    // XGpio_SetDataDirection(&AXI_GPIO_Handle, GPIO_INPUT_CHANNEL, 0xFFFF);     // Switches and push buttons as input
    // XGpio_SetDataDirection(&AXI_GPIO_Handle, GPIO_OUTPUT_CHANNEL, 0x0000);  

    // Init AXI Timer 1 as periodic
    Status = init_PeriodicTimer(&AXI_SampleTimerHandle, XPAR_AXI_TIMER_1_BASEADDR, XTC_TIMER_0, (u32)(XPAR_CPU_CORE_CLOCK_FREQ_HZ / DEFAULT_AUDIO_FREQUENCY), TimerCallbackSampleRate_ISR);
    if (Status != true)
        InitFailMode |= INIT_FAIL_TIMER_1;

    // Init AXI Timer 2 as periodic
    Status = init_PeriodicTimer(&AXI_ModeTimerHandle, XPAR_AXI_TIMER_2_BASEADDR, XTC_TIMER_0, MODE_TIMER_COUNT, TimerCallbackModeStatus_ISR);
    if (Status != true)
        InitFailMode |= INIT_FAIL_TIMER_2;

    // Init AXI Timer 3 as PWM
    Status = init_PWM(&AXI_PWM_Handle, XPAR_AXI_TIMER_3_BASEADDR);
    if (Status != true)
        InitFailMode |= INIT_FAIL_TIMER_3;

    // Init AXI SPI UI
    Status = init_QSPI_PollingMode(&AXI_SPI_UI_Handle, XPAR_AXI_QUAD_SPI_0_BASEADDR);
    if (Status != true)
        InitFailMode |= INIT_FAIL_SPI_0;

    // Init Custom IP ADC7476A
    Status = init_IMR_ADC_7476A_X2(&AXI_IMR_7476A_Handle, XPAR_IMR_ADC_7476A_X2_0_BASEADDR ,IMR_ADC_CLOCK_DIVIDER);
    if (Status != true)
        InitFailMode |= INIT_FAIL_ADC7476A;

    // Init AXI IRQ Controller (6x Steps)
    // Step 1 of 6 IRQ Controller setup: Init or IRQ Controller
    Status = init_IRQ_Controller(&AXI_IRQ_ControllerHandle, XPAR_AXI_INTC_0_BASEADDR);
    if (Status != true)
        InitFailMode |= INIT_FAIL_IRQ_CONTROLLER;
    // Step 2A of 6 IRQ Controller setup: AXI Audio Timer 
    Status = connectPeripheralFast_IRQ(&AXI_IRQ_ControllerHandle, XPAR_FABRIC_AXI_TIMER_1_INTR, TimerCallbackSampleRate_ISR, &AXI_SampleTimerHandle);
    if (Status != true)
        InitFailMode |= INIT_FAIL_IRQ_CONTROLLER;
    // Step 2B of 6 IRQ Controller setup: AXI Generic Timer 
    Status = connectPeripheralFast_IRQ(&AXI_IRQ_ControllerHandle, XPAR_FABRIC_AXI_TIMER_2_INTR, TimerCallbackModeStatus_ISR, &AXI_ModeTimerHandle);
    if (Status != true)
        InitFailMode |= INIT_FAIL_IRQ_CONTROLLER;
    // Step 2C of 6 Custom ADC IP: ADC7476A 2x Channel 
    Status = connectPeripheralFast_IRQ(&AXI_IRQ_ControllerHandle, ADC_7476A_X2_FABRIC_ID, ADC_7476A_Primary_ISR, &AXI_IMR_7476A_Handle);
    if (Status != true)
        InitFailMode |= INIT_FAIL_IRQ_CONTROLLER;
    // Step 3 IRQ Controller setup: Start
    Status = start_IRQ_Controller(&AXI_IRQ_ControllerHandle, XIN_REAL_MODE);
    if (Status != true)
        InitFailMode |= INIT_FAIL_IRQ_CONTROLLER;
    // Step 4 IRQ Controller setup: Enable Peripheral Interrupts
    enableDevice_IRQ_Controller(&AXI_IRQ_ControllerHandle, XPAR_FABRIC_AXI_TIMER_1_INTR);
    enableDevice_IRQ_Controller(&AXI_IRQ_ControllerHandle, XPAR_FABRIC_AXI_TIMER_2_INTR);
    // Step 5 IRQ Controller setup: Enable Exceptions
    enableExceptionHandling(&AXI_IRQ_ControllerHandle); 
    // Start / enable peripherals after IRQ Controller setup 
    startPeriodicTimer(&AXI_SampleTimerHandle, XTC_TIMER_0);
    startPeriodicTimer(&AXI_ModeTimerHandle, XTC_TIMER_0);
    pauseSpecificIRQ(&AXI_IRQ_ControllerHandle, XPAR_FABRIC_AXI_TIMER_1_INTR);
    StackUsedWaterMark = getStackHighWaterMarkBytes();


    // STEP 3: Init Drivers
    // IO Expander 1:
    Status = init_MCP23S08(&IOX_1, IOX_Reset, IOX_ChipSelect, SPI_InterfaceTrasmitReceive, sleep_ms_Wrapper, 
                           &AXI_SPI_UI_Handle, IOX_1_CS_NUMBER, IOX_1_DEVICE_ADDR, IOX_1_IO_DIRECTION, IOX_1_INPUT_POLARITY, IOX_1_IRQ_ON_CHANGE, 
                           IOX_1_IRQ_DEFAULT_VALUE, IOX_1_IRQ_CONTROL, IOX_1_CONFIGURATION, IOX_1_PULLUP, false, true);
    if (Status != true)
        InitFailMode |= INIT_FAIL_UI_IOX_1;
    // IO Expander 2:
    Status = init_MCP23S08(&IOX_2, IOX_Reset, IOX_ChipSelect, SPI_InterfaceTrasmitReceive, sleep_ms_Wrapper, 
                           &AXI_SPI_UI_Handle, IOX_2_CS_NUMBER, IOX_2_DEVICE_ADDR, IOX_2_IO_DIRECTION, IOX_2_INPUT_POLARITY, IOX_2_IRQ_ON_CHANGE, 
                           IOX_2_IRQ_DEFAULT_VALUE, IOX_2_IRQ_CONTROL, IOX_2_CONFIGURATION, IOX_2_PULLUP, false, false);
    if (Status != true)
        InitFailMode |= INIT_FAIL_UI_IOX_2;
    // DDS Waveform Generator:
    XGpio_DiscreteSet(&AXI_GPIO_Handle, GPIO_OUTPUT_CHANNEL, WAVEFORM_GEN_CS);
    Status = init_AD9833(&AD9833_Handle, &AXI_SPI_UI_Handle, AD9833_CS_NUMBER, AD9833_MCLK, SPI_InterfaceTrasmitReceive, WaveformGenChipSelect);
    if (Status != true)
        InitFailMode |= INIT_FAIL_UI_AD9833;


    // STEP 4: Init Middleware
    // Init FAT FS
    if (is_MicroSD_Inserted())
    {
        FileResult = f_mount(&FatFs, ROOT_PATH, 1);
        if (FileResult != FR_OK)
            InitFailMode |= INIT_FAIL_FAT_FS;
    }

    // Init Display
    Status = init_Display_SSD1309(&Display_SSD1309, &AXI_SPI_UI_Handle, DISPLAY_CS_NUMBER, XPAR_AXI_QUAD_SPI_0_FIFO_SIZE, displayResetOrRun, displayCommandOrData, SPI_InterfaceTrasmitReceive, displayChipSelect, sleep_ms_Wrapper, sleep_10us_Wrapper, &U8G2); 
    if (Status != true)
        InitFailMode |= INIT_FAIL_UI_DISPLAY;


    // STEP 5: Init Application
    // Init Application Common
    Status = init_SoftCoreHandleCommon(&SoftCore_SA, DEFAULT_AUDIO_FREQUENCY);
    if (Status != true)
        InitFailMode |= INIT_FAIL_SOFTCORE_SA;
    
    // Init Applicaiton Audio SA
    Status = init_SoftCoreHandleAudio(&SoftCore_SA);
    if (Status != true)
        InitFailMode |= INIT_FAIL_SOFTCORE_SA;

    // Init Applicaiton Signal SA
    Status = init_SoftCoreHandleSignal(&SoftCore_SA);
    if (Status != true)
        InitFailMode |= INIT_FAIL_SOFTCORE_SA;

    StackUsedWaterMark = getStackHighWaterMarkBytes();
    

    // STEP 6: Welcome
    terminal_ClearScreen();
    // Display to screen
    debugPrintGreeting();
    if (InitFailMode)
    {
        printBrightRed("Error on Init:\r\n");
        snprintf(PrintBuffer, sizeof(PrintBuffer), "Init Fail Code(s): 0x%04X\r\n\n",InitFailMode);
        printBrightRed(PrintBuffer);
        fflush(stdout);
        while(1);
    }
    else
    {
        xil_printf("Hello Hab, I am ready...\r\n\n");
        Type_PL_Revision PL_Revision = IMR_PL_RevisionGet(XPAR_IMR_PL_REVISION_0_BASEADDR);
        displayWelcomeScreen(&Display_SSD1309, FW_MAJOR_REV, FW_MINOR_REV, FW_TEST_REV, PL_Revision.Major, PL_Revision.Minor, PL_Revision.Test);
        sleep_ms_Wrapper(SPLASH_SCREEN_HOLD_TIME);     
    }

} // END OF main_InitApplication



/********************************************************************************************************
* @brief The application is bear metal - this is the contineous while loop that runs after main init. This
* loop in normal operatioon is non-existing.
*
* @author original: Hab Collector \n
*
* @note: Must be the sectond function call of mainApplication
* 
* STEP 1: Init peripherals for use
* STEP 2: Init of libraries
* STEP 3: Init SoftCore SA Handle
* STEP 4: Welcome
********************************************************************************************************/
static void main_WhileLoop(void)
{
    if (SoftCore_SA.Audio_SA.File.uSD_Present)
    {
        countFilesInDirectory(AUDIO_DIRECTORY, &SoftCore_SA.Audio_SA.File.DirectoryFileCount);
        getNextWavFile(AUDIO_DIRECTORY, SoftCore_SA.Audio_SA.File.Name, SoftCore_SA.Audio_SA.File.PathFileName, &SoftCore_SA.Audio_SA.File.Size, SoftCore_SA.Audio_SA.File.DirectoryFileCount);
        displayStaticHeaderAudio(&Display_SSD1309, DISPLAY_AUDIO_HEADING, SoftCore_SA.Audio_SA.File.Name, DISPLAY_AUDIO_STOP, 0, AUDIO_MIN_DB_DISPLAY);
    }
    
    while(1)
    {
        processUserInput(&SoftCore_SA);
        updateModeStatus_LED();

        if (SoftCore_SA.Mode == MODE_AUDIO_SA)
            audioSpectrumAnalyzer(&SoftCore_SA.Audio_SA, &SoftCore_SA.FFT, SoftCore_SA.UI_LED_Status);
        else
            signalSpectrumAnalyzer(&SoftCore_SA.Signal_SA, &SoftCore_SA.FFT);
    }

} // END OF main_WhileLoop



/********************************************************************************************************
* @brief Init of Soft Core Spectrum Analyzer Handle members specific to the common use
*
* @author original: Hab Collector \n
*
* @note: Must be init before main application can be called
* 
* @param Handle: Pointer to Soft Core SA structure
* @param SampleFrequency: Desired sample frequency it must meet Nyquist criteria x2
*
* @return True if init OK
*
* STEP 1: Set common handle members
********************************************************************************************************/
static bool init_SoftCoreHandleCommon(Type_SoftCore_SA *Handle, uint32_t SampleFrequency)
{
    // STEP 1: Set common handle members
    // Set LEDs
    Handle->UI_LED_Status = 0x00;   // All LEDs off
    // Set Mode
    Handle->Mode = MODE_AUDIO_SA;
    // FFT
    Handle->FFT.FrameReady = false;
    Handle->FFT.Size = FFT_SIZE;
    Handle->FFT.RBW = (float)SampleFrequency / FFT_SIZE;
    // Calculate the FFT Hann Window
    for (uint16_t N = 0; N < FFT_SIZE; N++)
    {
        Handle->FFT.HannWindow[N] = 0.5 * (1 - cos((2* M_PI * N)/(FFT_SIZE - 1)));
    }

    return(true);

} // END OF init_SoftCoreHandle



/********************************************************************************************************
* @brief Init of Soft Core Spectrum Analyzer Handle members specific to the Audio Mode function
*
* @author original: Hab Collector \n
*
* @note: Must be init before main application can be called
* @note: Requires prior init of FAT FS
* 
* @param Handle: Pointer to Soft Core SA structure
*
* @return True if init OK
*
* STEP 1: Set audio handle defaults
********************************************************************************************************/
static bool init_SoftCoreHandleAudio(Type_SoftCore_SA *Handle)
{
    // STEP 1: Set audio handle defaults
    // File
    Handle->Audio_SA.Enable = false;
    Handle->Audio_SA.File.uSD_Present = is_MicroSD_Inserted();
    Handle->Audio_SA.File.IsOpen = false;
    memset(Handle->Audio_SA.File.Name, 0x00, sizeof(Handle->Audio_SA.File.Name));
    memset(Handle->Audio_SA.File.PathFileName, 0x00, sizeof(Handle->Audio_SA.File.PathFileName));
    Handle->Audio_SA.File.DirectoryFileCount = 0;
    FRESULT FileResult = countFilesInDirectory(AUDIO_DIRECTORY, &Handle->Audio_SA.File.DirectoryFileCount);
    if ((FileResult != FR_OK) || (Handle->Audio_SA.File.DirectoryFileCount == 0))
        return(false);
    else
        return(true);
    // Action
    Handle->Audio_SA.AudioAction = AUDIO_ACTION_STOP;

} // END OF init_SoftCoreHandle



/********************************************************************************************************
* @brief Init of Soft Core Spectrum Analyzer Handle members specific to the Signal Mode function
*
* @author original: Hab Collector \n
*
* @note: Must be init before main application can be called
* 
* @param Handle: Pointer to Soft Core SA structure
*
* @return True if init OK
*
* STEP 1: Set audio handle defaults
********************************************************************************************************/
bool init_SoftCoreHandleSignal(Type_SoftCore_SA *Handle)
{
    Handle->Signal_SA.Enable = false;
    Handle->Signal_SA.Source = SIGNAL_ON_BOARD_OSCILLATOR;
    signalSelect(SIGNAL_ON_BOARD_OSCILLATOR);
    return(true);

} // END OF init_SoftCoreHandleSignal
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

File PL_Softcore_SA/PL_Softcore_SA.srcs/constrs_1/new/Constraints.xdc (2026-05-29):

# CONNECTIONS ON DIGILENT ARTY A7 BOARD THAT DO NOT FEED THROUGH TO THE SSA
# CLOCK AND EXTERNAL RESET
# Clock input (100 MHz single-ended clock on E3)
set_property PACKAGE_PIN E3 [get_ports CLK_100MHZ]
set_property IOSTANDARD LVCMOS33 [get_ports CLK_100MHZ]
# Reset input (PUSH BTN0 on D9)
set_property PACKAGE_PIN D9 [get_ports RST_PB]
set_property IOSTANDARD LVCMOS33 [get_ports RST_PB]
set_property PULLTYPE PULLDOWN [get_ports RST_PB]

# ARTY A7 TEST SWITCHS x2 AND PUSH BUTTONS x3
# Switch input (SW0 on A8)
set_property PACKAGE_PIN A8 [get_ports SW_0]
set_property IOSTANDARD LVCMOS33 [get_ports SW_0]
# Switch input (SW1 on C11)
set_property PACKAGE_PIN C11 [get_ports SW_1]
set_property IOSTANDARD LVCMOS33 [get_ports SW_1]
# Switch input (SW2 on C10)
#set_property PACKAGE_PIN C10 [get_ports {SW_2[0]}]
#set_property IOSTANDARD LVCMOS33 [get_ports {SW_2[0]}]
# TEST PUSH BUTTON INPUTS
# TEST 1 (PUSH BTN1 on C9)
set_property PACKAGE_PIN C9 [get_ports PB_1]
set_property IOSTANDARD LVCMOS33 [get_ports PB_1]
# TEST 2 (PUSH BTN2 on B9)
set_property PACKAGE_PIN B9 [get_ports PB_2]
set_property IOSTANDARD LVCMOS33 [get_ports PB_2]
# TEST 3 (PUSH BTN3 on B8)
set_property PACKAGE_PIN B8 [get_ports PB_3]
set_property IOSTANDARD LVCMOS33 [get_ports PB_3]
# Remove no_input_delay warnings - these inputs not tied to clock
set_false_path -from [get_ports PB_*]


# BOTH A7 DEDICATED AND CONNECTIONS THAT FEED THROUGH TO THE SSA: JA = J6, JB = J3, JC = J1, JD = J4 {A7_Connector = SSA_Connector)
# TIMER TEST SIGNALS OUTPUTS x2 ON ARTY A7 J4 CONNECTOR
# TIMER 1 output PIN TIM1 on A7 J4.2 U11
set_property PACKAGE_PIN U11 [get_ports {gpio2_io_o_0[0]}]
set_property IOSTANDARD LVCMOS33 [get_ports {gpio2_io_o_0[0]}]
# TIMER 2 output PIN TIM2 on A7 J4.4 V16
set_property PACKAGE_PIN V16 [get_ports {gpio2_io_o_0[1]}]
set_property IOSTANDARD LVCMOS33 [get_ports {gpio2_io_o_0[1]}]

# UART (AXI_UARTLITE_0)
# UART TX output PIN (A7 JD.7 E2) = SA J4.7
set_property PACKAGE_PIN E2 [get_ports UART_RX]
set_property IOSTANDARD LVCMOS33 [get_ports UART_RX]
# UART RX input PIN (A7 JD.8 D2) = SA J4.8
set_property PACKAGE_PIN D2 [get_ports UART_TX]
set_property IOSTANDARD LVCMOS33 [get_ports UART_TX]

#SSD1309 OLED DISPLAY (SHARES AXI_QUAD_SPI_0)
#CS OUPTUT PIN (A7 JD.1 D4) = SA J4.1 FW: DISPLAY_CS
set_property PACKAGE_PIN D4 [get_ports {gpio2_io_o_0[4]}]
set_property IOSTANDARD LVCMOS33 [get_ports {gpio2_io_o_0[4]}]
# Command(0) / Data(1) PIN (A7 JD.2 D3) = SA J4.2 FW: DISPLAY_CMD_DATA
set_property PACKAGE_PIN D3 [get_ports {gpio2_io_o_0[3]}]
set_property IOSTANDARD LVCMOS33 [get_ports {gpio2_io_o_0[3]}]
# RESET (ACTIVE LOW) PIN (A7 JD.3 F4) = SA J4.3 FW: DISPLAY_RESET_RUN
set_property PACKAGE_PIN F4 [get_ports {gpio2_io_o_0[2]}]
set_property IOSTANDARD LVCMOS33 [get_ports {gpio2_io_o_0[2]}]
#MOSI OUPTUT PIN (A7 JD.4 F3) = SA J4.4
set_property PACKAGE_PIN F3 [get_ports DISPLAY_MOSI]
set_property IOSTANDARD LVCMOS33 [get_ports DISPLAY_MOSI]
#SCLK OUTPUT PIN (A7 JD.10 G2) = SA J4.10
set_property PACKAGE_PIN G2 [get_ports DISPLAY_SCLK]
set_property IOSTANDARD LVCMOS33 [get_ports DISPLAY_SCLK]
#MISO INPUT PIN ***NOT USED***
# DISPLAY_CSn PIN (A7 CK_IO5 ON J4.11) ***NOT USED - GPIO gpio2_io_o_0[4] is used instead***
set_property PACKAGE_PIN T14 [get_ports {IOX_CSn[0]}]
set_property IOSTANDARD LVCMOS33 [get_ports {IOX_CSn[0]}]

#IO EXPANDER X2 AND WAVEFORM GENERATOR X1 (SHARES AXI_QUAD_SPI_0)
#COMMON SCLK OUTPUT PIN (A7 JC.1 U12) = SA J1.1
set_property PACKAGE_PIN U12 [get_ports IOX_SCLK]
set_property IOSTANDARD LVCMOS33 [get_ports IOX_SCLK]
#COMMON MOSI OUTPUT PIN (A7 JC.2 V12) = SA J1.2
set_property PACKAGE_PIN V12 [get_ports IOX_MOSI]
set_property IOSTANDARD LVCMOS33 [get_ports IOX_MOSI]
#IOX MISO INPUT PIN (A7 JC.3 V10 = SA J1.3)
set_property PACKAGE_PIN V10 [get_ports IOX_MISO]
set_property IOSTANDARD LVCMOS33 [get_ports IOX_MISO]
#IOX RESET OUTPUT PIN (A7 JC.4 V11) = SA J1.4
set_property PACKAGE_PIN V11 [get_ports {gpio2_io_o_0[8]}]
set_property IOSTANDARD LVCMOS33 [get_ports {gpio2_io_o_0[8]}]
#IO EXPANDER 1 CS PIN (A7 JC.10 U13) = SA J1.10
set_property PACKAGE_PIN U13 [get_ports {IOX_CSn[1]}]
set_property IOSTANDARD LVCMOS33 [get_ports {IOX_CSn[1]}]
#IO EXPANDER 2 CS PIN (A7 JC.9 T13) = SA J1.9
set_property PACKAGE_PIN T13 [get_ports {IOX_CSn[2]}]
set_property IOSTANDARD LVCMOS33 [get_ports {IOX_CSn[2]}]
#IO EXPANDER 2 IRQ PIN (A7 JC.8 V14) = SA J1.8
set_property PACKAGE_PIN V14 [get_ports IOX_2_IRQ]
set_property IOSTANDARD LVCMOS33 [get_ports IOX_2_IRQ]
#WAVEFORM GENERATOR CS / FSYNC PIN (A7 JB.10 J15) = SA J3.10
set_property PACKAGE_PIN J15 [get_ports {gpio2_io_o_0[10]}]
set_property IOSTANDARD LVCMOS33 [get_ports {gpio2_io_o_0[10]}]
#WAVEFORM GENERATOR MCLK PIN (A7 JA.7 D13) = SA J6.7
set_property PACKAGE_PIN D13 [get_ports MCLK]
set_property IOSTANDARD LVCMOS33 [get_ports MCLK]
set_property DRIVE 8 [get_ports MCLK]
set_property SLEW SLOW [get_ports MCLK]
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

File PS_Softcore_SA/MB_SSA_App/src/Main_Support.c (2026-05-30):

/******************************************************************************************************
 * @file            Main_Support.c
 * @brief           A collection of functions relevant to supporting both the main test and main application
 * ****************************************************************************************************
 * @author          Hab Collector (habco)\n
 *
 * @version         See Main_Support.h: FW_MAJOR_REV, FW_MINOR_REV, FW_TEST_REV
 *
 * @param Development_Environment \n
 * Hardware:        <Xilinx Artix A7> \n
 * IDE:             Vitis 2024.2 \n
 * Compiler:        GCC \n
 * Editor Settings: 1 Tab = 4 Spaces, Recommended Courier New 11
 *
 * @note            The associated header file provides MACRO functions for IO control
 *
 *                  This is an embedded application
 *                  It will be necessary to consult the reference documents to fully understand the code
 *                  It is suggested that the documents be reviewed in the order shown.
 *                    Schematic: 
 *                    IMR Engineering
 *                    IMR Engineering
 *
 * @copyright       IMR Engineering, LLC
 ********************************************************************************************************/

#include "Main_Support.h"
#include "IO_Support.h"
#include "xgpio.h"
#include "xuartlite.h"
#include "xtmrctr.h"
#include "sleep.h"

extern XGpio AXI_GPIO_Handle;
#define GPIO_Handle AXI_GPIO_Handle


volatile uint32_t __attribute__ ((section (".Hab_Mixed_Data"))) ReceivedBytes = 0;
volatile uint8_t __attribute__ ((section (".Hab_Mixed_Data"))) RxDataBuffer[RX_BUFFER_SIZE] = {0};


/********************************************************************************************************
* @brief Blocking delay by tens of us
*
* @author original: Hab Collector \n
*
* @note: Requires BSP xiltimer to be active with dedicated timer for use
* 
* @param WaitTime: Number of 10s of us to wait: A value of 10 would wait 100us
*
* STEP 1: Wait 10s of us
********************************************************************************************************/
void sleep_10us_Wrapper(uint32_t WaitTime)
{
    // STEP 1: Wait 10s of us
    for (uint32_t Time = 0; Time < WaitTime; Time++)
    {
        usleep(10);
    }

} // END OF sleep_10us_Wrapper



/********************************************************************************************************
* @brief Blocking delay by milliseconds
*
* @author original: Hab Collector \n
*
* @note: Requires BSP xiltimer to be active with dedicated timer for use
* 
* @param WaitTime: Number of in milliseconds
********************************************************************************************************/
void sleep_ms_Wrapper(uint32_t WaitTime)
{
    msleep(WaitTime);

} // END OF sleep_ms_Wrapper



/********************************************************************************************************
* @brief This is communication for use with the AXI QSPI interface that interfaces to the: display (0 not used)
* IO expanders (1 and 2), and Waveform Generator (3 not used).  As this is SPI it is full duplex transmit and 
* receive.  It is passed by reference for use with the display and IO drivers.  This will generally be referred 
* to as the UI SPI Tx Rx.  The interface can optionally be used with or wihout the QUAD SPI chip select.  
* When using the Quad SPI Chip select External_CS_Enable should be NULL.  When using a custom chip select
* External_CS_Enable must be populated with a valid function.  
*
* @author original: Hab Collector \n
*
* @note: SPI must be configured in polling mode
* @note: If using the SPI chip select or not the PL block diagram must still constrain all CS to an FPGA pin
*
* @param SPI_UI_Handle: Pointer to QSPI handle
* @param ChipSelect_N: Chip Select associate with device first device is 1
* @param TxBuffer: The transmit buffer - information to send
* @param RxBuffer: The receive buffer - information to receive - this can be NULL if nothing is expected back
* @param BytesToTransfer: Bytes to both transmit and receive (always equal for SPI)
* @param UseNegSpiClk: Sets the polarity of the SPI Clock = data active on positive or negative clock edge
* @param External_CS_Enable: If not using the CS of the AXI Quad SPI IP then this function pointer if not NULL should be used
*
* @return: True if transmission was successful
*
* STEP 1: Simple test
* STEP 2: Select the correct slave device
* STEP 3: Transfer the data
* STEP 4: Transfer the data - on error attempt a retransmit
* STEP 5: Deselect all slave devices
********************************************************************************************************/
bool SPI_InterfaceTrasmitReceive(XSpi *SPI_UI_Handle, uint8_t ChipSelect_N, uint8_t *TxBuffer, uint8_t *RxBuffer, uint32_t BytesToTransfer, bool UseNegSpiClk, CS_FunctionPointer External_CS_Enable)
{
    // STEP 1: Simple test
    if ((SPI_UI_Handle == NULL) || (ChipSelect_N == 0))
        return(false);

    // Set target options
    uint32_t TargetOptions = XSP_MASTER_OPTION | XSP_MANUAL_SSELECT_OPTION;
    if (UseNegSpiClk)
        TargetOptions |= XSP_CLK_ACTIVE_LOW_OPTION;
    XSpi_SetOptions(SPI_UI_Handle, TargetOptions);

    // STEP 2: Select the correct slave device
    if (External_CS_Enable == NULL)
        XSpi_SetSlaveSelect(SPI_UI_Handle, ChipSelect_N);
    else
        External_CS_Enable(true);

    // STEP 3: Assign the RxBuffer
    int AXI_Status;
    uint8_t DummyRxBuffer[BytesToTransfer];
    uint8_t *RxBufferPtr = (RxBuffer == NULL)? DummyRxBuffer : RxBuffer;

    // STEP 4: Transfer the data - on error attempt a retransmit
    AXI_Status = XSpi_Transfer(SPI_UI_Handle, TxBuffer, RxBufferPtr, BytesToTransfer);    
    if (AXI_Status != XST_SUCCESS)  // Something went wrong try again
    {
        // Reset the SPI and deselect the chip
        XSpi_Reset(SPI_UI_Handle);
        if (External_CS_Enable == NULL)
            XSpi_SetSlaveSelect(SPI_UI_Handle, ChipSelect_N);
        else
            External_CS_Enable(false);
        // Set the options and restart
        XSpi_SetOptions(SPI_UI_Handle,TargetOptions);
        XSpi_Start(SPI_UI_Handle);
        XSpi_IntrGlobalDisable(SPI_UI_Handle);
        // Enable chip select and repeat transfer
        if (External_CS_Enable == NULL)
            XSpi_SetSlaveSelect(SPI_UI_Handle, ChipSelect_N);
        else
            External_CS_Enable(true);
        AXI_Status = XSpi_Transfer(SPI_UI_Handle, TxBuffer, RxBufferPtr, BytesToTransfer);        
    }

    // STEP 5: Deselect all slave devices
    if (External_CS_Enable == NULL)
        XSpi_SetSlaveSelect(SPI_UI_Handle, 0x00);
    else
        External_CS_Enable(false);

    return(AXI_Status == XST_SUCCESS);

} // END OF SPI_InterfaceTrasmitReceive

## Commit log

2026-04-10 Initial commit for SoftCore SA Phase 2
    [BOM_PartType-Softcore_SA_HW.xlsx, PinMap_ArtyA7_To_SSA.xlsx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]
2026-04-13 Changes to xilinx project so I can debug. Created P2 Hardware in Circuit Studio to beging editing
    [SoftCore_SA_P1.SchDoc, SoftCore_SA_P2.SchDoc, SoftCore_SA_P2_PG1.SchDoc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]
2026-05-04 Mass changes to schematic pages - removal of components and traces from PCM - not yet attempted to update
    [BOM_PartType-Softcore_SA_HW.xlsx, FFT_Zoom_DDC.xlsx, PinMap_ArtyA7_To_SSA.xlsx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]
2026-05-04 Additional schematic changes before PCB Update
    [SoftCore_SA_P2_PG4.SchDoc, SoftCore_SA_P2_PG5.SchDoc, SoftCore_SA_P2_PG6.SchDoc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]
2026-05-06 Placement on PCB completed. Minor schematic changes
    [SoftCore_SA_P2_PG2.SchDoc, SoftCore_SA_P2_PG4.SchDoc, SoftCore_SA_P2_PG5.SchDoc]
2026-05-06 Updates to schematics and PCB - REF DES renumbered and most of PCB DRC free
    [SoftCore_SA_P2_PG2.SchDoc, SoftCore_SA_P2_PG3.SchDoc, SoftCore_SA_P2_PG4.SchDoc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]
2026-05-07 Routing done and clean up done - clean DRC - just letting it sit will review over the next 3 days before I release
    [PinMap_ArtyA7_To_SSA.xlsx, SoftCore_SA_P2_PG3.SchDoc, SoftCore_SA_P2_PG5.SchDoc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]
2026-05-09 Minor changes to text in SCH and PCB. DRC Good - Output Generation Complete
    [BOM_PartType-Softcore_SA_P2_HW.xlsx, PinMap_ArtyA7_To_SSA.xlsx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]
2026-05-14 Update to PCB - no real change - release for fab
    [PinMap_ArtyA7_To_SSA.xlsx]
2026-05-25 Changes to PL Block Diagram and constraints file as well as changes to FW to account for change in HW and make work so I can beging working on FW. Currently debugging encoder rotation - overall boot 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
    [PinMap_ArtyA7_To_SSA.xlsx, SoftCore_SA_P2_PG5.SchDoc]
2026-05-26 Changes to rotary encoder - still not working as it should
    [Main_App.c]
2026-05-26 More changes to encoder
2026-05-27 Encoder working ok. Added code for AD9833 - not working. Issue with CS being the inverted signal of CS for IOX1. NumberSalveBits of QSPI is 3 it really should be 4
    [AD9833_Driver.c, Constraints.xdc, MCP23S08_Driver.c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]
2026-05-28 Changes to AD9833 driver - minor change and added header comments - still not working due to chip select issue
    [AD9833_Driver.c, Main_Support.c]
2026-05-29 Fix AD9833 working, but need to make userInterfaceTrasmitReceive more agnostic to specific channels
    [Constraints.xdc, Main_App.c, Main_Support.c]
2026-05-30 Many changes to refactor the way the generic spi tx rx function works - a few more changes to go
    [PinMap_ArtyA7_To_SSA.xlsx]
2026-05-30 Clean up of generic spi tx and rx completed
    [PinMap_ArtyA7_To_SSA.xlsx]
2026-05-31 Added my custom RTL debounce IP to PB_3 input from Arty. All works. Next back to working on ADC interleave
